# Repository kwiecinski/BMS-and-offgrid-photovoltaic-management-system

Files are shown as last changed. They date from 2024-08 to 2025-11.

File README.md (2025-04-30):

# Offgrid Photovoltaic Management System 
 ### Project contains:
 #### A. Power and mechanical part:

  1. [ Photovoltaic modules](#1-photovoltaic-modules)  
  2. [ Concrete base mounting](#2-concrete-base-mounting)  
  3. [ Metalworking and welding mounting bases and angle bar](#3-metalworking-and-welding-mounting-bases-and-angle-bar)  
  4. [ Painting mounting base, angle bars and perforated profiles](#4-painting-mounting-base-angle-bars-and-perforated-profiles)  
  5. [ PV mountings to perforated profiles](#5-pv-mountings-to-perforated-profiles)  
  6. [ Assembly of PV installation](#6-assembly-of-pv-installation)  
  7. [ Fully assembled PV installation](#7-fully-assembled-pv-installation)<br>
  8. [ Underground Cable Installation and Connection to the Building](#8-underground-cable-installation-and-connection-to-the-building)
 
B. [EASUN inverter - description, installation schematic and wiring](#easun-inverter---description-installation-and-wiring)
#### C. Managemenet system part:
- [BMS for lead-acid batteries](#bms-for-lead-acid-batteries) - equalize battery, protect from large charge/discharge currents, montors battery state (temp, voltage)
- [ESP32 Master module](#esp32-master-module) - it communicate with EASUN  converter, BMS, Homa Assistant, Energy Meters and sensor. Supervise all system work propertly.
- [Home Assistant integration](#home-assistant-integration) - integrate ESP Master module with HA for easy and compact managment (local and remote access)
- [Power Tracking module](#power-tracking-module) - it is used to regulate heater power accordingly to avaible energy from PV

## PV panels connection and DIY Ground Mount structure 

### 1. Photovoltaic modules
The photovoltaic modules I used in my PV installation are Trina Solar TSM-245. These are used panels that I purchased for around $40 each. The installation consists of 8 modules connected in series.

[📄 **Trina Solar TSM-245 datasheet**](docs/datasheets/TSM-PC05_trinasolar.pdf)

<table>
  <tr>
    <td align="center">
      <a href="docs\photos\ground-mount-structure\solar-panel-technical-data.jpg">
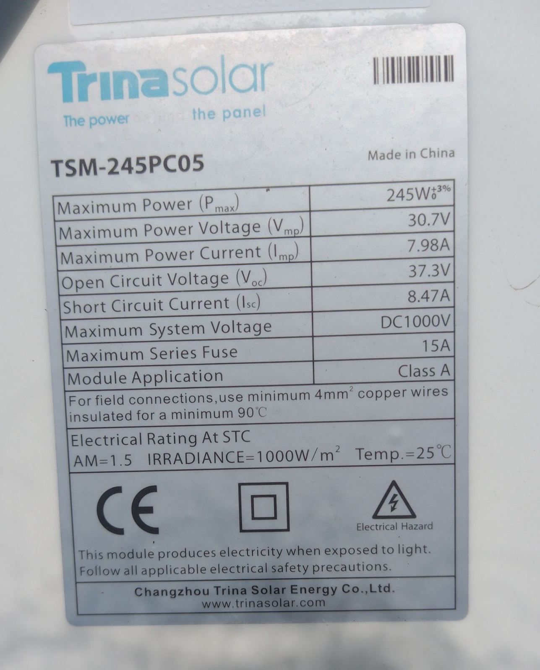
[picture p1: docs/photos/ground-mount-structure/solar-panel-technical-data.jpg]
        
      </a><br />
      <sub>PV module TSM-245 - technical data</sub>
    </td>
    <td align="center">
      <a href="docs\photos\ground-mount-structure\solar-panel-diodes.jpg">
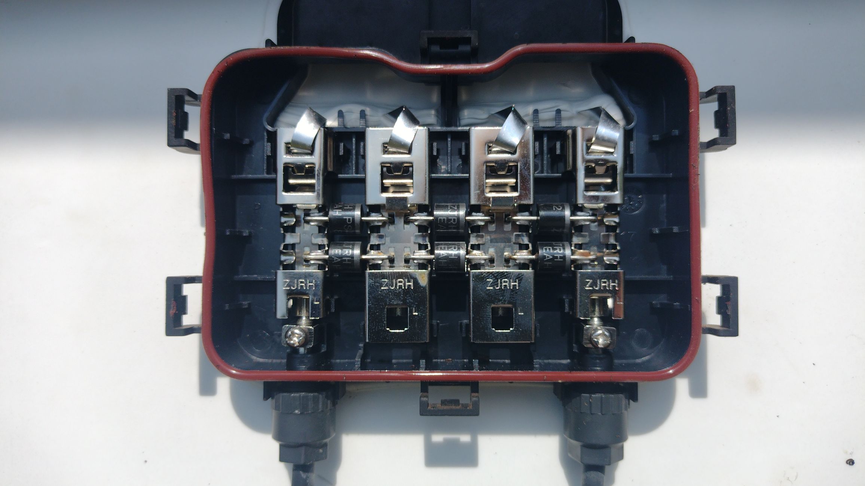
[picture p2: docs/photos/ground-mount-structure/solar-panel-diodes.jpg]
        
      </a><br />
      <sub>PV module TSM-245 - internal diode wiring</sub>
    </td>
  </tr>
</table>

<table>
  <tr>
    <td align="center">
      <a href="docs\photos\ground-mount-structure\solar-panel-front.jpg">
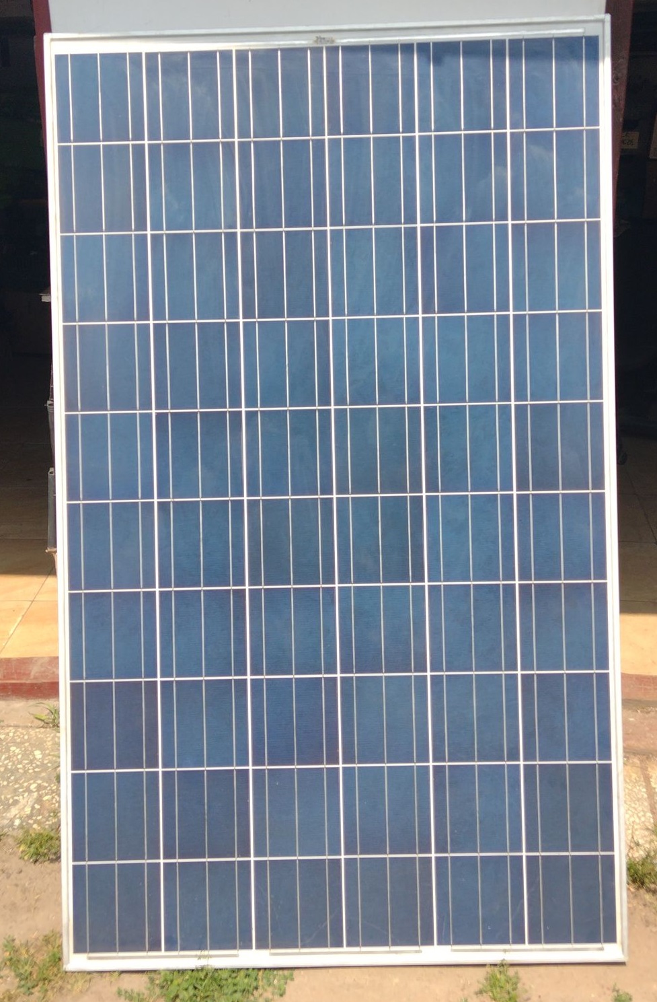
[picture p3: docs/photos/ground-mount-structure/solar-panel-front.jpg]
        
      </a><br />
      <sub>PV module TSM-245 - front</sub>
    </td>
    <td align="center">
      <a href="docs\photos\ground-mount-structure\solar-panel-back.jpg">
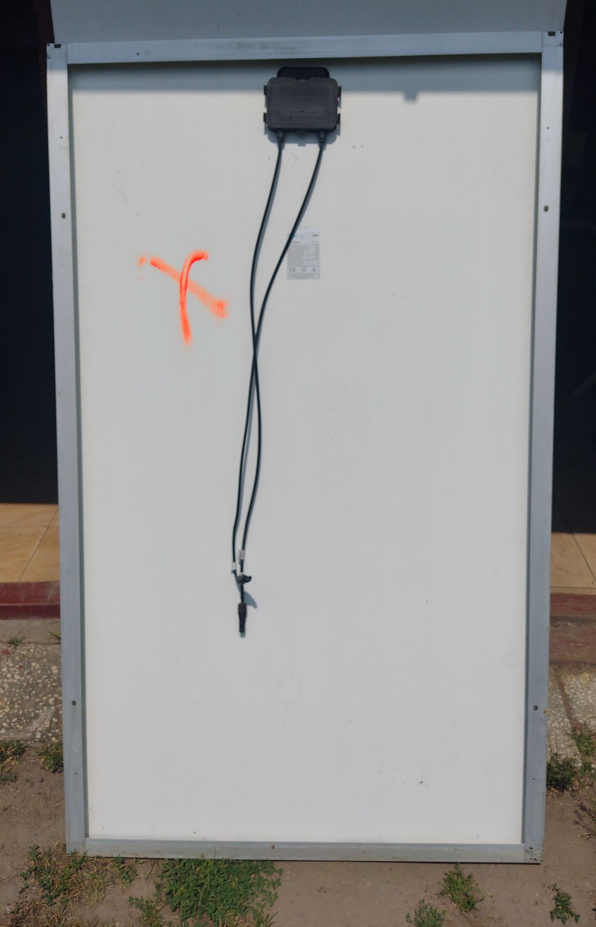
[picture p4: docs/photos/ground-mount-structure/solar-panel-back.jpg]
        
      </a><br />
      <sub>PV module TSM-245 - back</sub>
    </td>
  </tr>
</table>

The first stage was marking the mounting points for the mouting base structure. The entire construction has eight support points. After digging holes in the ground, they were filled with concrete, and concrete bases with reinforcement were embedded in them. I had plenty of these as production waste from the company where I work. They are typically used for mounting lightning protection masts on flat building roofs.

Inside each base, there is reinforcement and four M16 threads. I modified the bases by drilling holes on the opposite side, and I welded additional reinforcement to the bottom using scrap metal, which helps to improve the structural stability.

Before mounting the structure to the concrete bases, the contact surfaces were coated with a bituminous compound to prevent corrosion.

### 2. Concrete base mounting

<table>
  <tr>
    <td align="center" colspan="2">
      <a href="docs\photos\ground-mount-structure\concrete-fixing-with-reinforcement.jpg">
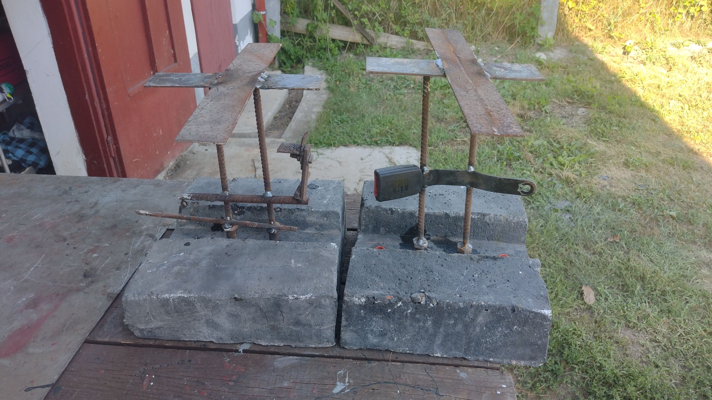
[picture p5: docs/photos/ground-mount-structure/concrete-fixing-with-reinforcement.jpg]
        
      </a><br />
      <sub>Concrete base with reinforcement</sub>
    </td>
  </tr>
  <tr>
    <td align="center">
      <a href="docs/photos/ground-mount-structure/concrete_base.jpg">
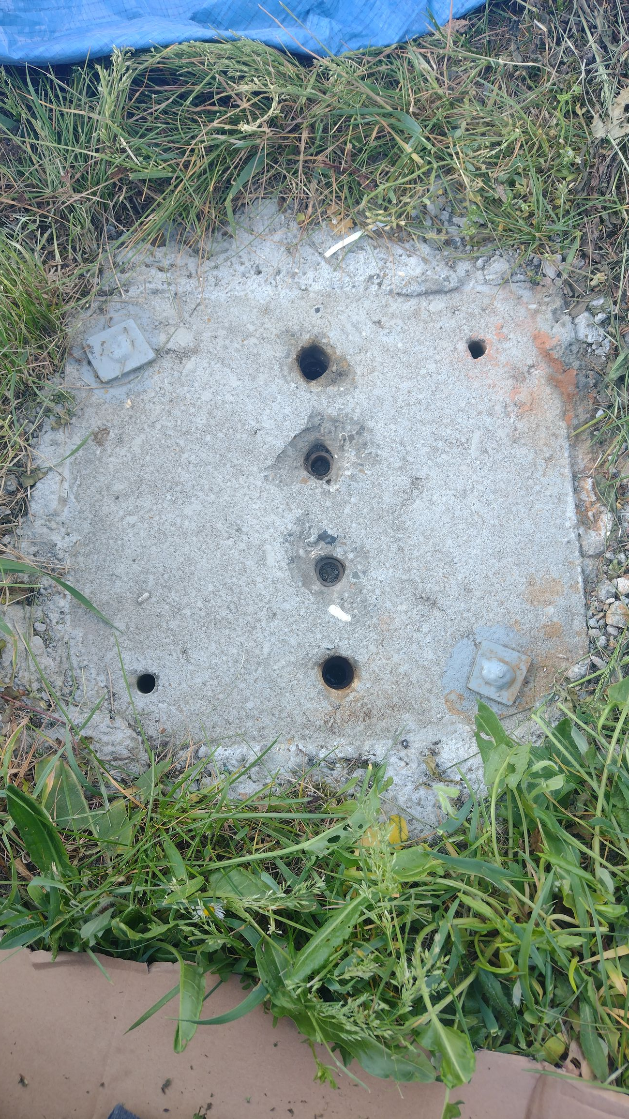
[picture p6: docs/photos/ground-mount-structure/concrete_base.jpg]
        
      </a><br />
      <sub>Concrete base with mounting thread</sub>
    </td>
    <td align="center">
      <a href="docs/photos/ground-mount-structure/concreete-with-bitumen.jpg">
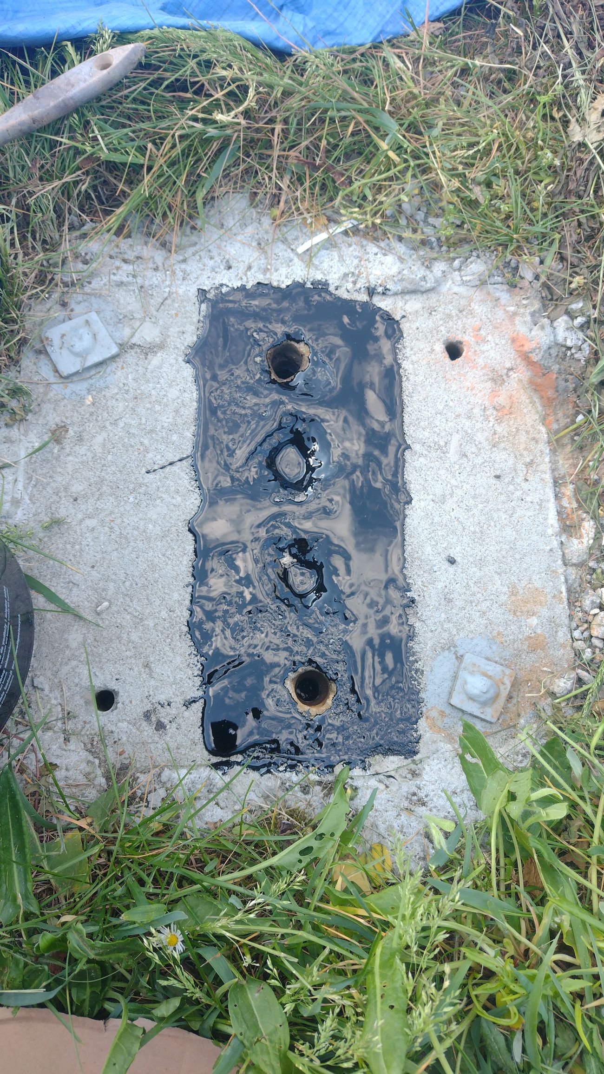
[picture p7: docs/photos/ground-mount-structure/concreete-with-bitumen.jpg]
        
      </a><br />
      <sub>Concrete base with bitumen</sub>
    </td>
  </tr>
</table>
<br>

Visible in the photo below is a set of four steel mounting bases of varying heights, with welded pipes and mounting plates. Each element was made with consideration for uneven ground, that is why there are different pipe lengths. Each base has a bottom plate with holes for M16 bolts, intended for anchoring to a concrete base. On the table next to them lies a long steel angle bar, which was welded from several sections. After welding, the elements were ground down. The photo was taken after the mechanical work was completed, during surface preparation for painting. 
All the steel used for building the PV mouting structure comes from scrap yard.

### 3. Metalworking and welding mounting bases and angle bar
<br>
<table>
  <tr>
    <td align="center" colspan="2">
      <a href="docs\photos\ground-mount-structure\steel-workshop-and-painting-12.jpg">
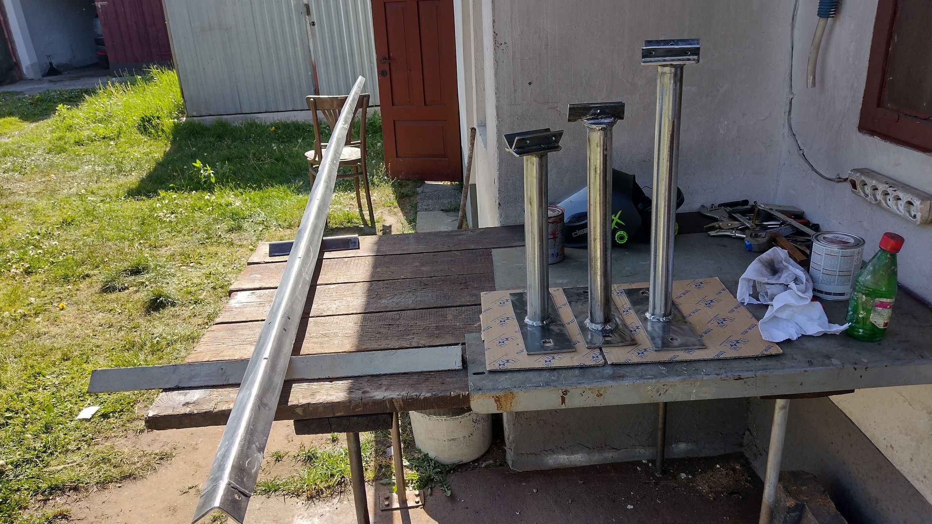
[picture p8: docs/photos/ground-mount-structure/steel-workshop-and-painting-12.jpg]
        
      </a><br />
      <sub>Metalworking and welding mounting bases and angle bar</sub>
    </td>
  </tr>
  <tr>
    <td align="center" colspan="2">
      <a href="docs\photos\ground-mount-structure\steel-workshop-and-painting-13.jpg">
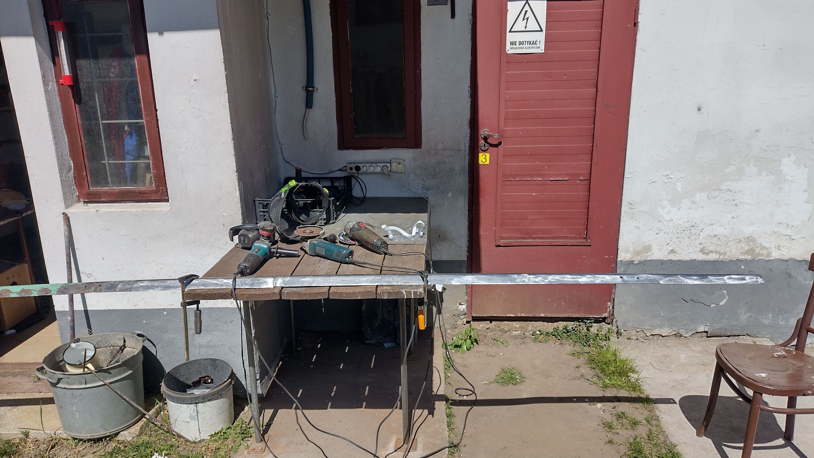
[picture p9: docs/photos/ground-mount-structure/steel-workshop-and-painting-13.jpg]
        
      </a><br />
      <sub>Steel angle bar before painting</sub>
    </td>
  </tr>
    <tr>
    <td align="center" colspan="2">
      <a href="docs\photos\ground-mount-structure\steel-workshop-and-painting-14.jpg">
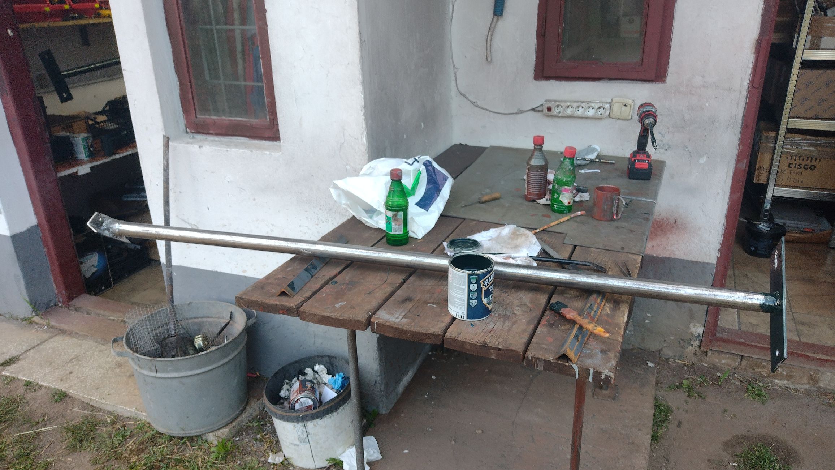
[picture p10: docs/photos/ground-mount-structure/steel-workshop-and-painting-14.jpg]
        
      </a><br />
      <sub>Longer mounting base  while painting</sub>
    </td>
  </tr>
</table>

Longer mounting base are responsible for the solar incidence angle which in this case is 40 degrees
### 4. Painting mounting base, angle bars and perforated profiles
<table>
  <tr>
    <td align="center" colspan="2">
      <a href="docs\photos\ground-mount-structure\steel-workshop-and-painting-11.jpg">
        
      <div style="width: 200px;">
        <a href="docs/photos/ground-mount-structure/steel-workshop-and-painting-11.jpg">
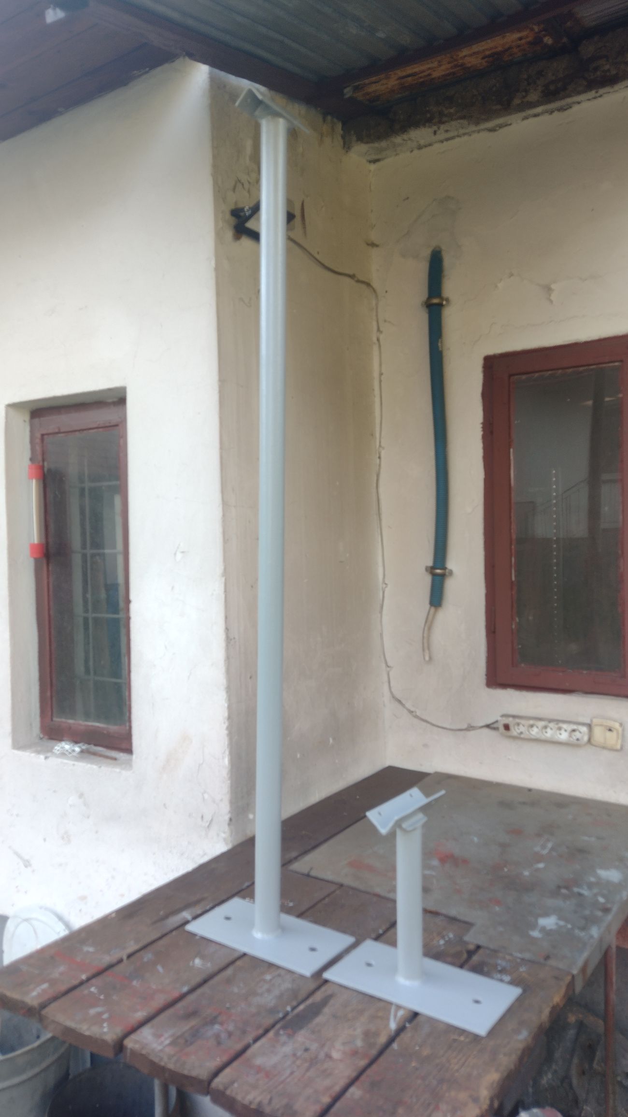
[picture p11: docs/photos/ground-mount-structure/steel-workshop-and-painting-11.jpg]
          
        </a>
        <div style="text-align: center;">
          <sub>Shorter and longer mounting base after painting</sub>
        </div>
      </div>
    </td>
  </tr>
  <tr>
    <td colspan="2" style="text-align: left;">
      <div style="width: 410px;">
        <a href="docs/photos/ground-mount-structure/steel-workshop-and-painting-10.jpg">
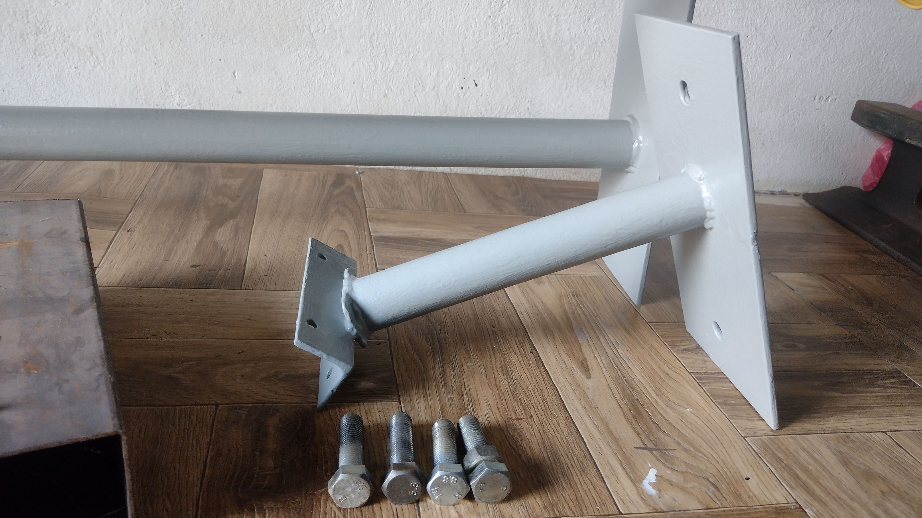
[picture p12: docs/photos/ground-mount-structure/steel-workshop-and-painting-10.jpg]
          
        </a>
        <div style="text-align: center;">
          <sub>Shorter mounting base after painting</sub>
        </div>
      </div>
    </td>
  </tr>
  <tr>
    <td colspan="2" style="text-align: left;">
      <div style="width: 410px;">
        <a href="docs/photos/ground-mount-structure/steel-workshop-and-painting-01.jpg">
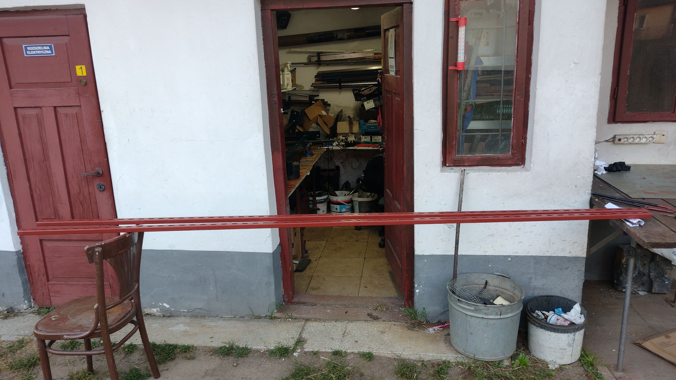
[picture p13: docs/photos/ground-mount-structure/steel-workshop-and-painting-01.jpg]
          
        </a>
        <div style="text-align: center;">
          <sub>Perforated profiles, often used for fixing cable tray systems, <br>turned out to be ideal as internal panel brackets. <br>Since they are galvanized, they must be painted <br>with zinc-compatible paint.</sub>
        </div>
      </div>
    </td>
  </tr>
  <tr>
    <td colspan="2" style="text-align: left;">
      <div style="width: 410px;">
        <a href="docs/photos/ground-mount-structure/steel-workshop-and-painting-02.jpg">
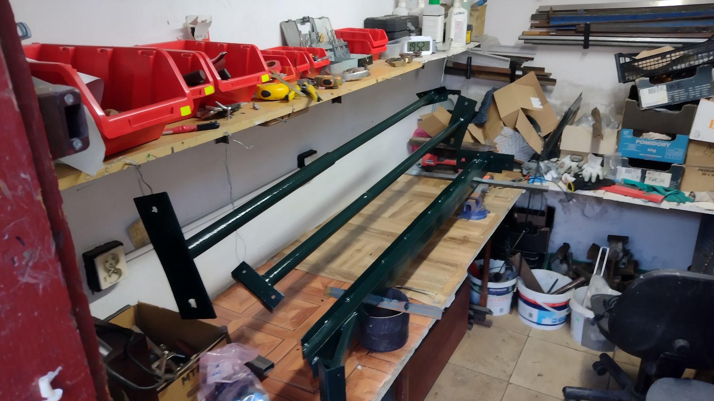
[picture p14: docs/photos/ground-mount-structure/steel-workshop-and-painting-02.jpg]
          
        </a>
        <div style="text-align: center;">
          <sub>Longer mounting bases drying after painting</sub>
        </div>
      </div>
    </td>
  </tr>
</table>

### 5. PV Mountings to perforated profiles

<table>
  <tr>
    <td colspan="2" style="text-align: left;">
      <div style="width: 410px;">
        <a href="docs/photos/ground-mount-structure/steel-workshop-and-painting-03.jpg">
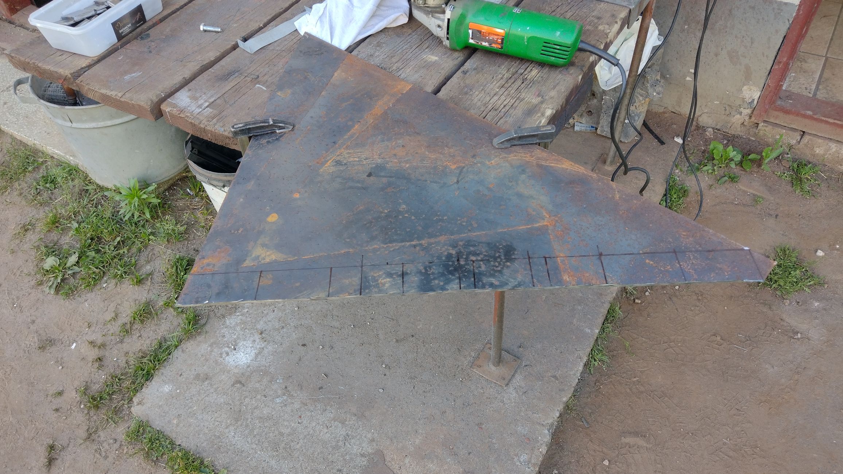
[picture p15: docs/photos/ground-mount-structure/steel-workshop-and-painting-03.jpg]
          
        </a>
        <div style="text-align: center;">
          <sub>Sheet metal used to prepare panel mounts for perforated profiles</sub>
        </div>
      </div>
    </td>
  </tr>

  <tr>
    <td colspan="2" style="text-align: left;">
      <div style="width: 410px;">
        <a href="docs/photos/ground-mount-structure/steel-workshop-and-painting-04.jpg">
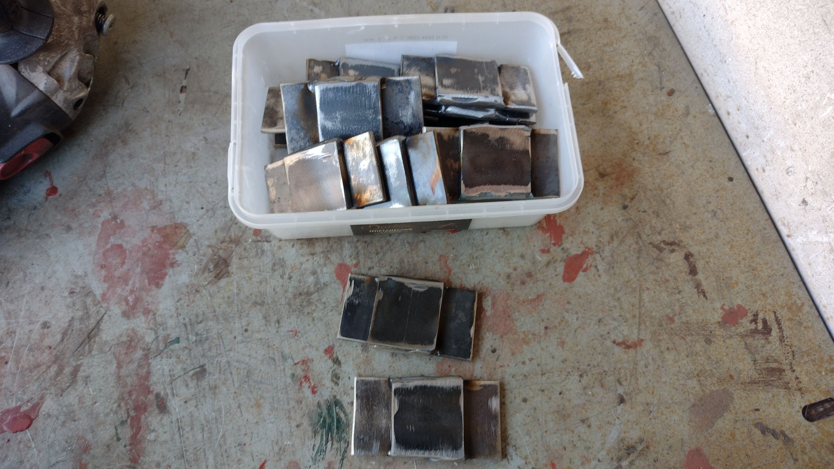
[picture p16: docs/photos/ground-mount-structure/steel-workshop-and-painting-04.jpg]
          
        </a>
        <div style="text-align: center;">
          <sub>Panel mounts for perforated profiles before welding and drilling</sub>
        </div>
      </div>
    </td>
  </tr>

  <tr>
    <td colspan="2" style="text-align: left;">
      <div style="width: 410px;">
        <a href="docs/photos/ground-mount-structure/steel-workshop-and-painting-05.jpg">
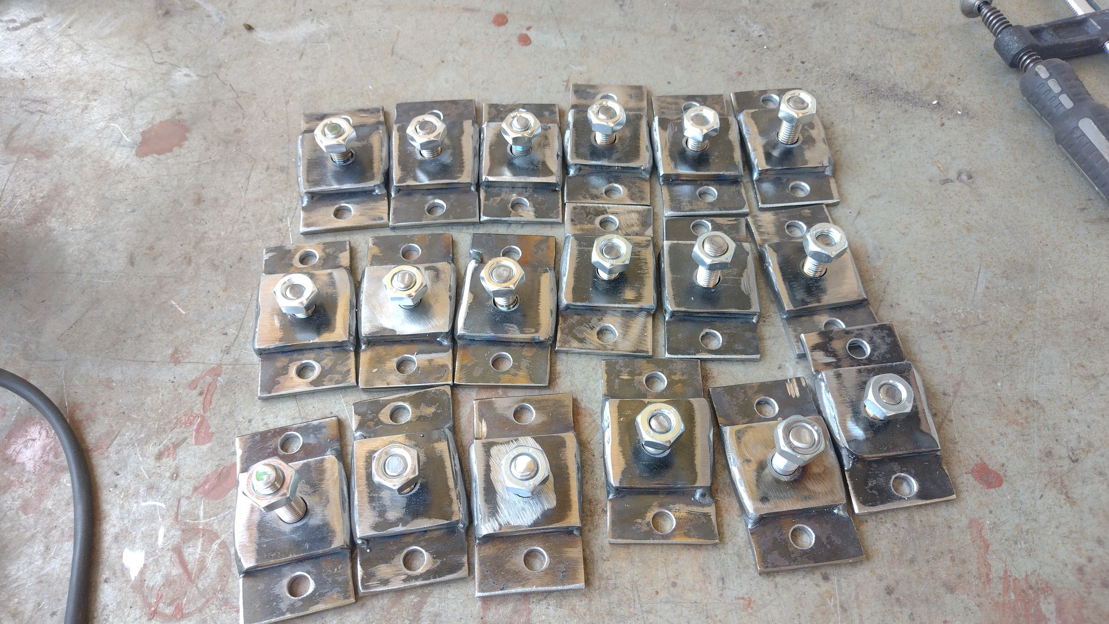
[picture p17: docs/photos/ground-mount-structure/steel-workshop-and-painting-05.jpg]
          
        </a>
        <div style="text-align: center;">
          <sub>Panel mounts for perforated profiles. The central M10 bolt is used to attach to the perforated profile, and the two M8 holes are for screwing PV panels</sub>
        </div>
      </div>
    </td>
  </tr>

  <tr>
    <td colspan="2" style="text-align: left;">
      <div style="width: 410px;">
        <a href="docs/photos/ground-mount-structure/steel-workshop-and-painting-06.jpg">
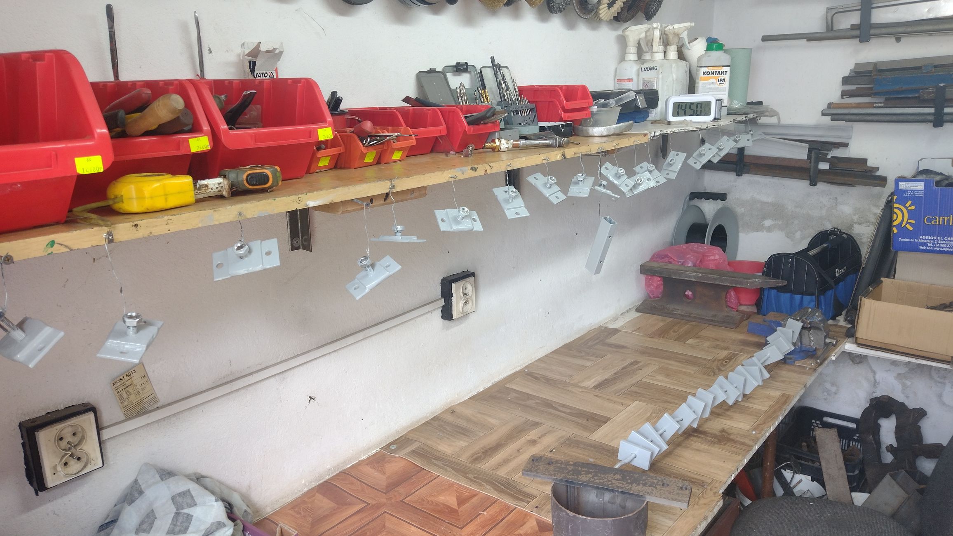
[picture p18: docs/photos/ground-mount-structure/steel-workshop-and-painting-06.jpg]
          
        </a>
        <div style="text-align: center;">
          <sub>Solar panel mounting elements after painting, drying in progress</sub>
        </div>
      </div>
    </td>
  </tr>

  <tr>
    <td colspan="2" style="text-align: left;">
      <div style="width: 410px;">
        <a href="docs/photos/ground-mount-structure/steel-workshop-and-painting-07.jpg">
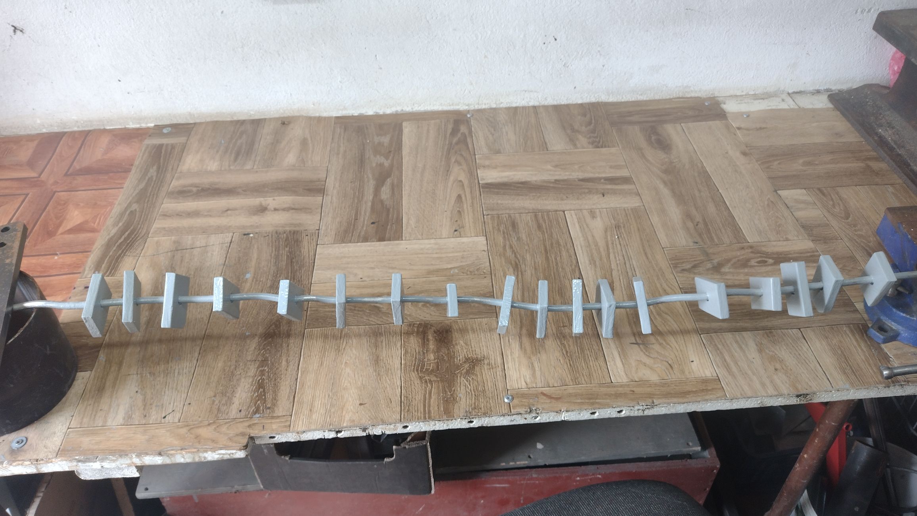
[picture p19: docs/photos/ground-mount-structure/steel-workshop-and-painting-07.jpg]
          
        </a>
        <div style="text-align: center;">
          <sub>Spacer for mounting solar panels to the perforated panels which are on the outer side of mounting structure</sub>
        </div>
      </div>
    </td>
  </tr>

  <tr>
    <td colspan="2" style="text-align: left;">
      <div style="width: 410px;">
        <a href="docs/photos/ground-mount-structure/steel-workshop-and-painting-08.jpg">
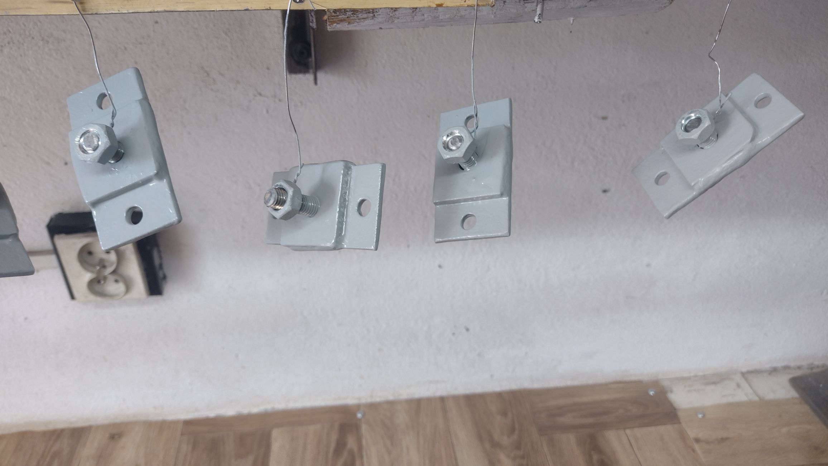
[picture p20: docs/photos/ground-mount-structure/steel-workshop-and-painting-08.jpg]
          
        </a>
        <div style="text-align: center;">
          <sub>Solar panel mounts for perforated profiles – painted and drying</sub>
        </div>
      </div>
    </td>
  </tr>

  <tr>
    <td colspan="2" style="text-align: left;">
      <div style="width: 410px;">
        <a href="docs/photos/ground-mount-structure/steel-workshop-and-painting-08.jpg">
          
        </a>
        <div style="text-align: center;">
          <sub>Solar panel mounts for perforated profiles</sub>
        </div>
      </div>
    </td>
  </tr>
</table>

### 6. Assembly of PV installation
<table>
  <tr>
    <td colspan="2" style="text-align: left;">
      <div style="width: 410px;">
        <a href="docs/photos/ground-mount-structure/assembly-01.jpg">
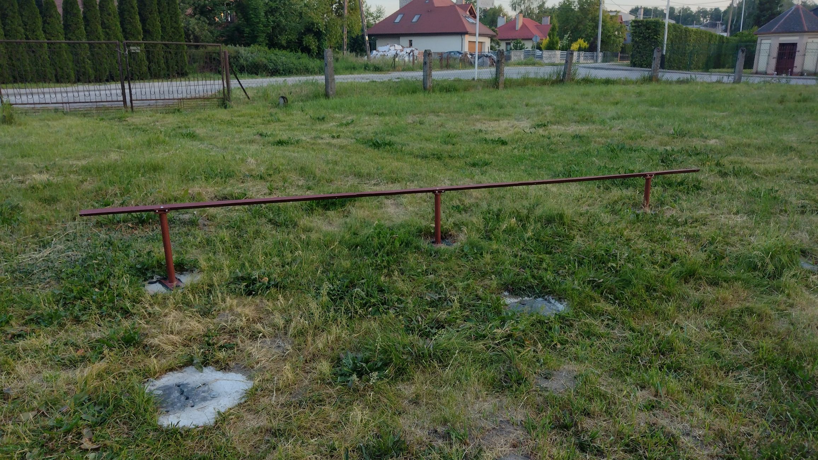
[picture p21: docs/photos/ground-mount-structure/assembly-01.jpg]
          
        </a>
        <div style="text-align: center;">
          <sub>Shorter mounting bases and angle bar mounted on concrete bases. Thanks to the height difference of the mounting bases, the angle bar remains level</sub>
        </div>
      </div>
    </td>
  </tr>
  <tr>
    <td colspan="2" style="text-align: left;">
      <div style="width: 410px;">
        <a href="docs/photos/ground-mount-structure/assembly-02.jpg">
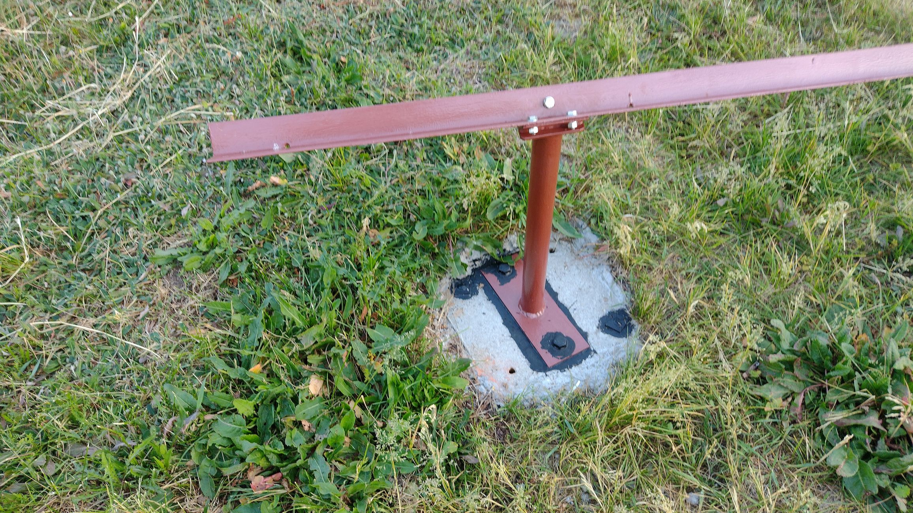
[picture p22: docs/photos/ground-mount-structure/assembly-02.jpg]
          
        </a>
        <div style="text-align: center;">
          <sub>Shorter mounting base mounted on a concrete base. Before installation, the base was coated with a bituminous compound. Stainless steel bolts were used for assembly</sub>
        </div>
      </div>
    </td>
  </tr>
  <tr>
    <td colspan="2" style="text-align: left;">
      <div style="width: 410px;">
        <a href="docs/photos/ground-mount-structure/assembly-03.jpg">
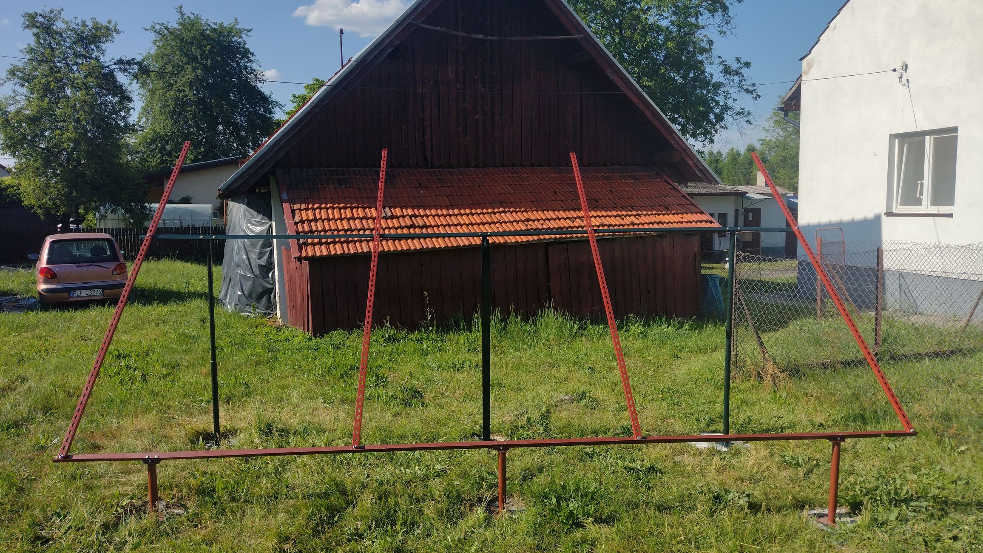
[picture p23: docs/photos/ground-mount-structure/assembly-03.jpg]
          
        </a>
        <div style="text-align: center;">
          <sub>Ground mounting structure ready for PV panel installation</sub>
        </div>
      </div>
    </td>
  </tr>
  <tr>
    <td colspan="2" style="text-align: left;">
      <div style="width: 200px;">
        <a href="docs/photos/ground-mount-structure/assembly-04.jpg">
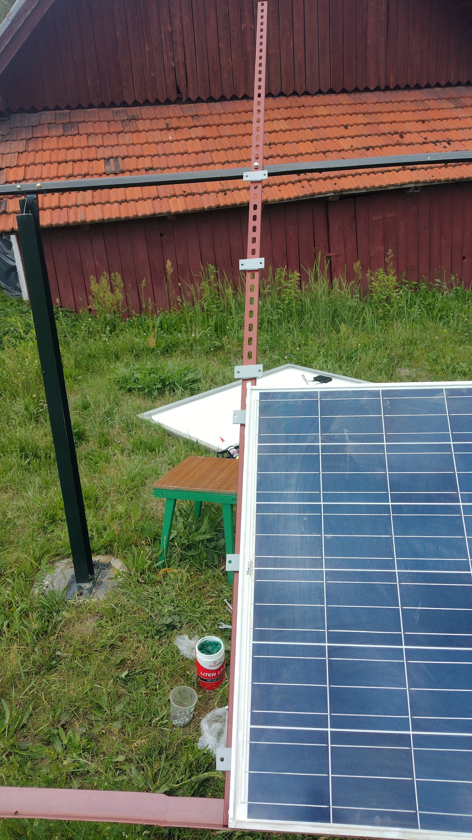
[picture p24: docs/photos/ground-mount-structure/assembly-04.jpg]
          
        </a>
        <div style="text-align: center;">
          <sub>Here you can see how the panel mounts are used to connect solar panel with perforated profile</sub>
        </div>
      </div>
    </td>
  </tr>
</table>

### 7. Fully assembled PV installation
<table>
    <tr>
    <td align="center" colspan="2">
      <a href="docs\photos\ground-mount-structure\full-assembled-panel-front.jpg">
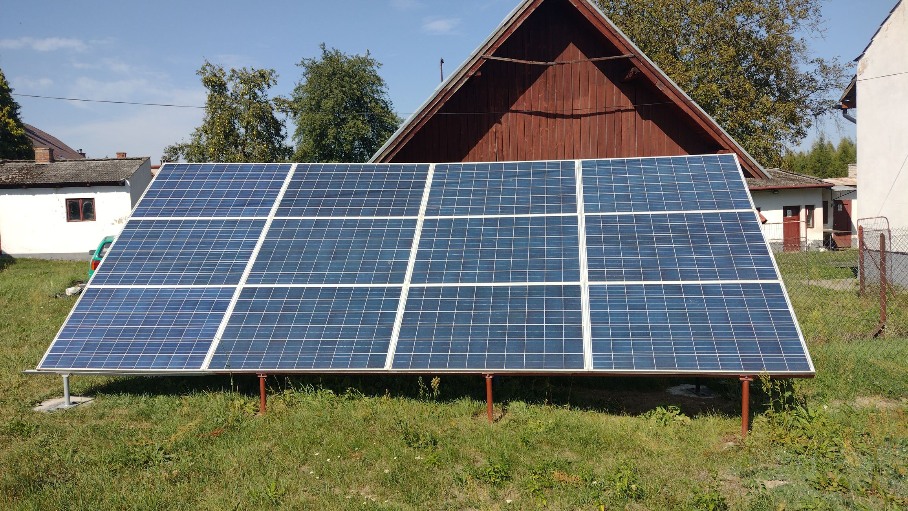
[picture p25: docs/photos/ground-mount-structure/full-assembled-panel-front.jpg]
        
      </a><br />
      <sub>Fully assembled PV installation - front</sub>
    </td>
  </tr>
    </tr>
    <tr>
    <td align="center" colspan="2">
      <a href="docs\photos\ground-mount-structure\full-assembled-panel-back.jpg">
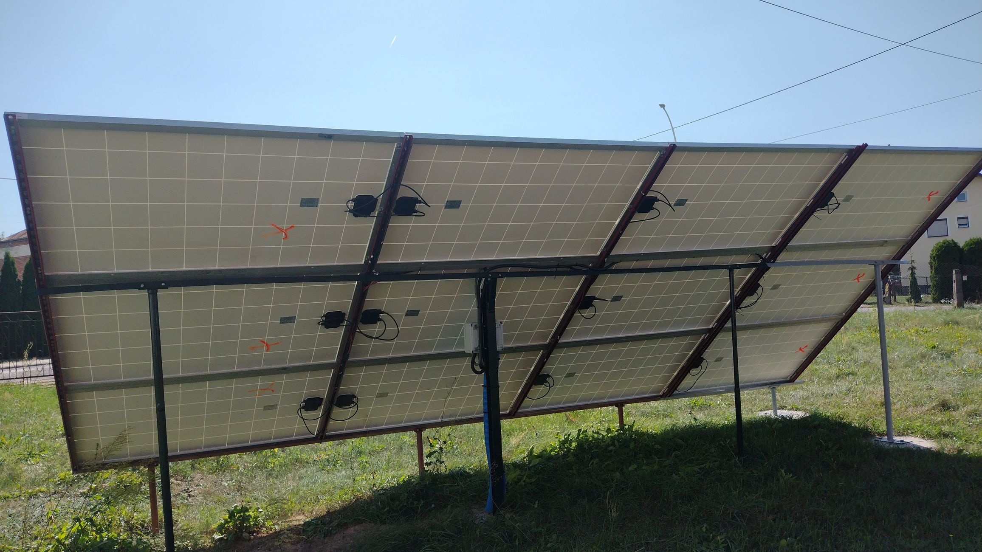
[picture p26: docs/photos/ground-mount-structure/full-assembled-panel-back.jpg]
        
      </a><br />
      <sub>Fully assembled PV installation - back<sub>
    </td>
  </tr>
</table>

### 8. Underground Cable Installation and Connection to the Building
To connect the panels, I used AsXSn 4x35 cable and additionally laid an AsXSn 4x25 cable. I found these cables at a scrapyard at a good price, which is why I chose this somewhat unconventional option. Additionally, I installed a gel-filled Ethernet twisted pair cable to allow for potential data transmission if needed.

<table>
  <tr>
    <td align="center">
      <a href="docs/photos/ground-mount-structure/cable-routes-02.jpg">
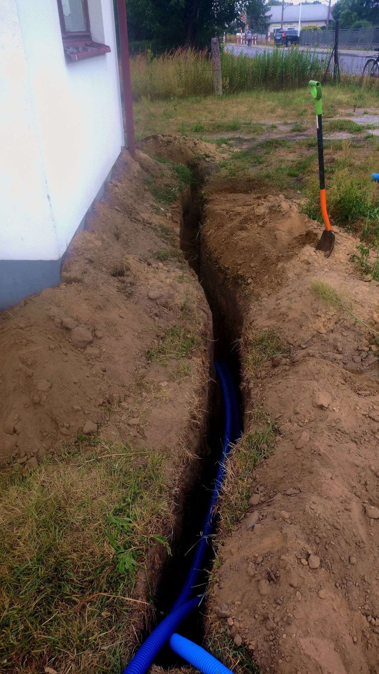
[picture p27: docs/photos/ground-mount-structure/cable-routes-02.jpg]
        
      </a><br />
      <div style="max-width: 200px; text-align: center;">
        <sub>Underground cable entry to the building</sub>
      </div>
    </td>
  </tr>

  <tr>
    <td align="center" valign="top">
      <a href="docs/photos/ground-mount-structure/cable-routes-05.jpg">
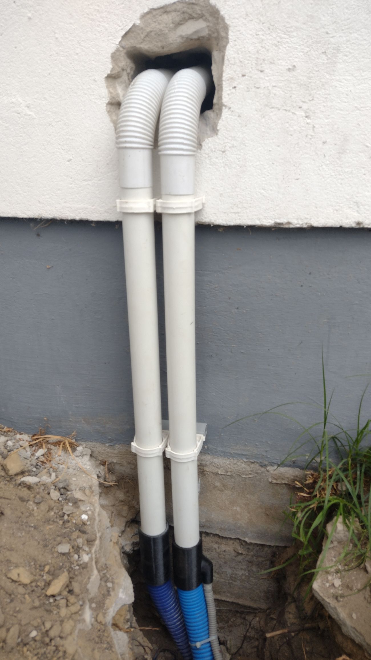
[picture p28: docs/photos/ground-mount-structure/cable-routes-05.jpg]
        
      </a><br />
      <div style="max-width: 200px; text-align: center;">
        <sub>Cable entry point inside the building</sub>
      </div>
    </td>
    <td align="center" valign="top">
      <a href="docs/photos/ground-mount-structure/cable-routes-06.jpg">
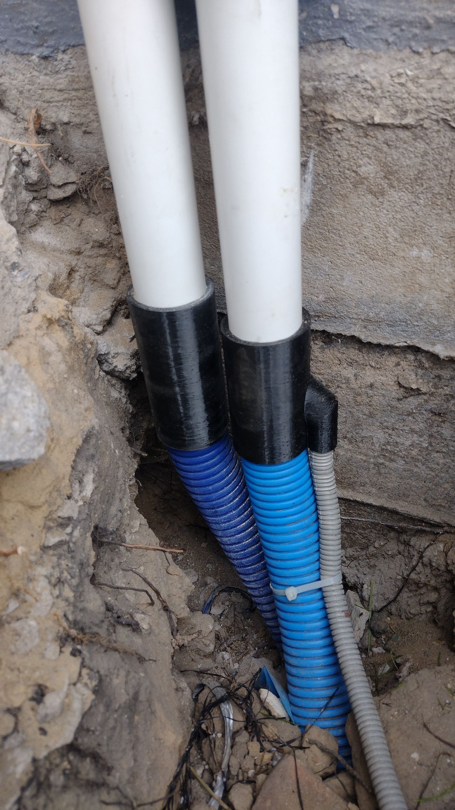
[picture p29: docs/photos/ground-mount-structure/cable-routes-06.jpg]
        
      </a><br />
      <div style="max-width: 200px; text-align: center;">
        <sub>Close-up of the conduit connection and grounding wire</sub>
      </div>
    </td>
  </tr>
</table>

To connect the AROT 50 (blue) protective pipe with the RL50 pipe (white), I created an adapter using a 3D printer. PETG material was chosen for its weather resistance. The opening in adapter was designed to fit the protective pipe only after heating the adapter. Once cooled, the adapter holds the pipe in place.

<table>
  <tr>
    <td align="center" colspan="2">
      <a href="docs/photos/ground-mount-structure/cable-routes-connector.jpg">
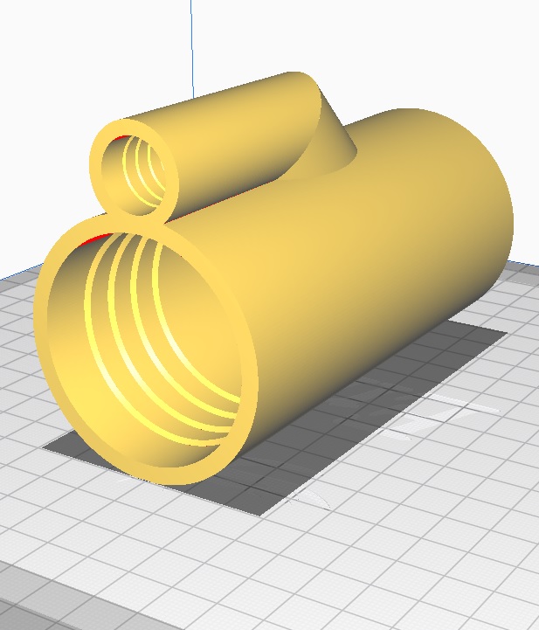
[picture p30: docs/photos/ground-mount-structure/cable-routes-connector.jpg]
        
      </a><br/>
      <sub>Adapter 3D model</sub>
    </td>
  </tr>

  <tr>
    <td align="center">
      <a href="docs/photos/ground-mount-structure/cable-routes-03.jpg">
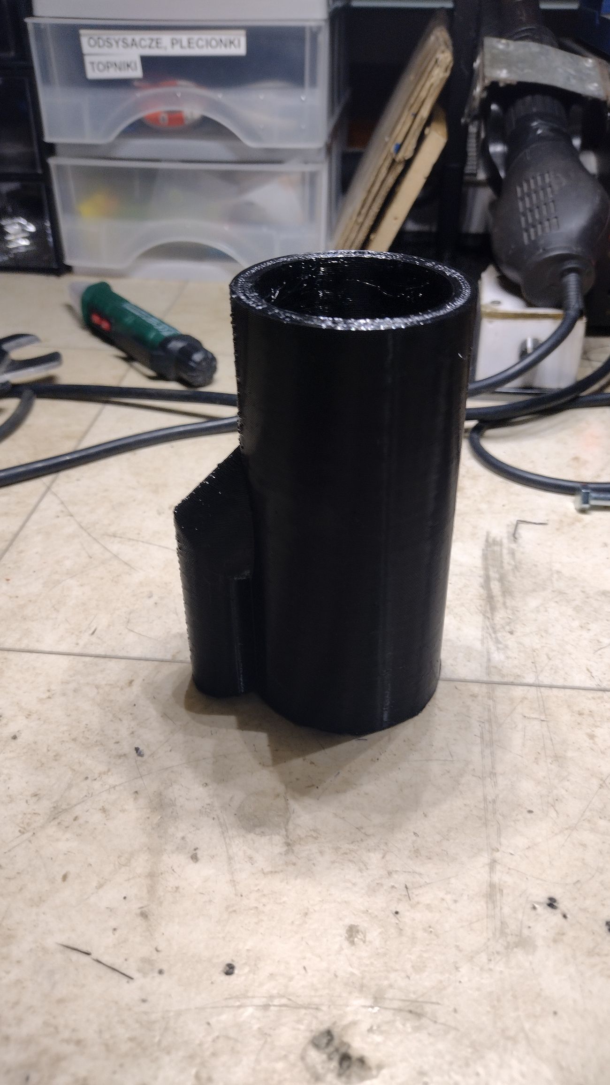
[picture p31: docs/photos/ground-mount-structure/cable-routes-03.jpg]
        
      </a><br/>
      <sub>Adapter after printing</sub>
    </td>
    <td align="center ">
      <a href="docs/photos/ground-mount-structure/cable-routes-04.jpg">
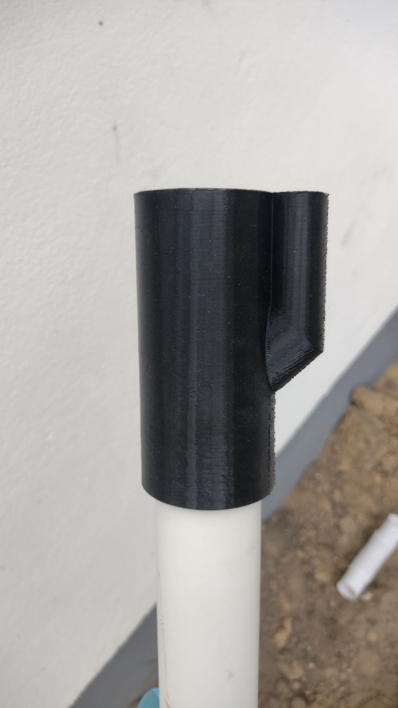
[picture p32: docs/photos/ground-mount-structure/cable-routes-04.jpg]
        
      </a><br/>
      <sub>Adapter mounted on protective pipe</sub>
    </td>
  </tr>

  <tr>
    <td align="center" colspan="2">
      <a href="docs/photos/ground-mount-structure/cable-routes-08.jpg">
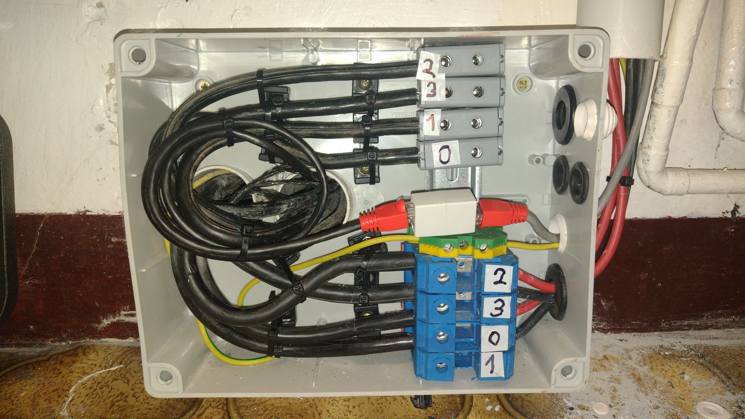
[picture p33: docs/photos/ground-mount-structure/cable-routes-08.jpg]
        
      </a><br />
      <sub>Junction box inside the building.<br> Visible screw terminals for two cables, twisted pair Ethernet connection, <br>and additional grounding.</sub>
    </td>
  </tr>
    <tr>
    <td align="center" colspan="2">
      <a href="docs/photos/ground-mount-structure/cable-routes-10.jpg">
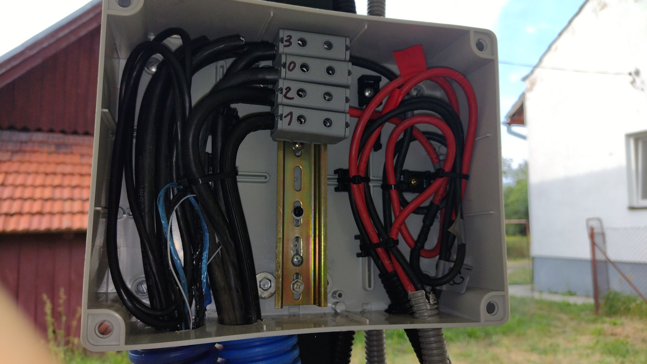
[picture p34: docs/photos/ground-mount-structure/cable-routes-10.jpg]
        
      </a><br />
      <sub>Junction box at the PV installation site.</sub>
    </td>
  </tr>
</table>

## EASUN inverter - Description, installation and wiring

[📄 **EASUN ISolar SMG II 4kW datasheet**](docs/ISolar-SMG-II-4KW-WiFi.pdf) <br><br>
The EASUN ISolar SMG II 4kW is an off-grid inverter. It does not have the capability to synchronize with the power grid.

Inverter specifications:
- Input voltage from PV array: 60-500V DC
- Input current from PV array: 15A
- Output voltage: 230V/50Hz
- Battery voltage: 24V
- Battery current: max 100A

In my case, 12 PV were connected, each with a maximum voltage of 37V, resulting in a maximum voltage of approximately 440V.

The maximum current of the PV array is 8A.  
Connected PV array meet the inverter's specifications.

Power Source Priority

| Option | Description |
|---|---|
| SOL | The inverter uses solar energy to power the loads. If solar energy is insufficient to meet the load demand, the battery **only supplements** the power. The grid supplies power to the loads only when: Solar energy is unavailable (e.g., at night or during heavy cloud cover). Battery voltage drops to the low-level warning voltage or the threshold set in Program 12.|
| UFI  | Utility will provide power to the loads as first priority. Solar and battery energy will provide power to the loads only when utility power is notavailable.|
| SBU  | The inverter uses solar energy to power the loads. If solar energy is insufficient, the battery provides power to the loads. The grid supplies power to the loads only when the battery voltage drops to the low-level warning voltage or the threshold set in Program 12. |
| SUB  | Solar energy is charged first and then power to the loads. If solar energy is not sufficient to power all connected loads, Utility energy will supply power to the loads at the same time. <br>**Attention**: I found that there is an idle power (about 150W) that must be drawn from the grid before parallel operation of the grid + solar energy can occur. This means that if the power consumption is up to 150W, it will not be supplied by solar energy but by the grid. If power consumption is over 150W eg. 500W then 350W will we drawn from solar and still 150W will be drawn from grid.|

Key Differences between SOL and SBU is battery usage:

SOL Mode: The battery assists only when solar energy is insufficient, and the grid is used if both solar and battery cannot meet the load. 

SBU Mode: The battery is used after solar, and the grid is used only when the battery is depleted.

<a href="electrical/schematic.png">
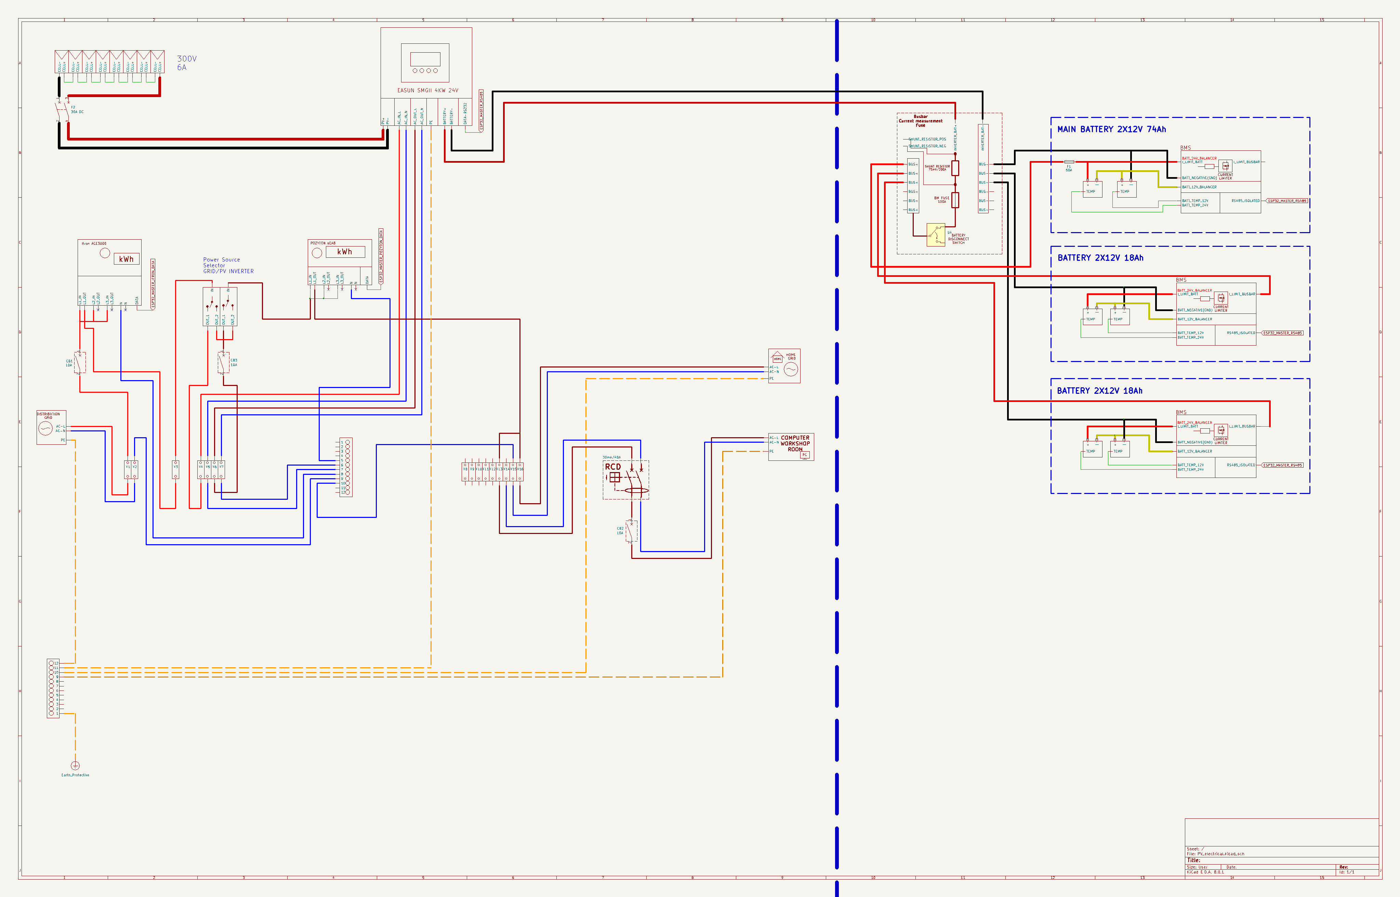
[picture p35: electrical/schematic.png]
        </a>

# Management System diagram:

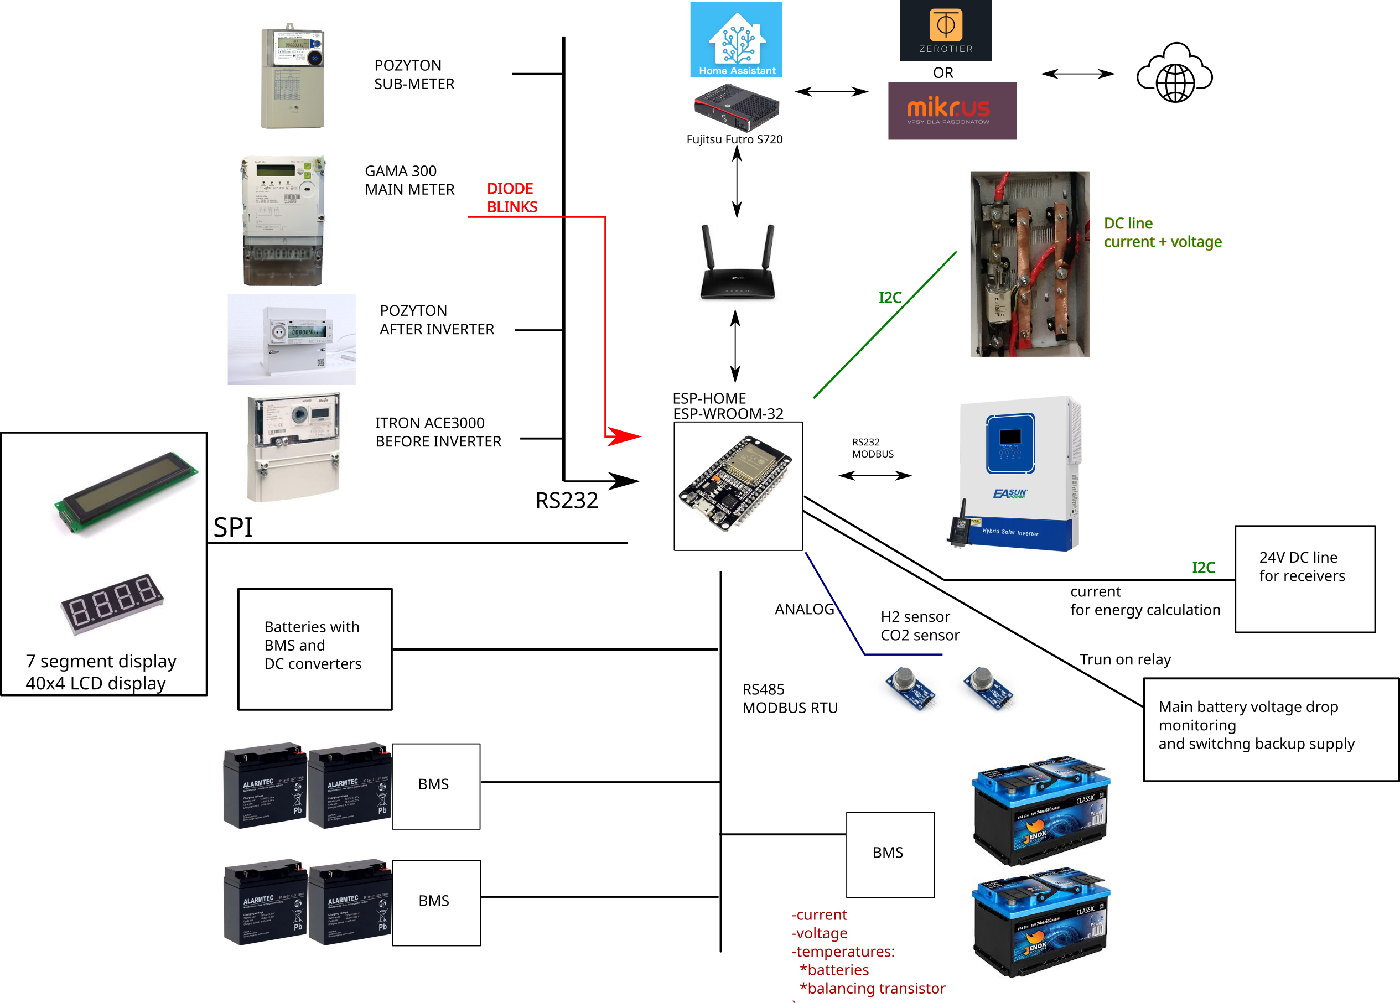
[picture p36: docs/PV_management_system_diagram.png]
System Diagram


## BMS for lead-acid batteries
BMS have several tasks:
- Battery Balancer equalizes the state of charge of two series connected 12V batteries. If one of battery is overcharged it discharge it using resistor.
- Bidirectional DC-DC converter - protect battery from too much discharge or charge current
- Battery monitoring - measurment of temperature of each battery and voltage.

The BMS is controlled by an AVR64DD28 microcontroller. To program it, you need a programmer that supports UPDI.
I'm using SerialUPDI (a modified version with high-voltage programming capability and galvanic isolation, which you can find here: SerialUPDI link).

To measure battery voltage and current, I use the INA226 sensor along with the built-in ADC of the microcontroller.

The INA226 measures:

- The voltage of the entire battery pack, split into BATT_LOW (bottom battery) and BATT_HIGH (top battery)

- The voltage across a shunt resistor, used to measure the current flowing through the entire pack

Since the INA226 is bidirectional, it allows both charging and discharging current measurements.

The microcontroller’s ADC measures only BATT_LOW voltage.
By subtracting the ADC reading from the INA226’s total voltage reading, I can calculate the BATT_HIGH voltage.

Cell balancing is performed using high-power resistors, each connected in parallel with a battery cell.
Each resistor is switched by a MOSFET, which is controlled by the MCU using PWM.

PWM is hardware-generated using the TCD timer, which controls two outputs: WOA and WOB, each assigned to a specific MCU pin.

The TCD timer is capable of generating...

## ESP32 Master module

## Home Assistant integration

## Power Tracking module

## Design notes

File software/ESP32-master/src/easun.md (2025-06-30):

## Protocol

The protocol is Modbus RTU via RS232.

| Description | Unit |  Res  | Addr | Len | R/W | Values |
| ---: | ---: |  ---: | :--: | :-: | :-: | :----- |
| Fault code | | ULong |  100 |  2  |  R  | |
| Warning code | | ULong |  108 |  2  |  R  | |
| Serial number | | Ascii |  186 | 12  |  R  | |
| Operation Mode | |  UInt |  201 |  1  |  R  | 0: Power On<br>1: Standby<br>2: Mains<br>3: Off-Grid<br>4: Bypass<br>5: Charging<br>6: Fault |
| Effective mains voltage |  0.1V |  Int  |  202 |  1  |  R  | |
| Mains Frequency |  0.01Hz  |  Int  |  203 |  1  |  R  | |
| Average mains power |  1W |  Int  |  204 |  1  |  R  | |
| Effective inverter voltage |  0.1V |  Int  |  205 |  1  |  R  | |
| Effective inverter current |  0.1A |  Int  |  206 |  1  |  R  | |
| Inverter frequency |  0.01Hz  |  Int  |  207 |  1  |  R  | |
| Average inverter power |  1W |  Int  |  208 |  1  |  R  | Positive numbers indicate inverter output<br>Negative numbers indicate inverter input |
| Inverter charging power |  1W |  Int  |  209 |  1  |  R  | |
| Output effective voltage |  0.1V |  Int  |  210 |  1  |  R  | |
| Output effective Current |  0.1A |  Int  |  211 |  1  |  R  | |
| Output frequency |  0.01Hz  |  Int  |  212 |  1  |  R  | |
| Output active power |  1W |  Int  |  213 |  1  |  R  | |
| Output apparent power |  1VA |  Int  |  214 |  1  |  R  | |
| Battery average voltage |  0.1V |  Int  |  215 |  1  |  R  | |
| Battery average Current |  0.1A |  Int  |  216 |  1  |  R  | |
| Battery average power |  1W |  Int  |  217 |  1  |  R  | |
| PV average voltage |  0.1V |  Int  |  219 |  1  |  R  | |
| PV average Current |  0.1A |  Int  |  220 |  1  |  R  | |
| PV average power |  1W |  Int  |  223 |  1  |  R  | |
| PV charging average power |  1W |  Int  |  224 |  1  |  R  | |
| Load percentage |  1% |  Int  |  225 |  1  |  R  | |
| DCDC Temperature |  1°C |  Int  |  226 |  1  |  R  | |
| Inverter Temperature |  1°C |  Int  |  227 |  1  |  R  | |
| Battery state of charge |  1% |  UInt |  229 |  1  |  R  | |
| Battery average current |  0.1A |  Int  |  232 |  1  |  R  | Positive number means charging<br>Negative number means discharging |
| Inverter charging average current |  0.1A |  Int  |  233 |  1  |  R  | |
| PV charging average current |  0.1A |  Int  |  234 |  1  |  R  | |
| Output Mode | |  Uint |  300 |  1  | R/W | 0: Single<br>1: Parallel<br>2: 3 Phase-P1<br>3: 3 Phase-P2<br>4: 3 Phase-P3 |
| Output priority | |  Uint |  301 |  1  | R/W | 0: Utility-PV-Battery<br>1: PV-Utility-Battery<br>2: PV-Battery-Utility  |
| Input voltage range | |  Uint |  302 |  1  | R/W | 0: Wide range<br>1: Narrow range |
| Buzzer mode | |  Uint |  303 |  1  | R/W | 0: Mute in all situations<br>1: Sound when the input source is changed or there is a specific warning or fault<br>2: Sound when there is aspecific warning or fault<br>3: Sound when fault occurs |
| LCD backlight | |  Uint |  305 |  1  | R/W | 0: Timed off<br>1: Always on |
| LCD automatically returns to the homepage | |  Uint |  306 |  1  | R/W | 0: Do not return automatically<br>1: Automatically return after 1 minute |
| Energy-saving mode | |  Uint |  307 |  1  | R/W | 0: Energy-saving mode is off<br>1: Energy-saving mode is on |
| Overload automatic restart | |  Uint |  308 |  1  | R/W | 0: Overload failure will not restart<br>1: Automatic restart after overload failure |
| Over temperature automatic restart | |  Uint |  309 |  1  | R/W | 0: Over temperature failure will not restart<br>1: Automatic restart after over-temperature fault |
| Overload transfer to bypass enabled | |  Uint |  310 |  1  | R/W | 0: Disable<br>1: Enable |
| Battery Eq mode is enabled | |  Uint |  313 |  1  | R/W | 0: Disable<br>1: Enable |
| Output voltage |  0.1V |  Uint |  320 |  1  | R/W | |
| Output frequency |  0.01Hz  |  Uint |  321 |  1  | R/W | |
| Battery overvoltage protection point |  0.1V |  Uint |  323 |  1  | R/W | |
| Max charging voltage |  0.1V |  Uint |  324 |  1  | R/W | |
| Floating charging voltage |  0.1V |  Uint |  325 |  1  | R/W | |
| Battery discharge recovery point in mains mode |  0.1V |  Uint |  326 |  1  | R/W | |
| Battery low voltage protection point in mains mode |  0.1V |  Uint |  327 |  1  | R/W | |
| Battery low voltage protection point in off-grid mode  |  0.1V |  Uint |  329 |  1  | R/W | |
| Battery charging priority | |  Uint |  331 |  1  | R/W | 0: Utility priority<br>1: PV priority<br>2: PV is at the same level as the Utility<br>3: Only PV charging is allowed |
| Maximum charging current |  0.1A |  Uint |  332 |  1  | R/W | |
| Maximum mains charging current |  0.1A |  Uint |  333 |  1  | R/W | |
| Eq Charging voltage |  0.1V |  Uint |  334 |  1  | R/W | |
| Battery equalization time |  min |  Uint |  335 |  1  | R/W | Range: 0~900 |
| Equalization timeout exit |  min |  Uint |  336 |  1  | R/W | Range: 0~900 |
| Two equalization charging intervals |  day |  Uint |  337 |  1  | R/W | Range: 1~90  |
| Turn on mode | |  Uint |  406 |  1  | R/W | 0: Can be turn-on locally or remotely<br>1: Only local turn-on<br>2: Only remote turn-on |
| Remote switch | |  Uint |  420 |  1  | R/W | 0: Remote shutdown<br>1: Remote turn-on |
| Exit the fault mode | |  Uint |  426 | |  W  | 1: Exit the fault state (only when the inverter enters the fault mode, it could be available) |
| Rated Power |  W |  Uint |  643 |  1  |  R  | |

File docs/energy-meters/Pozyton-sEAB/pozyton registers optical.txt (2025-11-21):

Urządzenie odczytowe przesyła sekwencję ustalenia trybu pracy:
[ACK]0B1[CR][LF]

Po odmierzeniu zwłoki, licznik wysyła sekwencję żądania autoryzacyjnego 

[SOH]P0[STX](0000)[ETX][BCC]
Urządzenie odczytowe odpowiada sekwencją 

[SOH]P1[STX](yyyyyyyyyy)[ETX][BCC]
Gdzie:
yyyyyyyyyy
hasło zabezpieczające.
Jeżeli licznik prawidłowo zdekoduje sekwencję i zaakceptuje hasło, odpowiada znakiem [ACK]. Na
wyświetlaczu licznika sygnalizowany jest również stan zezwolenia na zmianę parametrów licznika
(„programowanie licznika”) – pulsowanie na ekranie napisu: PPPPPPPP.
W przypadku podania niepoprawnego hasła licznik odpowiada znakiem [NAK] i zrywa połączenie.
Możliwe jest również podanie odpowiedzi bez hasła 

[SOH]P1[STX]()[ETX][BCC]

Nie jest jednak wówczas możliwe programowanie licznika – rozkazy zapisu są ignorowane.

Jeżeli licznik prawidłowo zdekoduje sekwencję odpowiada znakiem [ACK].
Licznik po wysłaniu znaku [ACK] gotowy jest na przyjęcie rozkazów trybu rejestrowego. 

W załączniku znajduje się kod który odczytuje dane z licznika energii pozyton eabm. aktualnie działa on tak że pyta EPP0() czyli energie czynną, pobór, sumaryczną. Przerób kod tak aby wspierał parsowanie innych wiadomości. Tutaj jest lista rozkazów i odpowiedzi licznika. 

EABM------------------------------------------------------------------------------------------------------------

Liczydła energii:
Rozkaz odczytowy R1: Eezx()
Odpowiedz licznika:

y.8.x.(nnnnnn.nnnn)[CR][LF]

Gdzie:
ROZKAZ:
e - energia: 
	P – czynna, 
	Q – bierna;

z - kierunek przepływu energii: 
	P – dodatni (pobór), 
	M – ujemny (oddawanie);
ODP:
x - numer strefy: 
	0 – liczydło sumaryczne, 

y - rodzaj energii i kierunek: 
	0 – P+ (czynna, kierunek pobór), 
	1 – P− (czynna, kierunek oddawanie), 
	2 – Q+ (bierna indukcyjna),
	3 – Q− (bierna pojemnościowa);

nn...n - wartość energii w kWh lub kvarh.

Czynna pobór: EPP0()	
Positive active energy total 	nnnnnn.nnnn
 
Czynna oddwawanie: EPM0()	
Negative active energy total	nnnnnn.nnnn

Bierna indukcyjna: EQP0()	
Positive reactive energy total	nnnnnn.nnnn

Bierna pojemnościowa: EQM0()	
Negative reactive energy total	nnnnnn.nnnn 

Typ licznika
Rozkaz odczytowy R1: VI()
Odpowiedź licznika: 27.(p;u;i)[CR][LF]
Gdzie:
p - współczynnik profilu w Wh (możliwe wartości: 0.1(bezpośredni), 0.01(półpośredni), 0.001(pośredni));
u - napięcie nominalne licznika (możliwe wartości: 58(pośredni), 100(pośredni Aron), 230(półpośredni, bezpośredni));
i - prąd maksymalny licznika (możliwe wartości: 10(półpośredni, pośredni), 60(bezpośredni)).

Numer licznika
Rozkaz odczytowy R1: L()
Odpowiedź licznika: 0.0.2(nnn.nnnnnnn)[CR][LF]
Gdzie:
nnn.nnnnnnn - numer licznika.

Częstotliwość
Rozkaz odczytowy R1: F()
Odpowiedź z licznika: 97.6.0(ff.ff)[CR][LF]
ff.ff wartość bieżącej częstotliwości (w Hz).

Bieżąca moc czynna
Rozkaz odczytowy R1: P()
Odpowiedź z licznika: 107(zpp.pp;zpp.pp;zpp.pp;zpp.pp)[CR][LF]
z - kierunek przepływu energii:
	„ ” (spacja) – moc pobierana,
	„−” – moc oddawana;
pp.pp - wartość bieżącej mocy czynnej w kW – kolejno dla L1, L2, L3 i sumaryczna,

Moc chwilowa bierna
Rozkaz odczytowy R1: Q()
Odpowiedź licznika: 109(zqq.qq;zqq.qq;zqq.qq;zqq.qq)[CR][LF]
z - kierunek przepływu energii:
„ ” (spacja) – moc bierna indukcyjna,
„−” – moc bierna pojemnościowa;
qq.qq wartość bieżącej mocy biernej w kvar – kolejno dla L1, L2, L3 i sumaryczna

Napięcie fazowe
Rozkaz odczytowy R1: U()
Odpowiedź licznika: - 97.5.6(uuu.uu;uuu.uu;uuu.uu;s;s;s;w)[CR][LF]
uuu.uu - wartość napięcia fazowego w V (kolejno L1, L2, L3);
s - sygnalizacja przekroczenia progu obecności fazy (kolejno L1, L2, L3):
	1 – napięcie fazowe wyższe od zadanego progu,
	0 – napięcie fazowe niższe od zadanego progu;
w - sygnalizacja kolejności wirowania faz:
	1 – kolejność faz prawidłowa,
	0 – kolejność faz nieprawidłowa,
	x – nie można ustalić kolejności faz.

Prąd w fazach
Rozkaz odczytowy R1: I()
Odpowiedź licznika: 97.4.4(ii.ii;ii.ii;ii.ii)[CR][LF]
ii.ii - wartość prądu w A (kolejno L1, L2, L3)

Tangens neutralny
Rozkaz odczytowy R1: TF()
Odpowiedź licznika: 103.3(f.ff)[CR][LF]
Gdzie:
f.ff - wartość tangensa neutralnego.

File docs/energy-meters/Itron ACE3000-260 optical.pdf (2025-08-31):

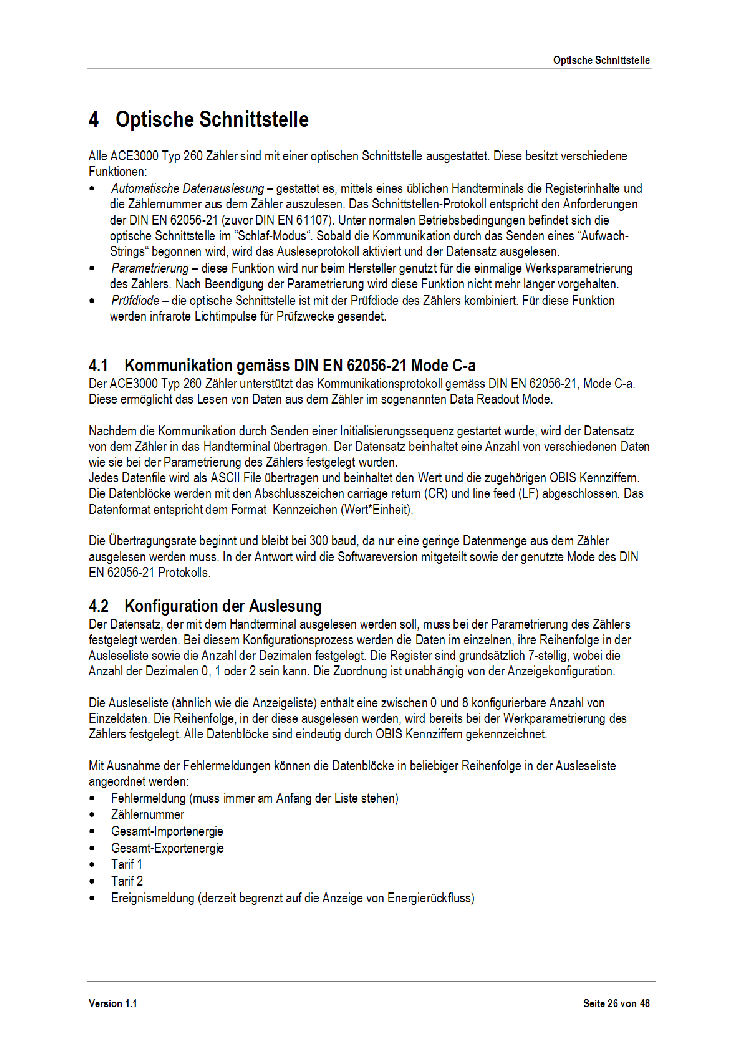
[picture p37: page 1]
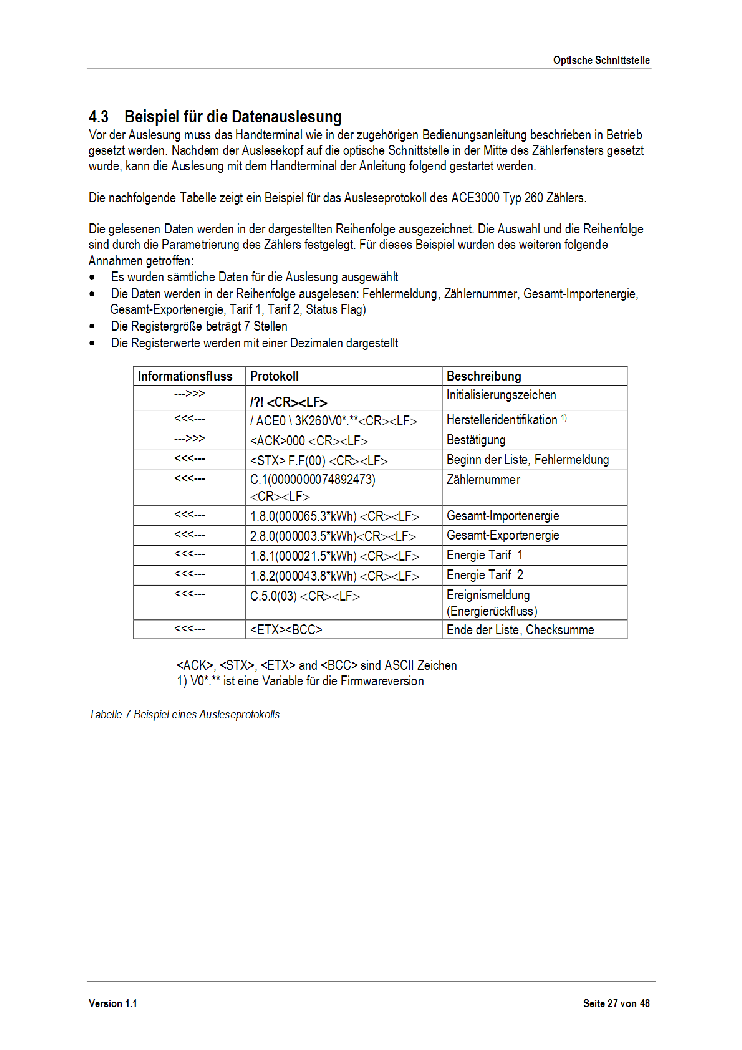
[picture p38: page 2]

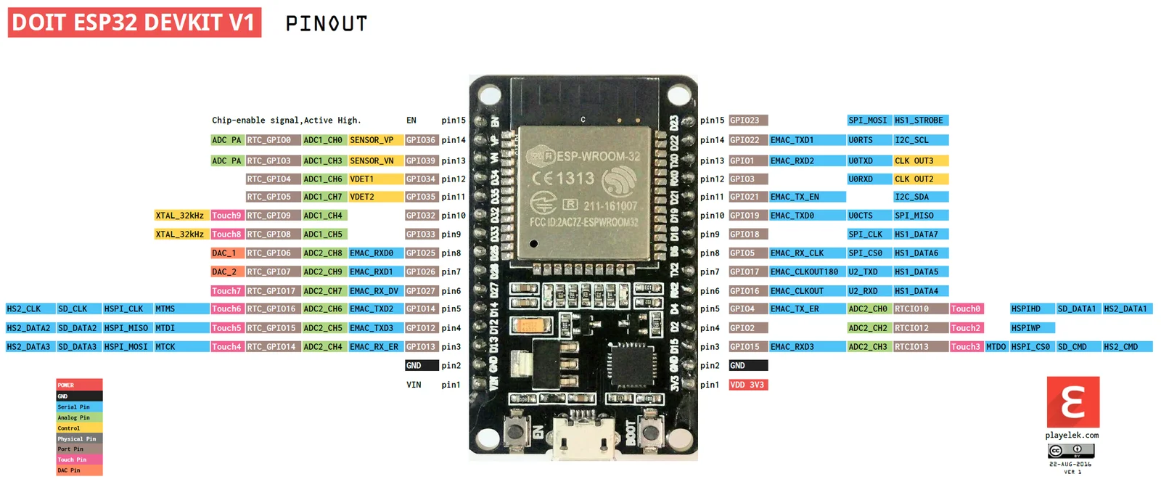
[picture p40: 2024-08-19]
docs/ESP/ESP32-devkit-v1-pinout.webp

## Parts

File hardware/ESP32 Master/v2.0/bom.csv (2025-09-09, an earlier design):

Designator | Footprint | Quantity | Value | LCSC Part #
C100, C101, C102, C103, C104, C105, C106, C107, C108, C109, C110, C111, C34_1, C34_2, C34_3, C34_4, C34_5, C34_6, C34_7, C34_8, C35_1, C35_2, C35_3, C35_4, C35_5, C35_6, C35_7, C35_8, C36_1, C36_2, C36_3, C36_4, C36_5, C36_6, C36_7, C36_8, C37_1, C37_2, C37_3, C37_4, C37_5, C37_6, C37_7, C37_8, C39_1, C39_2, C39_3, C39_4 | 0805 | 48 | 100n
C30, C31, C32, C33, C38_1, C38_2, C38_3, C38_4, C38_5, C38_6, C38_7, C38_8 | 6032-mediana-plyta | 12 | 2,2uF
C33_1, C33_2, C33_3, C33_4, C33_5, C33_6, C33_7, C33_8 | 6032-mediana-plyta | 8 | 22uF
D1, D30, D31, D32, D33 | SOD-80_1-mediana | 5 | LL4148
D20_1, D20_2, D20_3, D20_4, D20_5, D20_6, D20_7, D20_8 | DO-213AB_1-mediana | 8 | LL4002
R1, R2, R3 | 1206-mediana | 3 | 4,7k
R4 | 1206-mediana | 1 | 10k
R82_1, R82_2, R82_3, R82_4, R82_5, R82_6, R82_7, R82_8, R88_1, R88_2, R88_3, R88_4 | 0805 | 12 | 15k
R83_1, R83_2, R83_3, R83_4, R83_5, R83_6, R83_7, R83_8 | 0805 | 8 | 200
R84_1, R84_2, R84_3, R84_4, R84_5, R84_6, R84_7, R84_8 | 0805 | 8 | 33
R85_1, R85_2, R85_3, R85_4, R85_5, R85_6, R85_7, R85_8 | 0805 | 8 | 2,7k
R86_1, R86_2, R86_3, R86_4, R86_5, R86_6, R86_7, R86_8 | 0805 | 8 | 120
R87_1, R87_2, R87_3, R87_4, R87_5, R87_6, R87_7, R87_8 | 1206-mediana | 8 | 6,8k
R89, R90, R91, R92 | 1206-mediana | 4 | 100
R89_1, R89_2, R89_3, R89_4 | 0805 | 4 | 150
R90_1, R90_2, R90_3, R90_4, R90_5, R90_6, R90_7, R90_8 | 0805 | 8 | 6,8k
R93, R94, R95, R96 | 0805 | 4 | 0
TR1, TR2, TR3, TR4 | 6032-mediana-plyta | 4 | 6,8V
TR3_1, TR3_2, TR3_3, TR3_4, TR3_5, TR3_6, TR3_7, TR3_8 | 6032-mediana-plyta | 8 | 33V
U13_1, U13_2, U13_3, U13_4, U13_5, U13_6, U13_7, U13_8, U14_1, U14_3, U14_4, U15_2 | SO-8-mediana-front | 12 | LM393

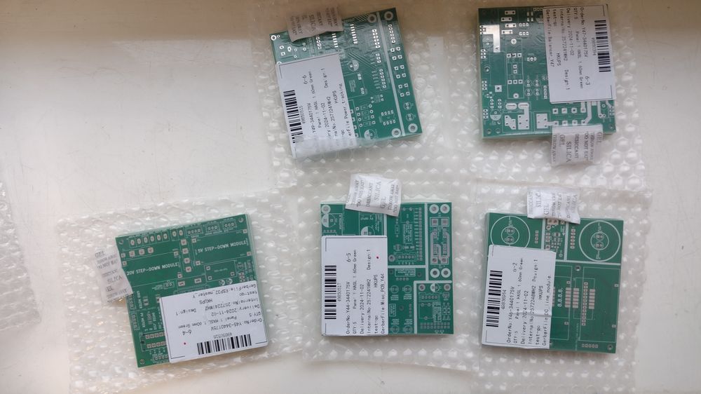
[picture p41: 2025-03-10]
docs/photos/PCB_first_order.jpg

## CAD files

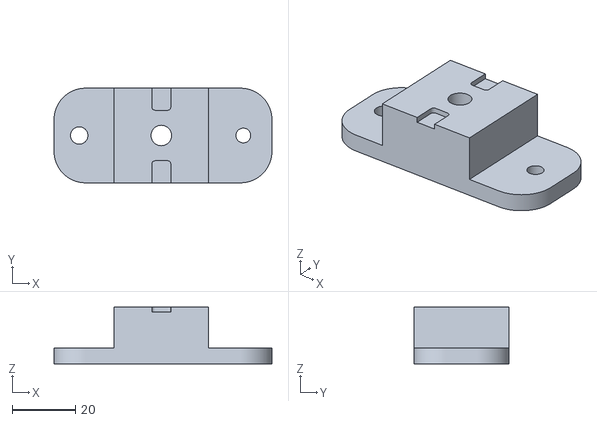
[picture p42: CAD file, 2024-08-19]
mechanical/Dystans_BM1.stl
69.1 x 30.0 x 18.0

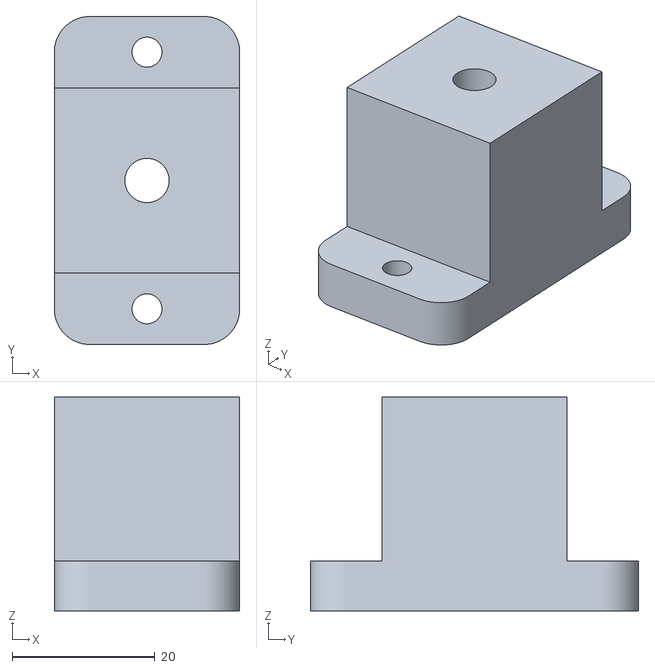
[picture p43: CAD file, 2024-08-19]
mechanical/Dystans_szyny_CU_3d_1.stl
26.0 x 46.0 x 30.0

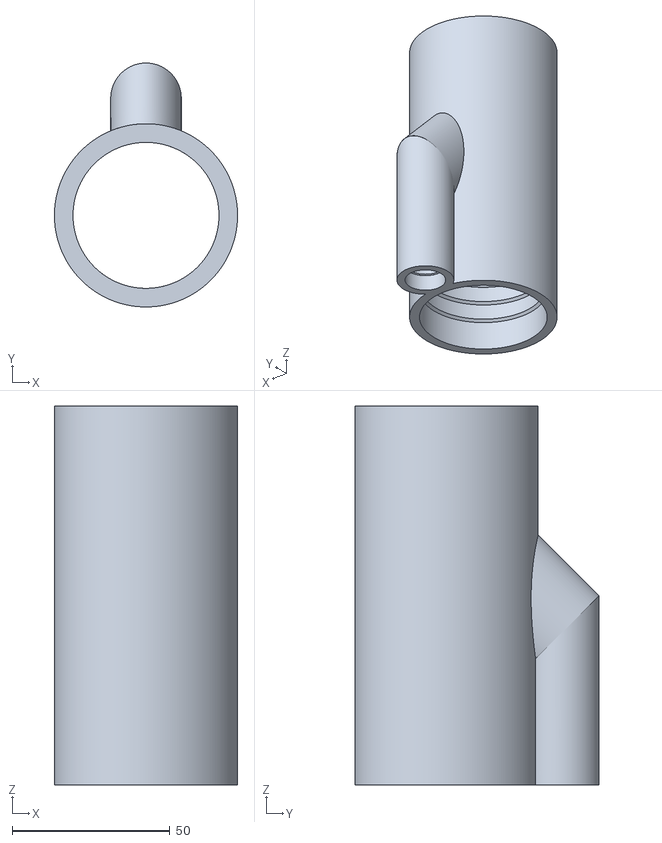
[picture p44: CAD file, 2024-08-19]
mechanical/rl-47_pipe_connector_with_arot_50_and_16_conduit.stl
58.0 x 77.2 x 120.0

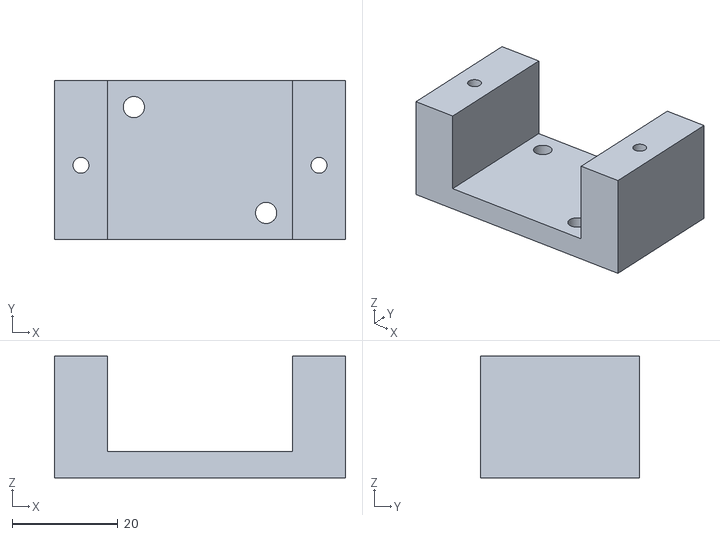
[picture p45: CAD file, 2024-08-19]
mechanical/spacer_for_shunt_resistor.stl
55.0 x 30.0 x 23.0

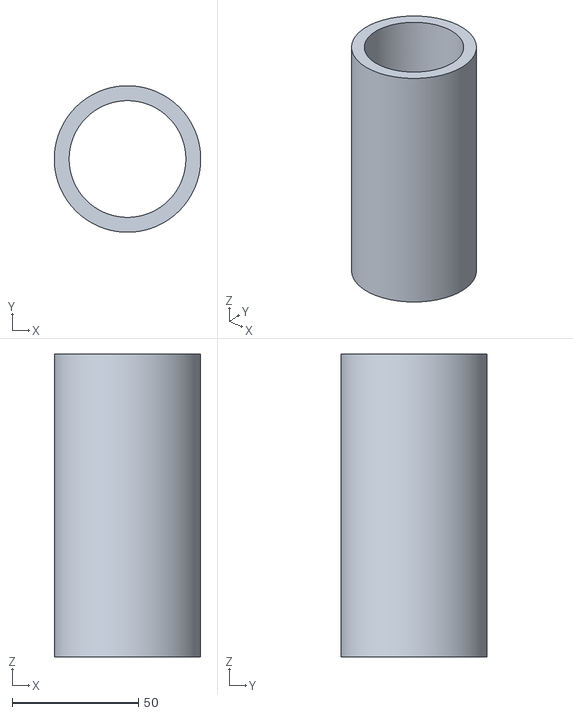
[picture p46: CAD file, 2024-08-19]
mechanical/rl-47_pipe_connector_with_arot_50.stl
58.0 x 58.0 x 120.0

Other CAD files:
mechanical/Dystans_BM.stl

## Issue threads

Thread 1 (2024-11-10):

Invitation to Share Your Work in Elektor Magazine

elektor-labs, 2024-11-10:
Hello @kwiecinski,

Our team at Elektor Labs recently came across your GitHub, and we were thoroughly impressed—especially with your BMS Project and Soldering Station project. The level of ingenuity and detail in your work is inspiring, and it’s clear you have a talent for innovative design.

We wanted to reach out directly but couldn’t locate an email, so opening an issue here seemed the most feasible way to connect.

Elektor Magazine has been a platform for engineers, innovators, and tech enthusiasts worldwide for over 60 years, and we’d love to discuss the possibility of sharing your projects and insights in an article. We believe your work would resonate with our readers and inspire others in the electronics community.

Would you be open to sharing your projects and experiences in an article? If so, please feel free to reach us at labs@elektor.com. This could be a fantastic opportunity to showcase your work to a broader audience and inspire fellow engineers.

Looking forward to hearing from you if this sparks your interest!

Warm regards,
The Elektor Labs Team

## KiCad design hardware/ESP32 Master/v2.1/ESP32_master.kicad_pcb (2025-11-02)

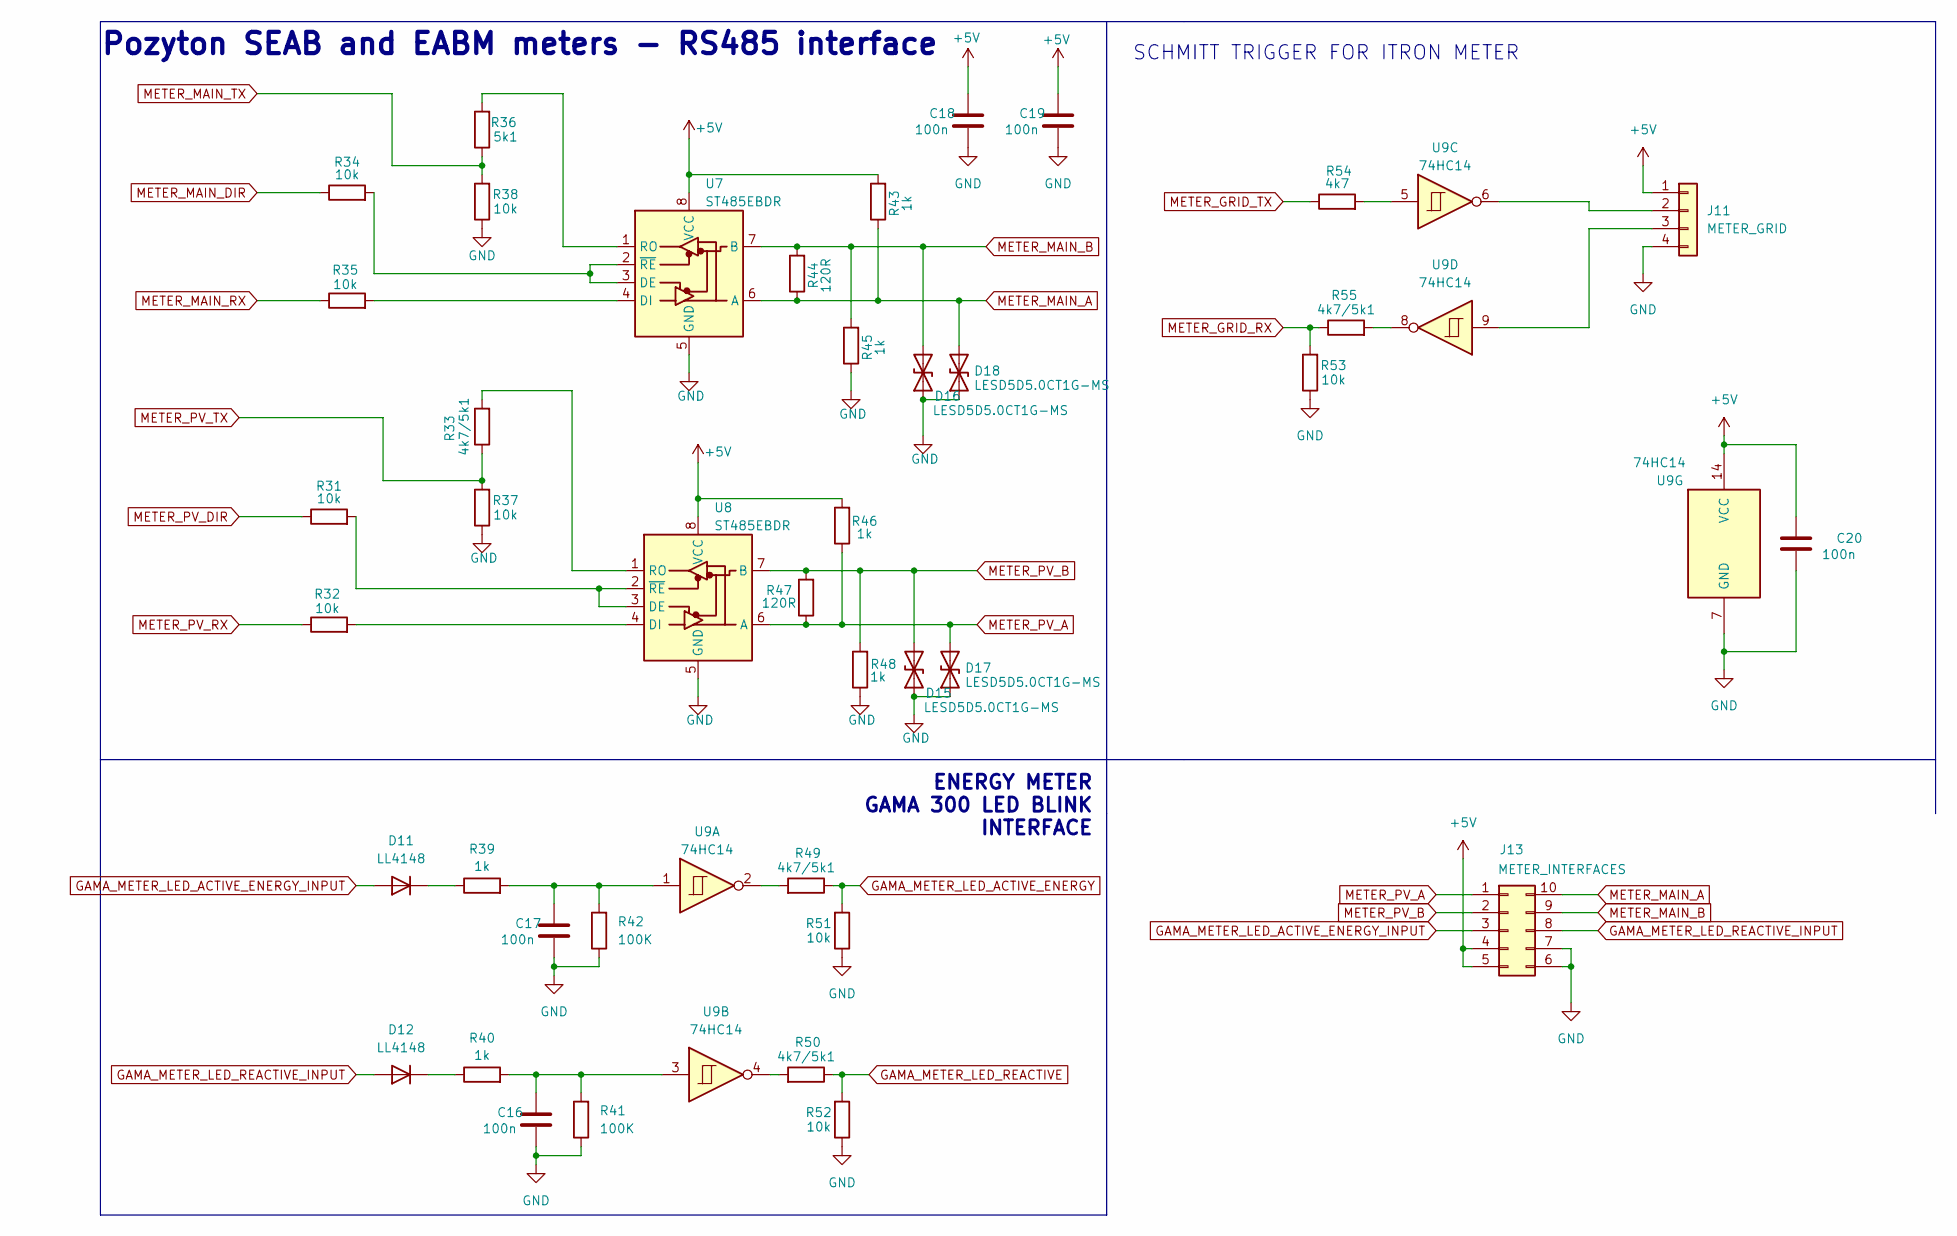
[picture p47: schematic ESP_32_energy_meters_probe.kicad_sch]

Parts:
C16, C17, C18, C19, C20: 100n; C_0805_2012Metric_Pad1.18x1.45mm_HandSolder
D11, D12: LL4148; D_MiniMELF
D15, D16, D17, D18: LESD5D5.0CT1G-MS; D_SOD-523
J11: METER_GRID; JST_XA_B04B-XASK-1_1x04_P2.50mm_Vertical
J13: METER_INTERFACES; CDDC-1,5-5-PV-3,5
R31, R32, R34, R35, R37, R38, R51, R52, R53: 10k; R_0805_2012Metric_Pad1.20x1.40mm_HandSolder
R33, R49, R50, R55: 4k7/5k1; R_0805_2012Metric_Pad1.20x1.40mm_HandSolder
R36: 5k1; R_0805_2012Metric_Pad1.20x1.40mm_HandSolder
R39, R40, R43, R45, R46, R48: 1k; R_0805_2012Metric_Pad1.20x1.40mm_HandSolder
R41, R42: 100K; R_0805_2012Metric_Pad1.20x1.40mm_HandSolder
R44, R47: 120R; R_0805_2012Metric_Pad1.20x1.40mm_HandSolder
R54: 4k7; R_0805_2012Metric_Pad1.20x1.40mm_HandSolder
U7, U8: ST485EBDR; SOIC-8_3.9x4.9mm_P1.27mm
U9: 74HC14; SOIC-14_3.9x8.7mm_P1.27mm

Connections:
+5V: C18.1, C19.1, C20.1, J11.1, J13.4, J13.5, R43.2, R46.2, U7.8 (VCC), U8.8 (VCC), U9.14 (VCC); also elsewhere on the board
GAMA_METER_LED_ACTIVE_ENERGY: R49.1, R51.2; also elsewhere on the board
GAMA_METER_LED_ACTIVE_ENERGY_INPUT: D11.2 (A), J13.3
GAMA_METER_LED_REACTIVE: R50.1, R52.2; also elsewhere on the board
GAMA_METER_LED_REACTIVE_INPUT: D12.2 (A), J13.8
GND: C16.2, C17.2, C18.2, C19.2, C20.2, D15.1 (A1), D16.1 (A1), D17.1 (A1), D18.1 (A1), J11.4, J13.6, J13.7, R37.1, R38.1, R41.1, R42.1, R45.1, R48.1, R51.1, R52.1, R53.1, U7.5 (GND), U8.5 (GND), U9.7 (GND); also elsewhere on the board
METER_GRID_RX: R53.2, R55.1; also elsewhere on the board
METER_GRID_TX: R54.1; also elsewhere on the board
METER_MAIN_A: D18.2 (A2), J13.10, R43.1, R44.1, U7.6 (A)
METER_MAIN_B: D16.2 (A2), J13.9, R44.2, R45.2, U7.7 (B)
METER_MAIN_DIR: R34.1; also elsewhere on the board
METER_MAIN_RX: R35.1; also elsewhere on the board
METER_MAIN_TX: R36.1, R38.2; also elsewhere on the board
METER_PV_A: D17.2 (A2), J13.1, R46.1, R47.1, U8.6 (A)
METER_PV_B: D15.2 (A2), J13.2, R47.2, R48.2, U8.7 (B)
METER_PV_DIR: R31.1; also elsewhere on the board
METER_PV_RX: R32.1; also elsewhere on the board
METER_PV_TX: R33.1, R37.2; also elsewhere on the board
unnamed: C16.1, R40.2, R41.2, U9.3
unnamed: C17.1, R39.2, R42.2, U9.1
unnamed: D11.1 (K), R39.1
unnamed: D12.1 (K), R40.1
unnamed: J11.2, U9.6
unnamed: J11.3, U9.9
unnamed: R49.2, U9.2
unnamed: R50.2, U9.4
unnamed: R54.2, U9.5
unnamed: R55.2, U9.8
unnamed: R34.2, U7.2 (~RE), U7.3 (DE)
unnamed: R35.2, U7.4 (DI)
unnamed: R36.2, U7.1 (RO)
unnamed: R31.2, U8.2 (~RE), U8.3 (DE)
unnamed: R32.2, U8.4 (DI)
unnamed: R33.2, U8.1 (RO)

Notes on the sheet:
Pozyton SEAB and EABM meters - RS485 interface
ENERGY METER GAMA 300 LED BLINK INTERFACE
SCHMITT TRIGGER FOR ITRON METER

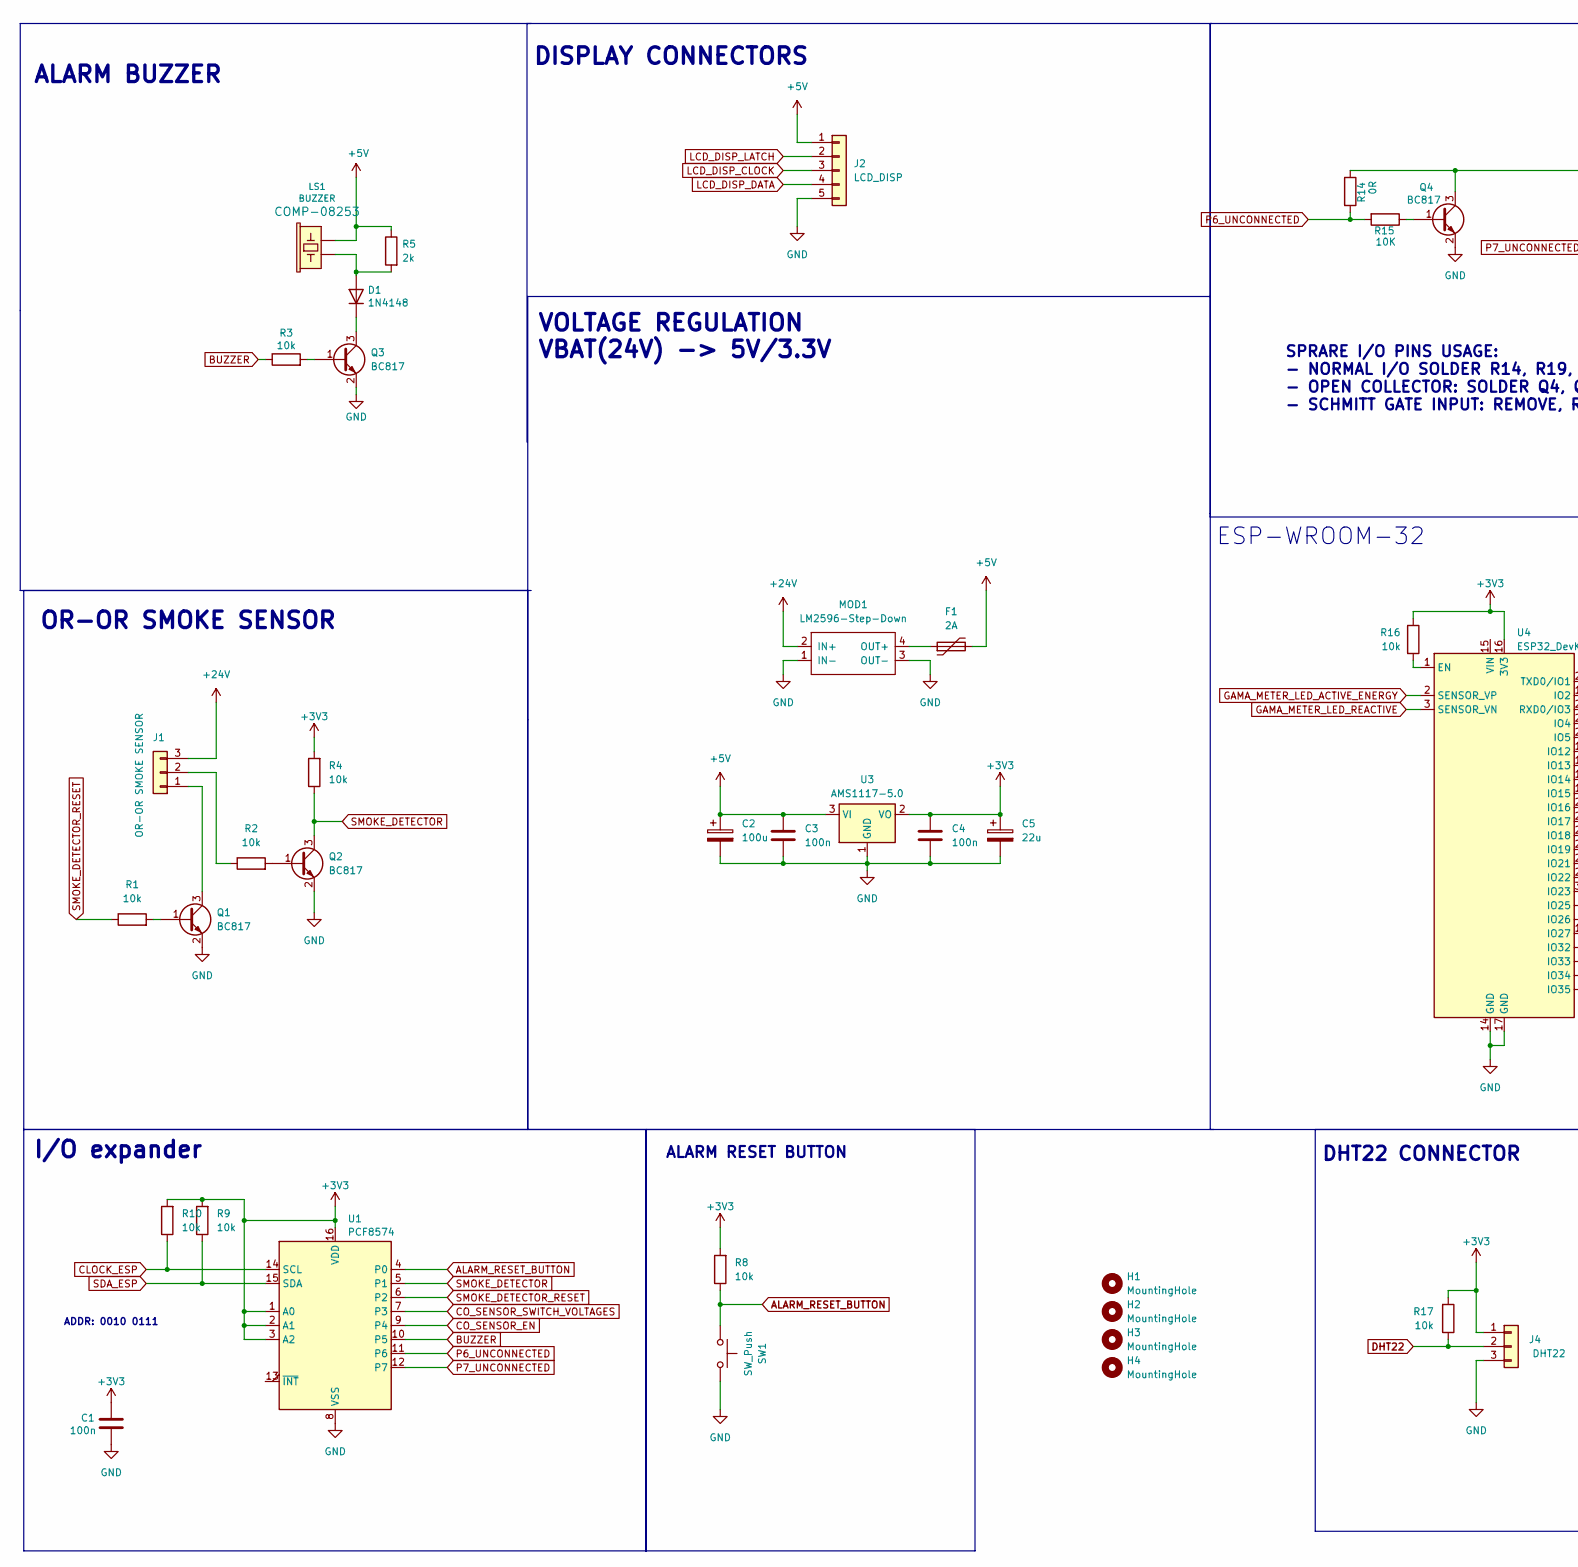
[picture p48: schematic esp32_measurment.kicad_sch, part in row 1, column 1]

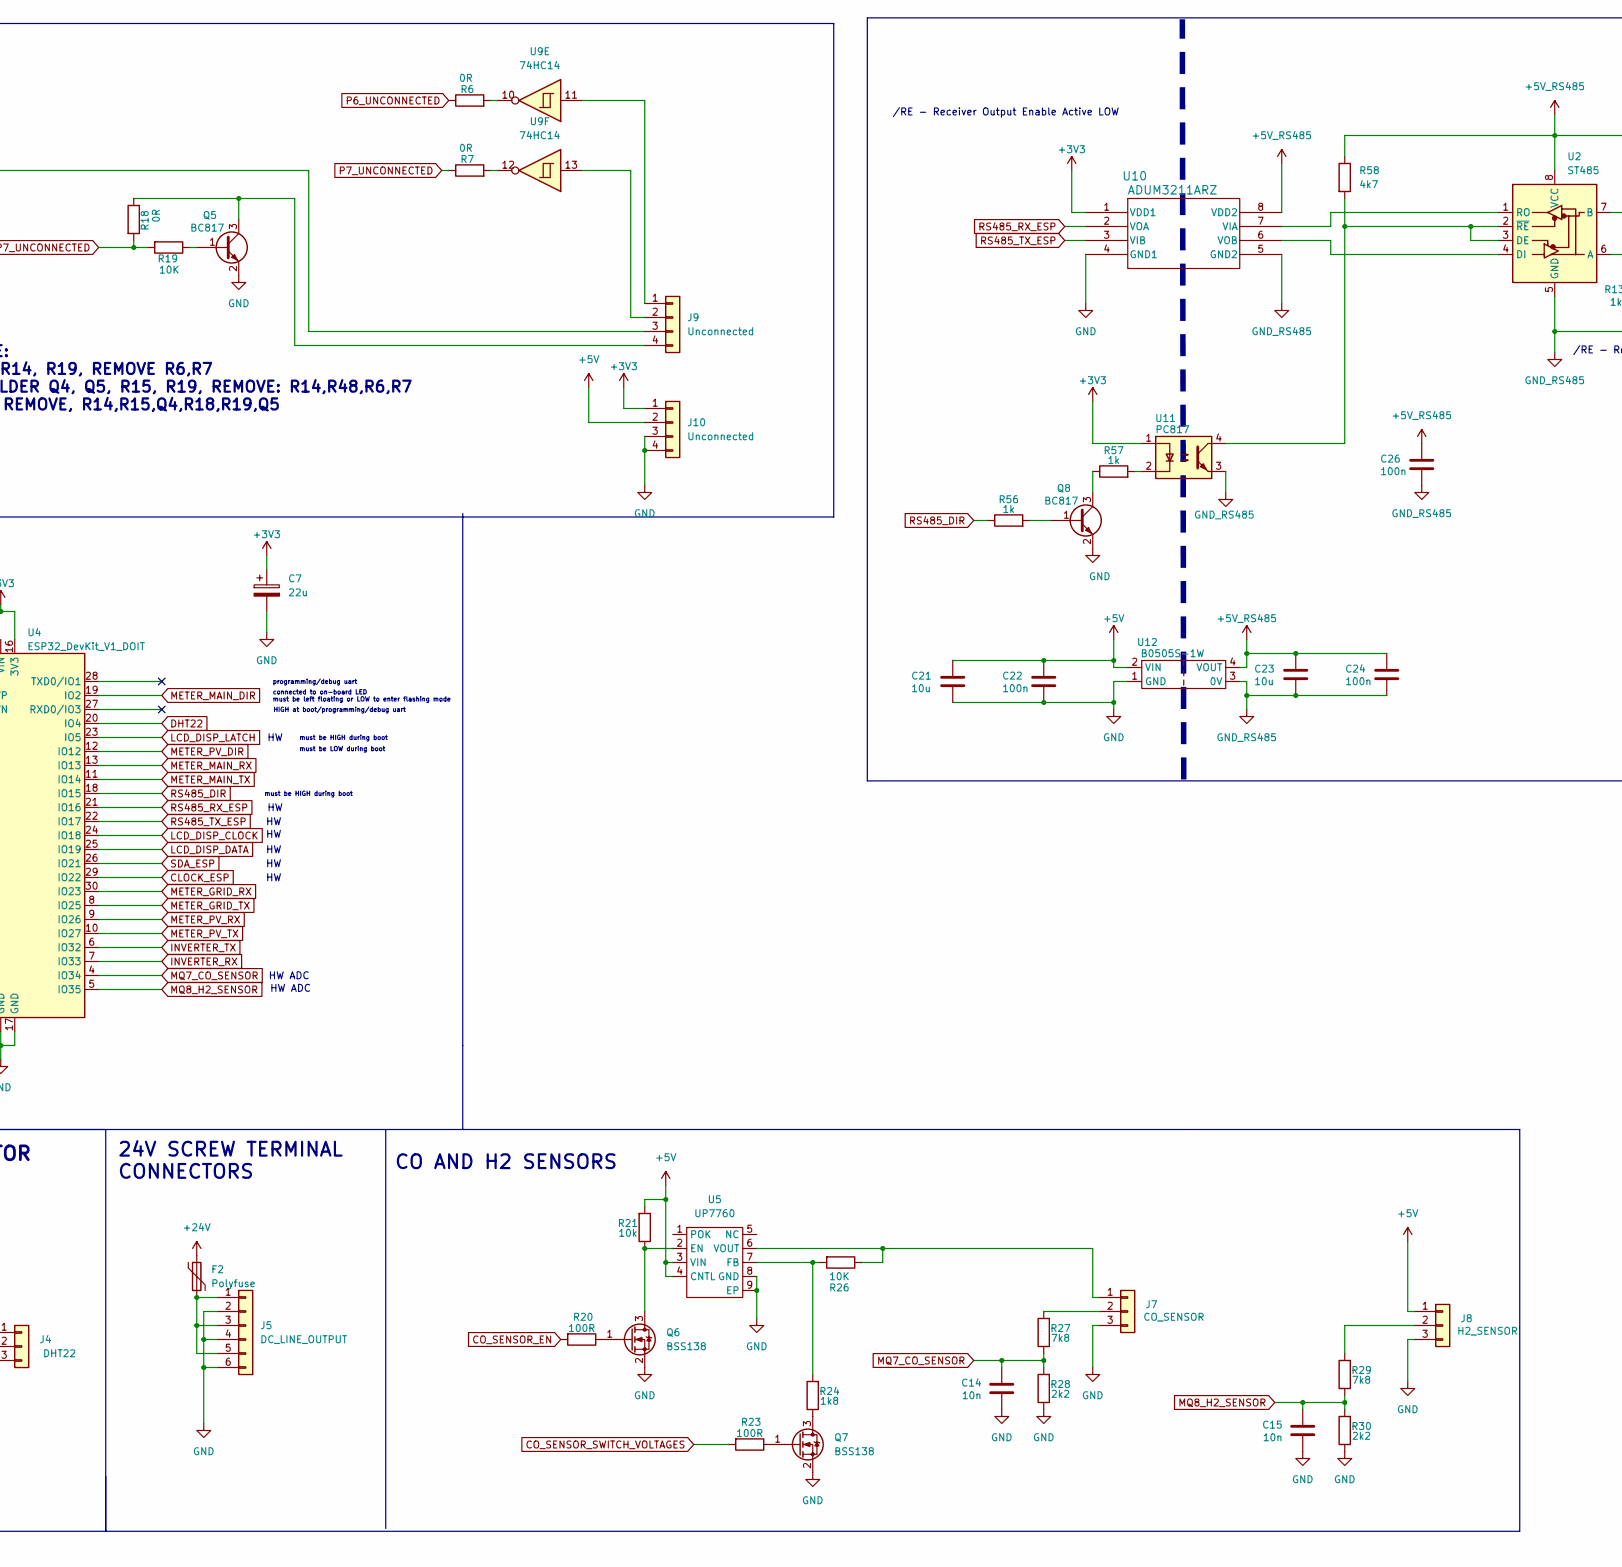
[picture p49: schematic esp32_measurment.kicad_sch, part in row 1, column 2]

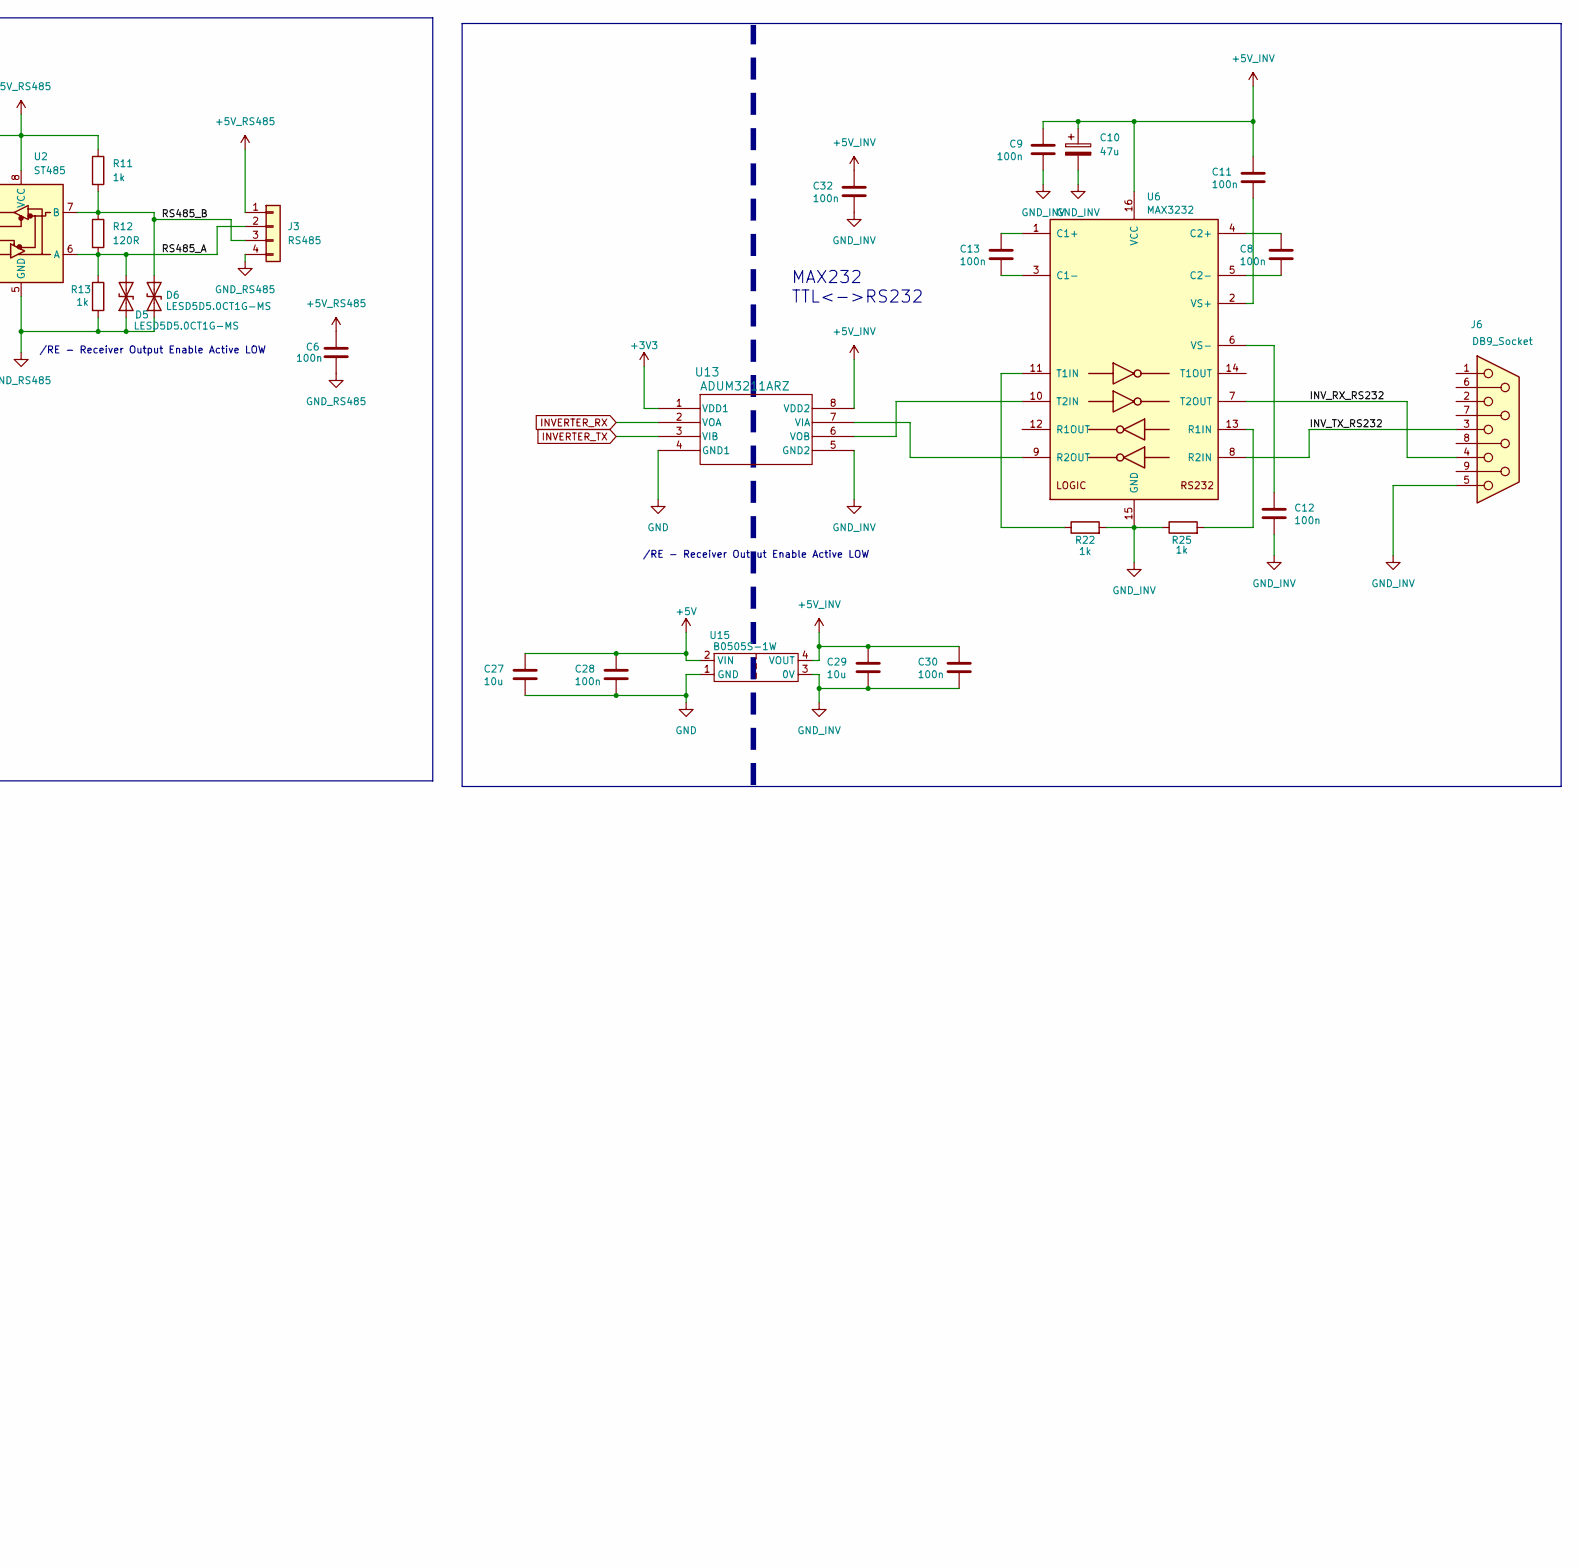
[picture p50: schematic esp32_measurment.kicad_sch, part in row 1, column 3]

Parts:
C1, C3, C4, C6, C8, C11, C12, C13, C22, C24, C26, C28, C30, C32: 100n; C_0805_2012Metric_Pad1.18x1.45mm_HandSolder
C2: 100u; CP_Radial_D4.0mm_P1.50mm
C5: 22u; CP_Radial_D4.0mm_P1.50mm
C7: 22u; CP_Radial_D5.0mm_P2.00mm
C9: 100n; C_0805_2012Metric
C10: 47u; CP_Radial_D5.0mm_P2.00mm
C14, C15: 10n; C_0805_2012Metric
C21, C23, C27, C29: 10u; C_1206_3216Metric
D1: 1N4148; D_MiniMELF
D5, D6: LESD5D5.0CT1G-MS; D_SOD-523
F1: 2A; Fuse_2512_6332Metric_Pad1.52x3.35mm_HandSolder
F2: Polyfuse; Fuse_2920_7451Metric
H1, H2, H3, H4: MountingHole; Mount-Hole-3mm
J1: OR-OR SMOKE SENSOR; JST_XA_B03B-XASK-1_1x03_P2.50mm_Vertical
J2: LCD_DISP; JST_XA_B05B-XASK-1_1x05_P2.50mm_Vertical
J3: RS485; JST_XH_B4B-XH-A_1x04_P2.50mm_Vertical
J4: DHT22; JST_XA_1x03_P2.54mm_Vertical
J5: DC_LINE_OUTPUT; Screw-Terminal-P6-rast-5mm-6,7x30
J6: DB9_Socket; DSUB-9_Female_Horizontal_P2.77x2.84mm_EdgePinOffset7.70mm_H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
J7: CO_SENSOR; JST_XA_B03B-XASK-1_1x03_P2.50mm_Vertical
J8: H2_SENSOR; JST_XA_B03B-XASK-1_1x03_P2.50mm_Vertical
J9, J10: Unconnected; JST_XA_B04B-XASK-1_1x04_P2.50mm_Vertical
LS1: BUZZER; Buzzer
MOD1: LM2596-Step-Down; LM2596-Step-Down-Conv
Q1, Q2, Q3, Q4, Q5, Q8: BC817; SOT-23
Q6, Q7: BSS138; SOT-23
R1, R2, R3, R4, R8, R9, R10, R16, R17, R21: 10k; R_0805_2012Metric_Pad1.20x1.40mm_HandSolder
R5: 2k; C_0805_2012Metric
R6, R7, R14, R18: 0R; R_0805_2012Metric_Pad1.20x1.40mm_HandSolder
R11, R13, R22, R25, R56, R57: 1k; R_0805_2012Metric_Pad1.20x1.40mm_HandSolder
R12: 120R; R_0805_2012Metric_Pad1.20x1.40mm_HandSolder
R15, R19, R26: 10K; R_0805_2012Metric_Pad1.20x1.40mm_HandSolder
R20, R23: 100R; R_0805_2012Metric_Pad1.20x1.40mm_HandSolder
R24: 1k8; R_0805_2012Metric_Pad1.20x1.40mm_HandSolder
R27, R29: 7k8; R_0805_2012Metric_Pad1.20x1.40mm_HandSolder
R28, R30: 2k2; R_0805_2012Metric_Pad1.20x1.40mm_HandSolder
R58: 4k7; R_0805_2012Metric_Pad1.20x1.40mm_HandSolder
SW1: SW_Push; JST_XA_B02B-XASK-1_1x02_P2.50mm_Vertical
U1: PCF8574; DIP-16_W7.62mm_LongPads
U2: ST485; SOIC-8_3.9x4.9mm_P1.27mm
U3: AMS1117-5.0; SOT-223-3_TabPin2
U4: ESP32_DevKit_V1_DOIT; esp32_devkit_v1_doit
U5: UP7760; SOIC-8-1EP_3.9x4.9mm_P1.27mm_EP2.41x3.81mm
U6: MAX3232; SO-16_3.9x9.9mm_P1.27mm
U9: 74HC14; SOIC-14_3.9x8.7mm_P1.27mm
U10, U13: ADUM3211ARZ; SO-8_3.9x4.9mm_P1.27mm
U11: PC817; DIP-4_W7.62mm
U12, U15: B0505S-1W; B0505S

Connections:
+3V3: C1.1, C4.1, C5.1, C7.1, J4.1, J10.1, R4.2, R8.2, R9.2, R10.2, R16.1, R17.2, U1.1 (A0), U1.2 (A1), U1.3 (A2), U1.16 (VDD), U3.2 (VO), U4.16 (3V3), U10.1 (VDD1), U11.1, U13.1 (VDD1)
+5V: C2.1, C3.1, C21.1, C22.1, C27.1, C28.1, F1.2, J2.1, J8.1, J10.2, LS1.- (2), R5.1, R21.2, U3.3 (VI), U5.3 (VIN), U5.4 (CNTL), U12.2 (VIN), U15.2 (VIN); also elsewhere on the board
+5V_INV: C9.2, C10.1, C11.1, C29.1, C30.1, C32.1, U6.16 (VCC), U13.8 (VDD2), U15.4 (VOUT)
+5V_RS485: C6.1, C23.1, C24.1, C26.1, J3.1, R11.1, R58.1, U2.8 (VCC), U10.8 (VDD2), U12.4 (VOUT)
+24V: F2.1, J1.3, MOD1.2 (IN+)
/ESP32_Measurment_Board/INV_RX_RS232: J6.2, J6.4, U6.7 (T2OUT)
/ESP32_Measurment_Board/INV_TX_RS232: J6.3, U6.8 (R2IN)
/ESP32_Measurment_Board/RS485_A: D5.2 (A2), J3.2, R12.2, R13.1, U2.6 (A)
/ESP32_Measurment_Board/RS485_B: D6.2 (A2), J3.3, R11.2, R12.1, U2.7 (B)
ALARM_RESET_BUTTON: R8.1, SW1.1, U1.4 (P0)
BUZZER: R3.1, U1.10 (P5)
CLOCK_ESP: R10.1, U1.14 (SCL), U4.29 (IO22)
CO_SENSOR_EN: R20.2, U1.9 (P4)
CO_SENSOR_SWITCH_VOLTAGES: R23.2, U1.7 (P3)
DHT22: J4.2, R17.1, U4.20 (IO4)
GAMA_METER_LED_ACTIVE_ENERGY: U4.2 (SENSOR_VP); also elsewhere on the board
GAMA_METER_LED_REACTIVE: U4.3 (SENSOR_VN); also elsewhere on the board
GND: C1.2, C2.2, C3.2, C4.2, C5.2, C7.2, C14.1, C15.1, C21.2, C22.2, C27.2, C28.2, J2.5, J4.3, J5.2, J5.4, J5.6, J7.3, J8.3, J10.3, J10.4, MOD1.1 (IN-), MOD1.3 (OUT-), Q1.2 (E), Q2.2 (E), Q3.2 (E), Q4.2 (E), Q5.2 (E), Q6.2 (S), Q7.2 (S), Q8.2 (E), R28.1, R30.1, SW1.2, U1.8 (VSS), U3.1 (GND), U4.14 (GND), U4.17 (GND), U5.8 (GND), U5.9 (EP), U10.4 (GND1), U12.1 (GND), U13.4 (GND1), U15.1 (GND); also elsewhere on the board
GND_INV: C9.1, C10.2, C12.2, C29.2, C30.2, C32.2, J6.5, R22.2, R25.1, U6.15 (GND), U13.5 (GND2), U15.3 (0V)
GND_RS485: C6.2, C23.2, C24.2, C26.2, D5.1 (A1), D6.1 (A1), J3.4, R13.2, U2.5 (GND), U10.5 (GND2), U11.3, U12.3 (0V)
INVERTER_RX: U4.7 (IO33), U13.2 (VOA)
INVERTER_TX: U4.6 (IO32), U13.3 (VIB)
LCD_DISP_CLOCK: J2.3, U4.24 (IO18)
LCD_DISP_DATA: J2.4, U4.25 (IO19)
LCD_DISP_LATCH: J2.2, U4.23 (IO5)
METER_GRID_RX: U4.30 (IO23); also elsewhere on the board
METER_GRID_TX: U4.8 (IO25); also elsewhere on the board
METER_MAIN_DIR: U4.19 (IO2); also elsewhere on the board
METER_MAIN_RX: U4.13 (IO13); also elsewhere on the board
METER_MAIN_TX: U4.11 (IO14); also elsewhere on the board
METER_PV_DIR: U4.12 (IO12); also elsewhere on the board
METER_PV_RX: U4.9 (IO26); also elsewhere on the board
METER_PV_TX: U4.10 (IO27); also elsewhere on the board
MQ7_CO_SENSOR: C14.2, R27.1, R28.2, U4.4 (IO34)
MQ8_H2_SENSOR: C15.2, R29.1, R30.2, U4.5 (IO35)
unnamed: D1.2 (A), LS1.+ (1), R5.2
unnamed: D1.1 (K), Q3.3 (C)
unnamed: J1.1, Q1.3 (C)
unnamed: J1.2, R2.1
unnamed: F2.2, J5.1, J5.3, J5.5
unnamed: J7.1, R26.1, U5.6 (VOUT)
unnamed: J7.2, R27.2
unnamed: J8.2, R29.2
unnamed: J9.1, U9.11
unnamed: J9.2, U9.13
unnamed: J9.3, Q4.3 (C), R14.1
unnamed: J9.4, Q5.3 (C), R18.1
unnamed: F1.1, MOD1.4 (OUT+)
unnamed: Q1.1 (B), R1.2
unnamed: Q2.1 (B), R2.2
unnamed: Q3.1 (B), R3.2
unnamed: Q4.1 (B), R15.1
unnamed: Q5.1 (B), R19.1
unnamed: Q6.3 (D), R21.1, U5.2 (EN)
unnamed: Q6.1 (G), R20.1
unnamed: Q7.3 (D), R24.1
unnamed: Q7.1 (G), R23.1
unnamed: Q8.1 (B), R56.2
unnamed: Q8.3 (C), R57.1
unnamed: R6.2, U9.10
unnamed: R7.2, U9.12
unnamed: R57.2, U11.2
unnamed: R58.2, U2.2 (~RE), U2.3 (DE), U11.4
unnamed: R16.2, U4.1 (EN)
unnamed: R24.2, R26.2, U5.7 (FB)
unnamed: C13.1, U6.1 (C1+)
unnamed: C13.2, U6.3 (C1-)
unnamed: C8.1, U6.4 (C2+)
unnamed: C8.2, U6.5 (C2-)
unnamed: R25.2, U6.13 (R1IN)
unnamed: R22.1, U6.11 (T1IN)
unnamed: C11.2, U6.2 (VS+)
unnamed: C12.1, U6.6 (VS-)
unnamed: U2.1 (RO), U10.7 (VIA)
unnamed: U2.4 (DI), U10.6 (VOB)
unnamed: U6.9 (R2OUT), U13.7 (VIA)
unnamed: U6.10 (T2IN), U13.6 (VOB)
P6_UNCONNECTED: R6.1, R14.2, R15.2, U1.11 (P6)
P7_UNCONNECTED: R7.1, R18.2, R19.2, U1.12 (P7)
RS485_DIR: R56.1, U4.18 (IO15)
RS485_RX_ESP: U4.21 (IO16), U10.2 (VOA)
RS485_TX_ESP: U4.22 (IO17), U10.3 (VIB)
SDA_ESP: R9.1, U1.15 (SDA), U4.26 (IO21)
SMOKE_DETECTOR: Q2.3 (C), R4.1, U1.5 (P1)
SMOKE_DETECTOR_RESET: R1.1, U1.6 (P2)

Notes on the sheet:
programming/debug uart
ADDR: 0010 0111
DHT22 CONNECTOR
OR-OR SMOKE SENSOR
ESP-WROOM-32
I/O expander
must be HIGH during boot
/RE - Receiver Output Enable Active LOW
HIGH at boot/programming/debug uart
HW ADC
MAX232 TTL<->RS232
must be LOW during boot
DISPLAY CONNECTORS
connected to on-board LED must be left floating or LOW to enter flashing mode
SPRARE I/O PINS USAGE: - NORMAL I/O SOLDER R14, R19, REMOVE R6,R7 - OPEN COLLECTOR: SOLDER Q4, Q5, R15, R19, REMOVE: R14,R48,R6,R7 - SCHMITT GATE INPUT: REMOVE, R14,R15,Q4,R18,R19,Q5
ALARM RESET BUTTON
CO AND H2 SENSORS
ALARM BUZZER
24V SCREW TERMINAL CONNECTORS
VOLTAGE REGULATION VBAT(24V) -> 5V/3.3V

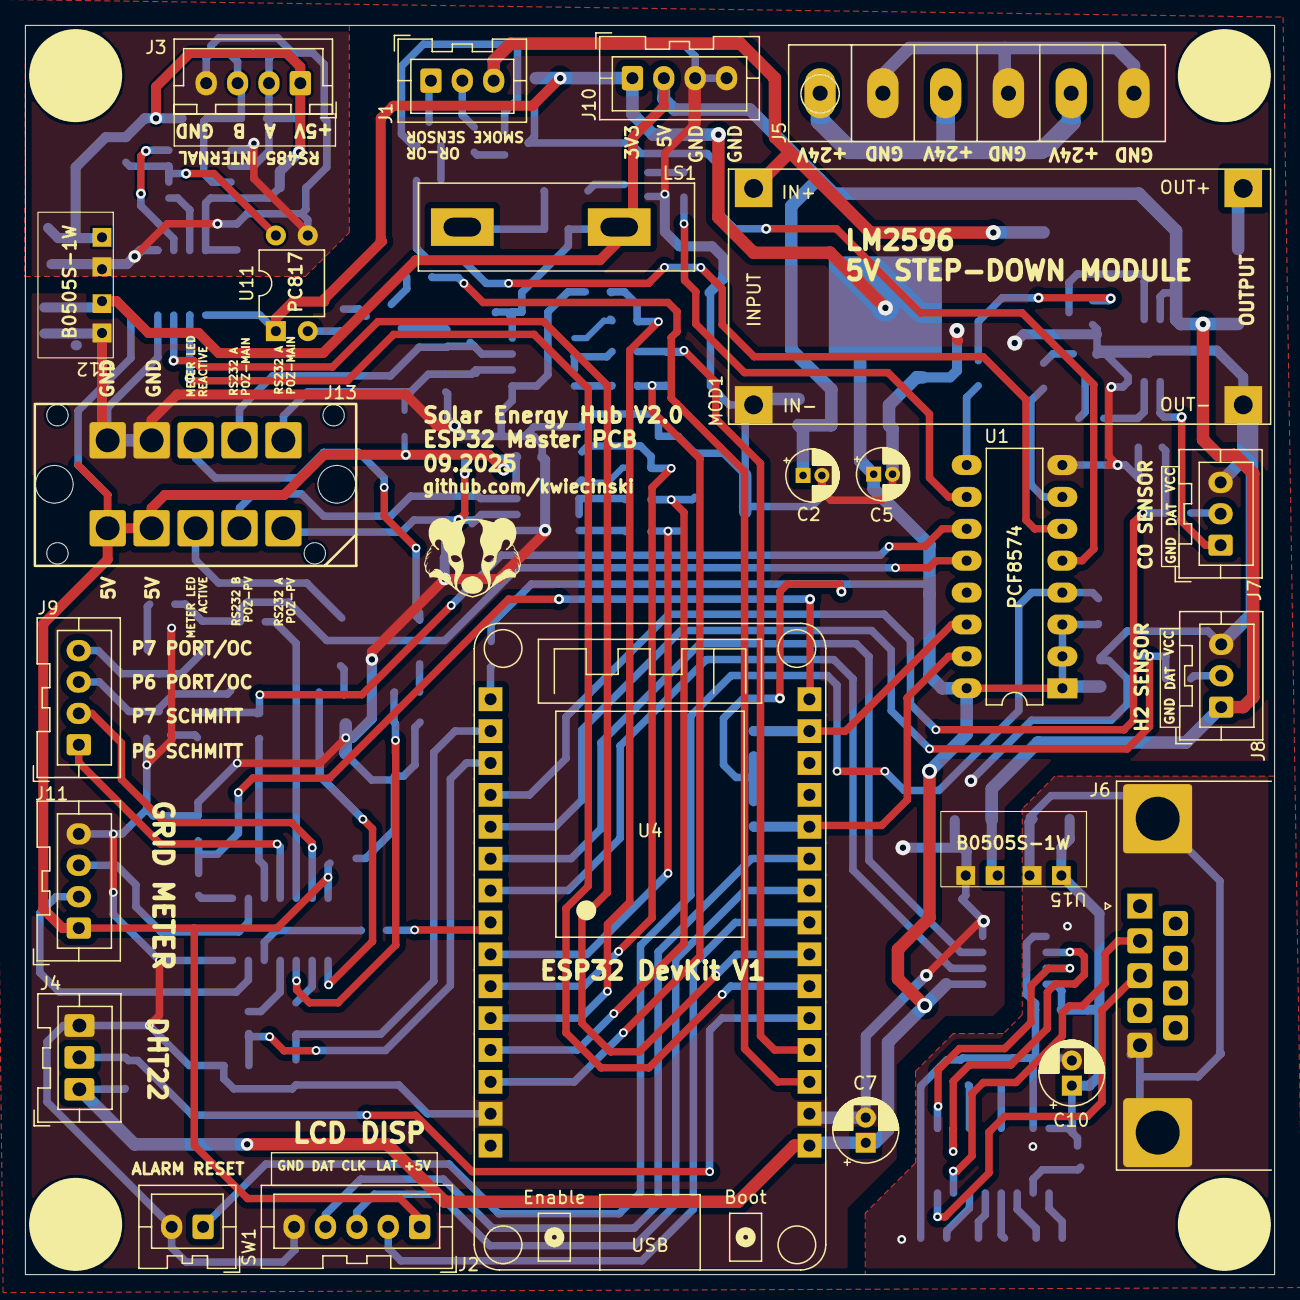
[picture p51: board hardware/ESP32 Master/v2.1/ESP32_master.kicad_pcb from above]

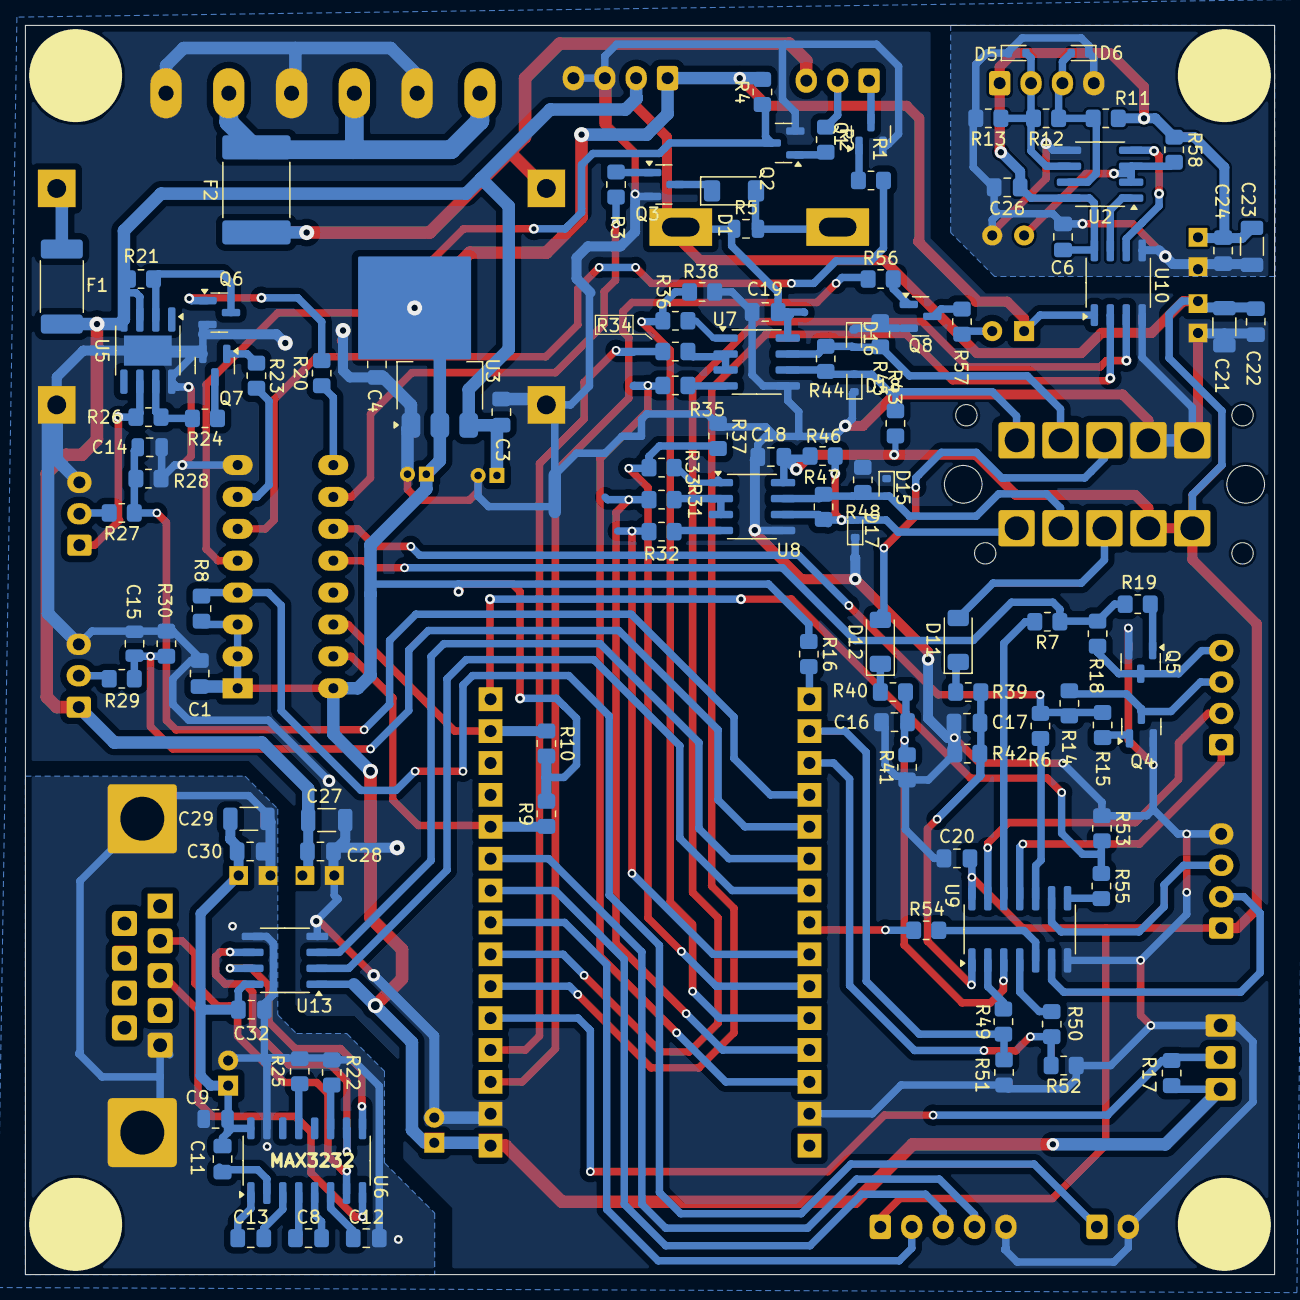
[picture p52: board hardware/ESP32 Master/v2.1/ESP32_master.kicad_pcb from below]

Board: 2 copper layers, 99.5 x 99.5 mm, 140 parts (112 on the bottom side), 107 nets.

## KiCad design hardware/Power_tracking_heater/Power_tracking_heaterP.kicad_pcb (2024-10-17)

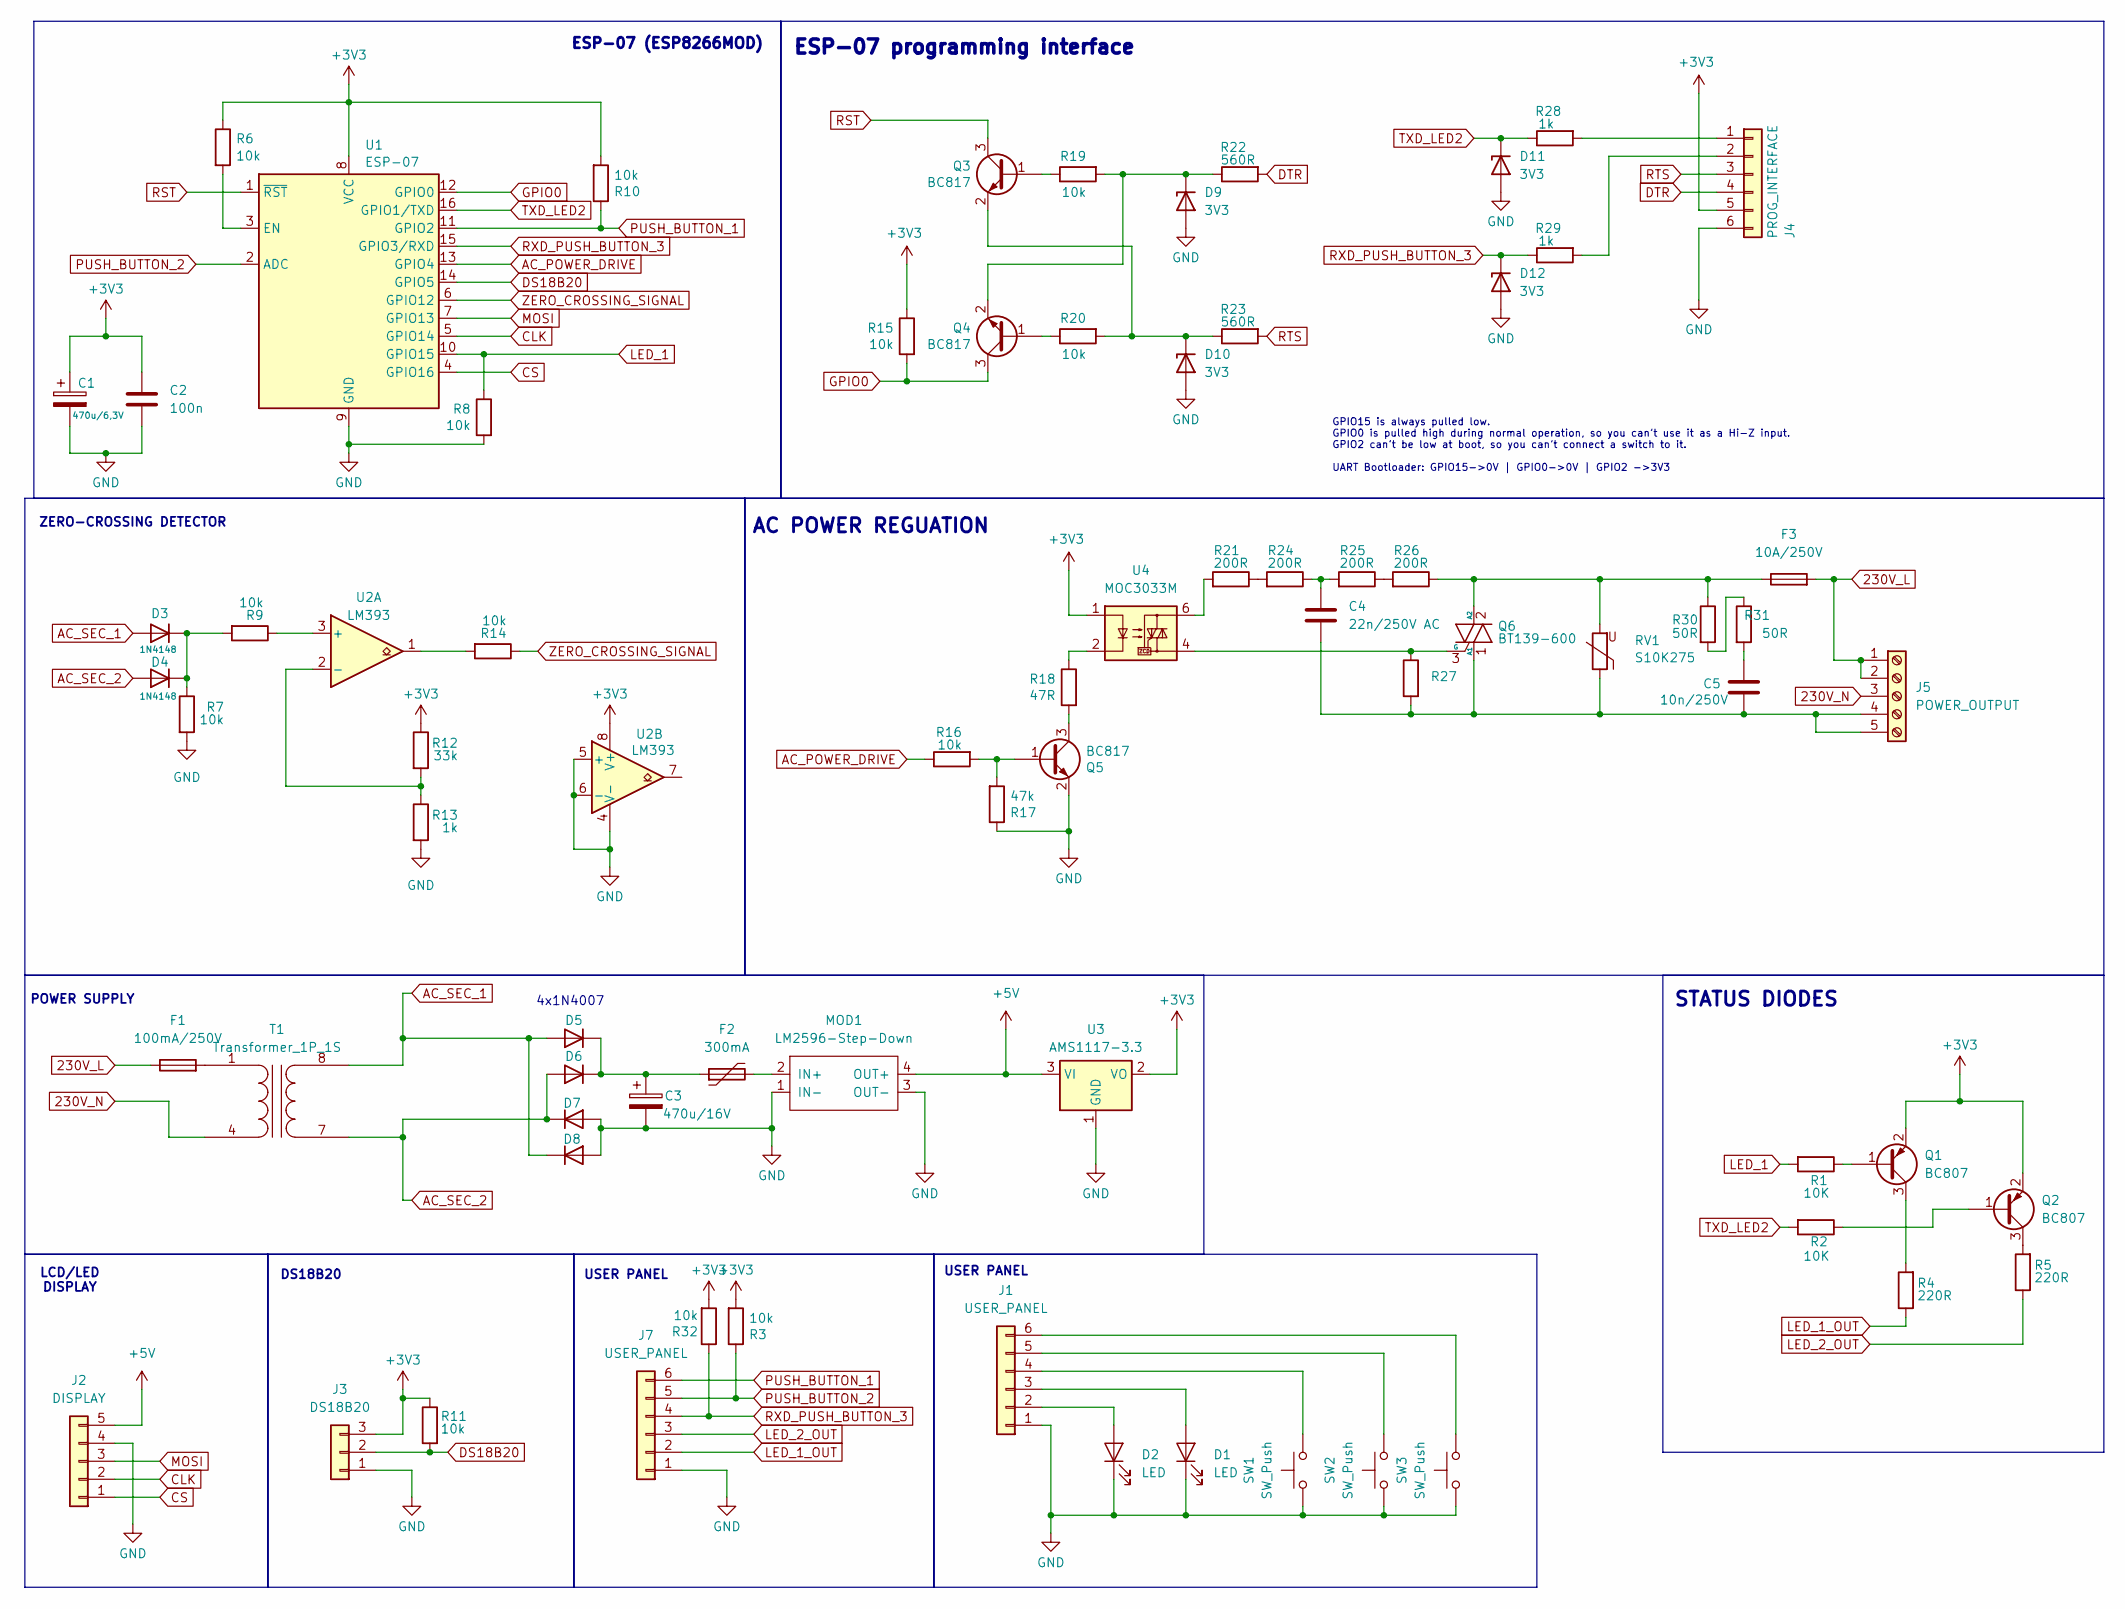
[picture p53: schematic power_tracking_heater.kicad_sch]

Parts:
C1: 470u/6,3V; CP_Radial_D8.0mm_P3.50mm
C2: 100n; C_0805_2012Metric
C3: 470u/16V; CP_Radial_D8.0mm_P2.50mm
C4: 22n/250V AC; C_Rect_L16.5mm_W6.0mm_P15.00mm_MKT
C5: 10n/250V; C_Rect_L16.5mm_W6.0mm_P15.00mm_MKT
D1, D2: LED; LED_D5.0mm
D3, D4: 1N4148; D_DO-35_SOD27_P7.62mm_Horizontal
D5, D6, D7, D8: 1N4007; DO-41_SOD81_P10.16mm_Horizontal
D9, D10, D11, D12: 3V3; D_MiniMELF
F1: 100mA/250V; Fuseholder_Clip-5x20mm_Eaton_1A5601-01_Inline_P20.80x6.76mm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
F2: 300mA; Fuse_2010_5025Metric
F3: 10A/250V; Fuseholder_Clip-5x20mm_Eaton_1A5601-01_Inline_P20.80x6.76mm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
J1, J7: USER_PANEL; JST_XH_1x06_P2.54mm_Vertical
J2: DISPLAY; JST_XA_1x05_P2.50mm_Vertical
J3: DS18B20; JST_XA_1x03_P2.54mm_Vertical
J4: PROG_INTERFACE; Conn-01x06
J5: POWER_OUTPUT; Screw-Terminal-5.00mm-5pin
MOD1: LM2596-Step-Down; MP1504_Mini_3A_Step_Down_Conv
Q1, Q2: BC807; SOT-23
Q3, Q4, Q5: BC817; SOT-23
Q6: BT139-600; TO-220-3_V_Wide_Legs
R1, R2: 10K; R_0805_2012Metric_Pad1.20x1.40mm_HandSolder
R3, R7, R8, R9, R10, R11, R14, R15, R16, R19, R20, R32: 10k; R_0805_2012Metric_Pad1.20x1.40mm_HandSolder
R4, R5: 220R; R_0805_2012Metric_Pad1.20x1.40mm_HandSolder
R6: 10k; C_0805_2012Metric
R12: 33k; R_0805_2012Metric_Pad1.20x1.40mm_HandSolder
R13, R28, R29: 1k; R_0805_2012Metric_Pad1.20x1.40mm_HandSolder
R17: 47k; R_0805_2012Metric_Pad1.20x1.40mm_HandSolder
R18: 47R; R_0805_2012Metric_Pad1.20x1.40mm_HandSolder
R21, R24, R25, R26: 200R; R_Axial_DIN0207_L6.3mm_D2.5mm_P10.16mm_Horizontal
R22, R23: 560R; R_0805_2012Metric_Pad1.20x1.40mm_HandSolder
R27: R_Axial_DIN0207_L6.3mm_D2.5mm_P10.16mm_Horizontal
R30, R31: 50R; R_Axial_DIN0207_L6.3mm_D2.5mm_P10.16mm_Horizontal
RV1: S10K275; RV_Disc_D7mm_W3.5mm_P5mm
SW1, SW2, SW3: SW_Push; SW_PUSH_6mm
T1: Transformer_1P_1S; Transformer TS2-14
U1: ESP-07
U2: LM393; DIP-8_W7.62mm_LongPads
U3: AMS1117-3.3; SOT-223-3_TabPin2
U4: MOC3033M; DIP-6_W7.62mm_LongPads

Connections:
230V_L: F1.1, F3.2, J5.1, J5.2
230V_N: J5.3, T1.4 (AB)
+3V3: C1.1, C2.1, J3.3, J4.5, Q1.2 (E), Q2.2 (E), R3.2, R6.1, R10.2, R11.1, R12.1, R15.1, R32.2, U1.8 (VCC), U2.8 (V+), U3.2 (VO), U4.1
+5V: J2.5, MOD1.4 (OUT+), U3.3 (VI)
AC_POWER_DRIVE: R16.1, U1.13 (GPIO4)
AC_SEC_1: D3.2 (A), D5.2 (A), D8.1 (K), T1.8 (SB)
AC_SEC_2: D4.2 (A), D6.2 (A), D7.1 (K), T1.7 (SA)
CLK: J2.2, U1.5 (GPIO14)
CS: J2.1, U1.4 (GPIO16)
DS18B20: J3.2, R11.2, U1.14 (GPIO5)
DTR: J4.4, R22.2
GND: C1.2, C2.2, C3.2, D1.2 (K), D2.2 (K), D7.2 (A), D8.2 (A), D9.2 (A), D10.2 (A), D11.2 (A), D12.2 (A), J1.1, J2.4, J3.1, J4.6, J7.1, MOD1.1 (IN-), MOD1.3 (OUT-), Q5.2 (E), R7.2, R8.2, R13.2, R17.1, SW1.1, SW2.1, SW3.1, U1.9 (GND), U2.4 (V-), U2.5 (+), U2.6 (-), U3.1 (GND)
GPIO0: Q4.3 (C), R15.2, U1.12 (GPIO0)
LED_1: R1.2, R8.1, U1.10 (GPIO15)
LED_1_OUT: J7.2, R4.1
LED_2_OUT: J7.3, R5.1
MOSI: J2.3, U1.7 (GPIO13)
unnamed: C4.1, R24.1, R25.2
unnamed: C5.1, R31.2
unnamed: D1.1 (A), J1.3
unnamed: D2.1 (A), J1.2
unnamed: D3.1 (K), D4.1 (K), R7.1, R9.2
unnamed: C3.1, D5.1 (K), D6.1 (K), F2.1
unnamed: D9.1 (K), Q4.2 (E), R19.2, R22.1
unnamed: D10.1 (K), Q3.2 (E), R20.2, R23.1
unnamed: J1.4, SW1.2
unnamed: J1.5, SW2.2
unnamed: J1.6, SW3.2
unnamed: J4.1, R28.2
unnamed: J4.2, R29.2
unnamed: C4.2, C5.2, J5.4, J5.5, Q6.1 (A1), R27.2, RV1.1
unnamed: F2.2, MOD1.2 (IN+)
unnamed: Q1.1 (B), R1.1
unnamed: Q1.3 (C), R4.2
unnamed: Q2.1 (B), R2.1
unnamed: Q2.3 (C), R5.2
unnamed: Q3.1 (B), R19.1
unnamed: Q4.1 (B), R20.1
unnamed: Q5.1 (B), R16.2, R17.2
unnamed: Q5.3 (C), R18.2
unnamed: F3.1, Q6.2 (A2), R26.1, R30.1, RV1.2
unnamed: Q6.3 (G), R27.1, U4.4
unnamed: R14.2, U2.1
unnamed: R18.1, U4.2
unnamed: R21.1, R24.2
unnamed: R21.2, U4.6
unnamed: R25.1, R26.2
unnamed: R30.2, R31.1
unnamed: F1.2, T1.1 (AA)
unnamed: R6.2, U1.3 (EN)
unnamed: R9.1, U2.3 (+)
unnamed: R12.2, R13.1, U2.2 (-)
PUSH_BUTTON_1: J7.6, R10.1, U1.11 (GPIO2)
PUSH_BUTTON_2: J7.5, R3.1, U1.2 (ADC)
RST: Q3.3 (C), U1.1 (~RST)
RTS: J4.3, R23.2
RXD_PUSH_BUTTON_3: D12.1 (K), J7.4, R29.1, R32.1, U1.15 (GPIO3/RXD)
TXD_LED2: D11.1 (K), R2.2, R28.1, U1.16 (GPIO1/TXD)
ZERO_CROSSING_SIGNAL: R14.1, U1.6 (GPIO12)

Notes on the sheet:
ESP-07 (ESP8266MOD)
STATUS DIODES
4x1N4007
USER PANEL
GPIO15 is always pulled low. GPIO0 is pulled high during normal operation, so you can’t use it as a Hi-Z input. GPIO2 can’t be low at boot, so you can’t connect a switch to it. UART Bootloader: GPIO15->0V | GPIO0->0V | GPIO2 ->3V3
LCD/LED DISPLAY
POWER SUPPLY
ZERO-CROSSING DETECTOR
ESP-07 programming interface
DS18B20
AC POWER REGUATION

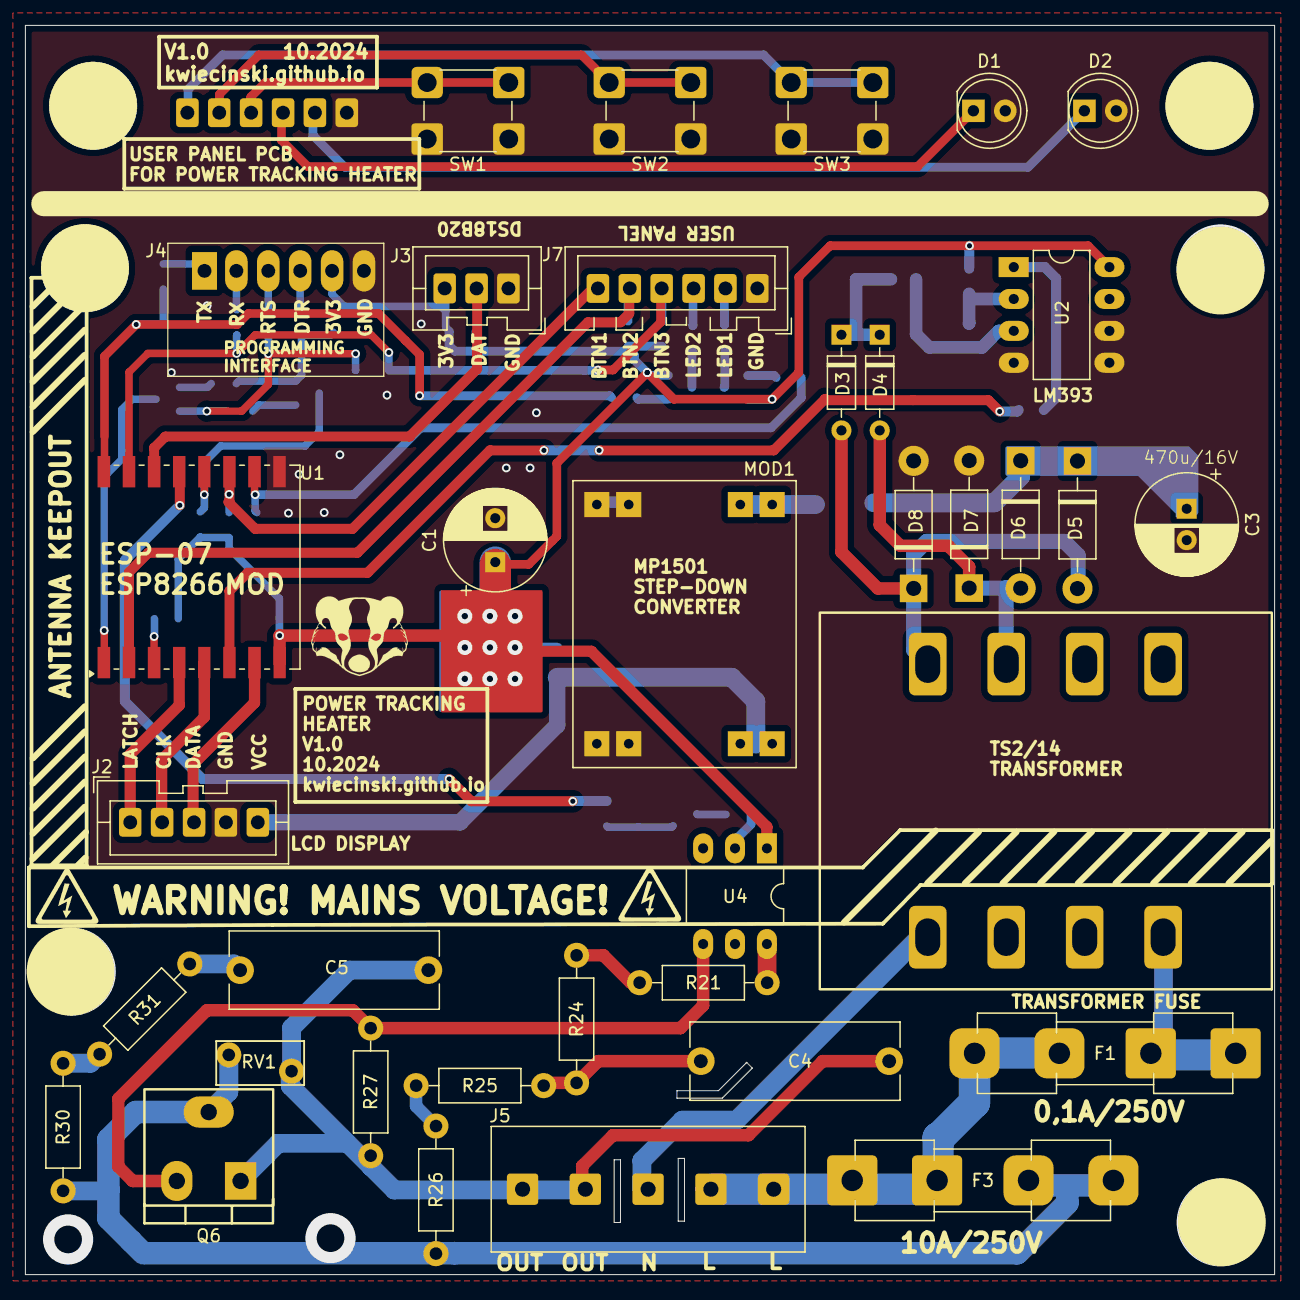
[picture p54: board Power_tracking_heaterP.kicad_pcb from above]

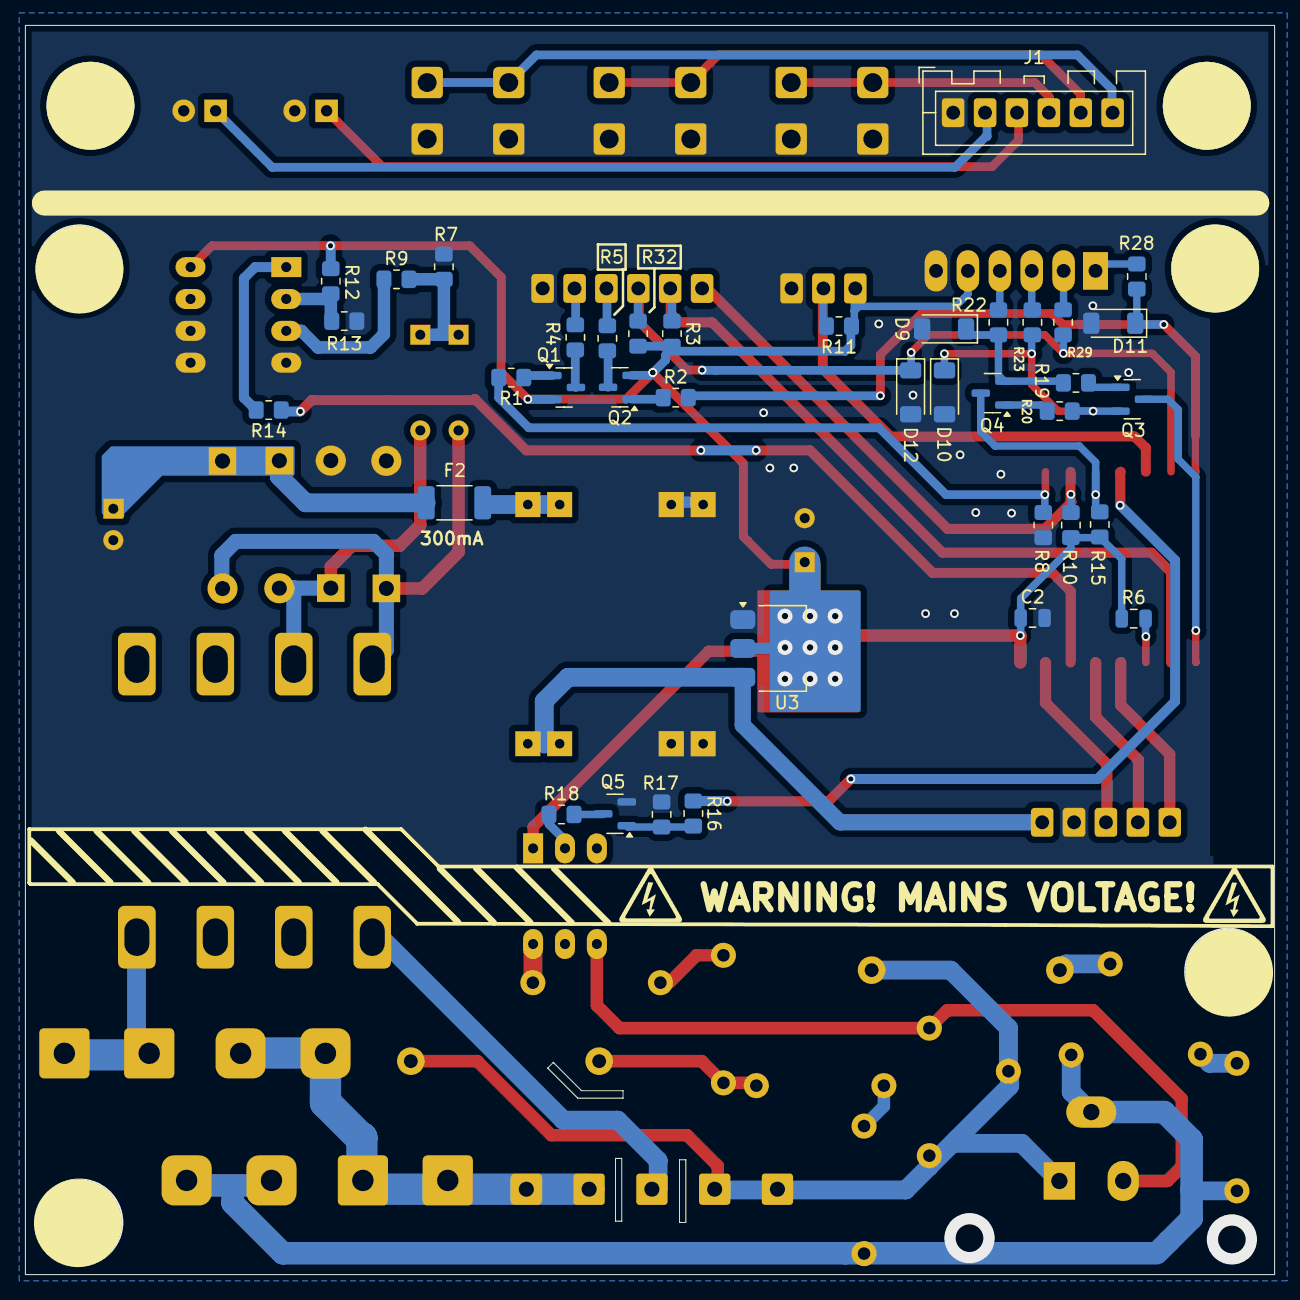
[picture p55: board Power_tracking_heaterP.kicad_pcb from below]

Board: 2 copper layers, 99.5 x 99.5 mm, 74 parts (38 on the bottom side), 59 nets.

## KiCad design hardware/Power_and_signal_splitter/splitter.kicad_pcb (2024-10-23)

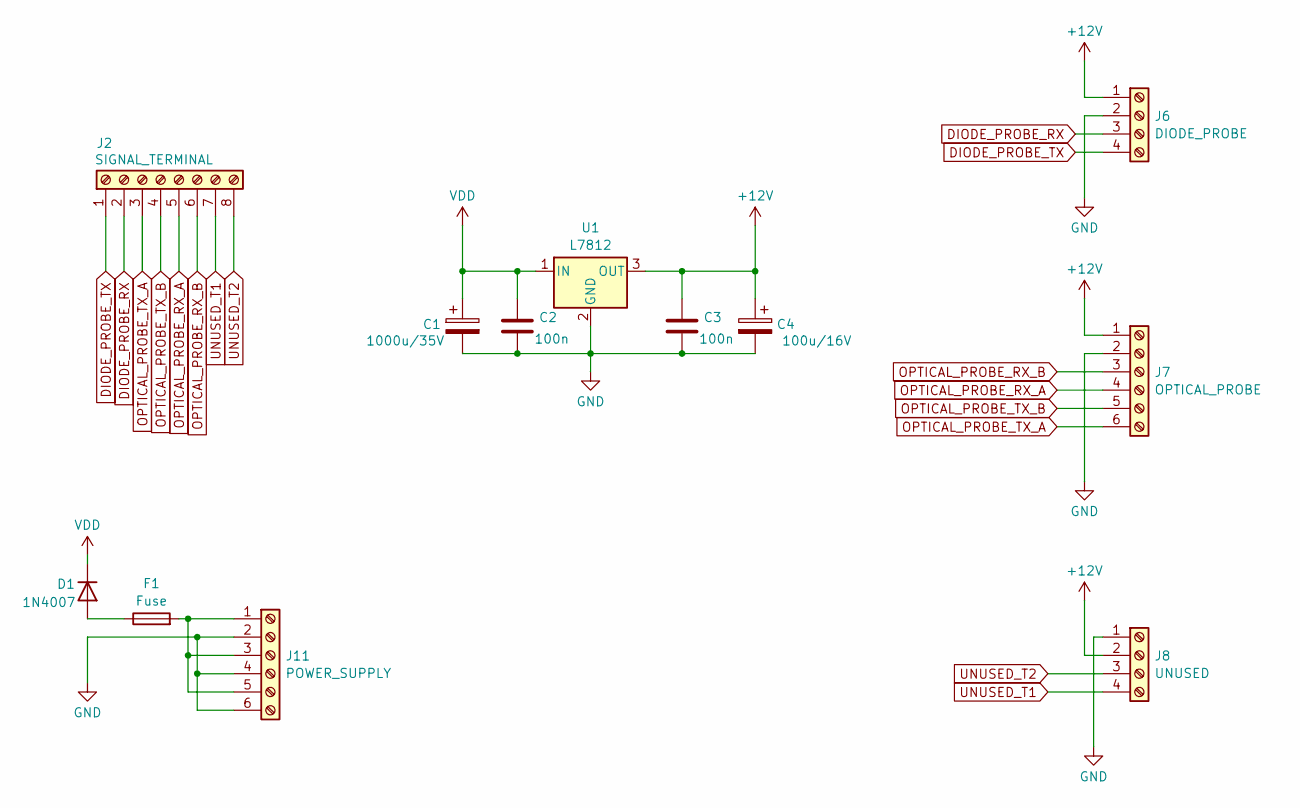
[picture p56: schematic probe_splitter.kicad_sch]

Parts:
C1: 1000u/35V; CP_Radial_D10.0mm_P5.00mm
C2, C3: 100n; C_Disc_D4.7mm_W2.5mm_P5.00mm
C4: 100u/16V; CP_Radial_D6.3mm_P2.50mm
D1: 1N4007; D_DO-41_SOD81_P10.16mm_Horizontal
F1: Fuse; Fuseholder_Clip-5x20mm_Eaton_1A5601-01_Inline_P20.80x6.76mm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
J2: SIGNAL_TERMINAL; WAGO-255-8P
J6: DIODE_PROBE; WAGO-739-4P
J7: OPTICAL_PROBE; HDQ-250-6P
J8: UNUSED; WAGO-739-4P
J11: POWER_SUPPLY; Screw-Terminal-P6-rast-5mm-6,7x30
U1: L7812; TO-220-3_Vertical

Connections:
+12V: C3.1, C4.1, J6.1, J7.1, J8.2, U1.3 (OUT)
DIODE_PROBE_RX: J2.2, J6.3
DIODE_PROBE_TX: J2.1, J6.4
GND: C1.2, C2.2, C3.2, C4.2, J6.2, J7.2, J8.1, J11.2, J11.4, J11.6, U1.2 (GND)
unnamed: D1.2 (A), F1.1
unnamed: F1.2, J11.1, J11.3, J11.5
OPTICAL_PROBE_RX_A: J2.5, J7.4
OPTICAL_PROBE_RX_B: J2.6, J7.3
OPTICAL_PROBE_TX_A: J2.3, J7.6
OPTICAL_PROBE_TX_B: J2.4, J7.5
UNUSED_T1: J2.7, J8.4
UNUSED_T2: J2.8, J8.3
VDD: C1.1, C2.1, D1.1 (K), U1.1 (IN)

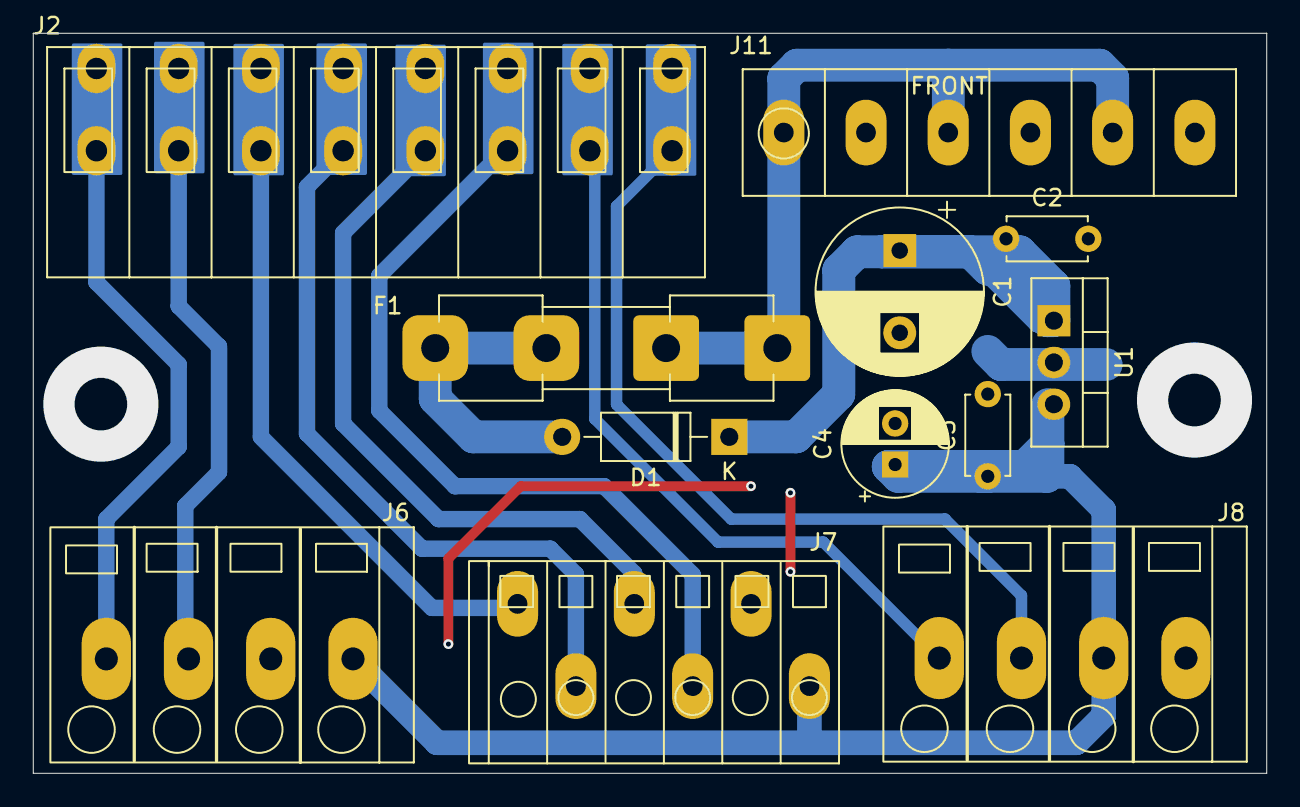
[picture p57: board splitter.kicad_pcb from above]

Board: 2 copper layers, 75.0 x 45.0 mm, 12 parts (0 on the bottom side), 13 nets.

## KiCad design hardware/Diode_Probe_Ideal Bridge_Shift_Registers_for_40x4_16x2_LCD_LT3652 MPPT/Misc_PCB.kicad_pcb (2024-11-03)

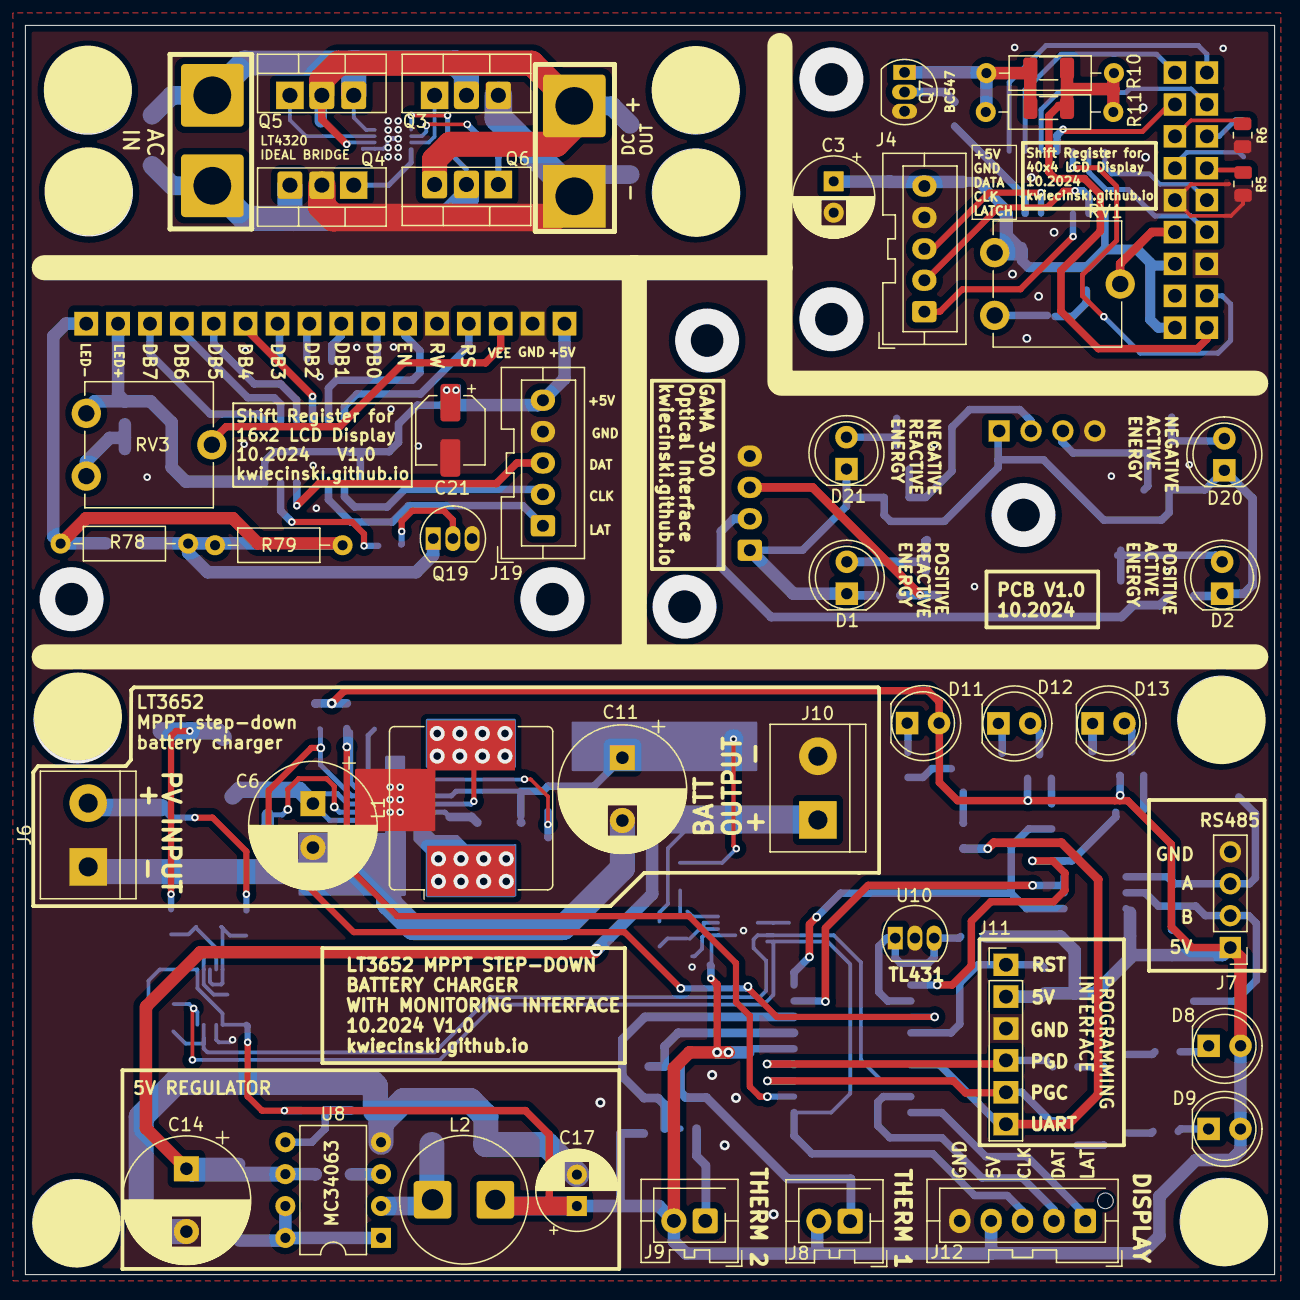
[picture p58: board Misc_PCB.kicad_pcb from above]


Board: 2 copper layers, 99.5 x 99.5 mm, 152 parts (106 on the bottom side), 110 nets.

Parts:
C1, C2, C19, C20: 470u/6,3V; CP_EIA-3528-21_Kemet-B
C3: 470u/6,3V; CP_Radial_D6.3mm_P2.50mm
C4, C13, C22: 100n; C_0805_2012Metric
C5, C9, C15: 100n; C_0805_2012Metric_Pad1.18x1.45mm_HandSolder
C6: 470u/40V; CP_Radial_D10.0mm_P3.50mm
C7, C12, C18, C23: 100n; R_0805_2012Metric_Pad1.20x1.40mm_HandSolder
C8: 0R; C_0805_2012Metric_Pad1.18x1.45mm_HandSolder
C10: 1u/10V; C_0805_2012Metric_Pad1.18x1.45mm_HandSolder
C11: 470u/16V; CP_Radial_D10.0mm_P5.00mm
C14: 670u/35V; CP_Radial_D10.0mm_P5.00mm
C16: 100p; C_0805_2012Metric_Pad1.18x1.45mm_HandSolder
C17: 560u/6,3V; CP_Radial_D6.3mm_P2.50mm
C21: 470u/6,3V; CP_Elec_5x5.7
C24: 1u/100v; C_1206_3216Metric
D1, D2, D20, D21: BPV10; LED_D5.0mm
D3, D6, D10: D_Schottky; D_SMB
D4, D5: D_TVS; D_SMA
D7: 1N4148; D_MiniMELF
D8, D9, D11, D12, D13: LED; LED_D5.0mm
D14: SMAJ60A; D_SMA
D15: SMAJ60CA; D_SMA
J1: DIODE_BLINK_METER; JST_XH_B4B-XH-A_1x04_P2.50mm_Vertical
J2: AC_IN; SolderWire-2.5sqmm_1x02_P7.2mm_D2.4mm_OD3.6mm
J3: DC_OUT; SolderWire-2.5sqmm_1x02_P7.2mm_D2.4mm_OD3.6mm
J4, J19: LCD_CONN; JST_XA_B05B-XASK-1_1x05_P2.50mm_Vertical
J5: LCD_DISPLAY; PinHeader_2x09_P2.54mm_Vertical
J6: SOLAR_PANEL; TerminalBlock_bornier-2_P5.08mm
J7: RS485; PinHeader_1x04_P2.54mm_Vertical
J8, J9: THERMISTOR; JST_XA_B02B-XASK-1-A_1x02_P2.50mm_Vertical
J10: BATT; TerminalBlock_bornier-2_P5.08mm
J11: ICP; PinHeader_1x06_P2.54mm_Vertical
J12: LCD_DISPLAY; JST_XA_B05B-XASK-1-A_1x05_P2.50mm_Vertical
J13: DIODE_BLINK_METER_OUT; PinHeader_1x04_P2.54mm_Vertical
J20: LCD16x2; PinSocket_1x16_P2.54mm_Vertical
L1: L; L_Bourns_SRR1208_12.7x12.7mm
L2: 220uH; L_Radial_D10.0mm_P5.00mm_Fastron_07P
Q1, Q2, Q8, Q9, Q10, Q13, Q14: BC817; SOT-23
Q3, Q4, Q5, Q6: IRF540N; TO-220-3_Vertical-little-bigger pads
Q7, Q19: BC547; TO-92_Inline_LITTLE_BIGGER
Q11, Q12: BC807; SOT-23
R1, R2, R48, R49: 47k; R_0805_2012Metric_Pad1.20x1.40mm_HandSolder
R3, R4, R50, R51: 22k; R_0805_2012Metric_Pad1.20x1.40mm_HandSolder
R5, R6, R7, R8, R9, R15, R71, R73, R74, R75, R76, R77: 10k; R_0805_2012Metric
R10, R11, R78, R79: R; R_Axial_DIN0207_L6.3mm_D2.5mm_P10.16mm_Horizontal
R12, R13, R80, R81: R; R_1206_3216Metric
R14, R72: 39k; R_0805_2012Metric
R16, R52, R54, R55: 10R; R_0805_2012Metric_Pad1.20x1.40mm_HandSolder
R17, R30: 50m; R_2512_6332Metric_Pad1.40x3.35mm_HandSolder
R18, R20, R21, R22: 510R; R_0805_2012Metric_Pad1.20x1.40mm_HandSolder
R19: 120R; R_0805_2012Metric_Pad1.20x1.40mm_HandSolder
R23, R24, R31, R32, R33: 10k; R_0805_2012Metric_Pad1.20x1.40mm_HandSolder
R25, R29: 100K; R_0805_2012Metric_Pad1.20x1.40mm_HandSolder
R26, R27: 100k; R_0805_2012Metric_Pad1.20x1.40mm_HandSolder
R28: 50mR; R_2512_6332Metric_Pad1.40x3.35mm_HandSolder
R34, R36, R42, R44, R46: 10K; R_0805_2012Metric_Pad1.20x1.40mm_HandSolder
R35, R37, R43, R45, R47: 220R; R_0805_2012Metric_Pad1.20x1.40mm_HandSolder
R38: 500m; R_2512_6332Metric_Pad1.40x3.35mm_HandSolder
R39: 1k; R_0805_2012Metric_Pad1.20x1.40mm_HandSolder
R40: 10k; C_0805_2012Metric
R41: 3k3; C_0805_2012Metric
R53: 100m; R_2512_6332Metric_Pad1.40x3.35mm_HandSolder
RV1, RV3: 10k; Potentiometer_ACP_CA9-V10_Vertical
U1: LT4320xDD-1; DFN-8-1EP_3x3mm_P0.5mm_EP1.65x2.38mm
U2, U14: 74HC595; SOIC-16_3.9x9.9mm_P1.27mm
U3: ST485; SOIC-8_3.9x4.9mm_P1.27mm
U4, U7: INA226; VSSOP-10_3x3mm_P0.5mm
U5: LT3652EMSE; MSOP-12-1EP_3x4mm_P0.65mm_EP1.65x2.85mm
U6: LM358; SOIC-8_3.9x4.9mm_P1.27mm
U8: MC34063AP; DIP-8_W7.62mm
U9: PIC16F819-ISO; SOIC-18W_7.5x11.6mm_P1.27mm
U10: TL431LP; TO-92_Inline_LITTLE_BIGGER

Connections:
+5V: C1.1, C2.1, C3.1, C4.1, C5.1, C7.1, C9.1, C12.1, C15.1, C17.1, C19.1, C20.1, C21.1, C22.1, D1.1 (K), D2.1 (K), D8.2 (A), D9.2 (A), D11.2 (A), D20.1 (K), D21.1 (K), J1.1, J4.5, J5.14, J5.18, J7.1, J8.2, J9.2, J11.2, J12.4, J13.1, J19.5, J20.1, J20.15, L2.2, Q11.2 (E), Q12.2 (E), R3.1, R4.1, R15.2, R18.1, R23.1, R24.1, R31.1, R32.1, R33.1, R39.1, R40.1, R50.1, R51.1, R71.2, RV1.3, RV3.3, U2.10 (~SRCLR), U2.16 (VCC), U3.8 (VCC), U4.1 (A1), U4.6 (VS), U6.8 (V+), U7.6 (VS), U9.14 (VDD), U14.10 (~SRCLR), U14.16 (VCC)
/LT3652 MPPT/RS485_A: D4.2 (A2), J7.3, R19.2, R20.1, U3.6 (A)
/LT3652 MPPT/RS485_B: D5.2 (A2), J7.2, R18.2, R19.1, U3.7 (B)
/Shift Register for 16x2 LCD Display/CLK: J19.2, U14.11 (SRCLK)
/Shift Register for 16x2 LCD Display/DATA: J19.3, U14.14 (SER)
/Shift Register for 16x2 LCD Display/LATCH: J19.1, U14.12 (RCLK)
/Shift Register for 40x4 LCD Display/CLK: J4.2, U2.11 (SRCLK)
/Shift Register for 40x4 LCD Display/DATA: J4.3, U2.14 (SER)
/Shift Register for 40x4 LCD Display/LATCH: J4.1, U2.12 (RCLK)
BACKLIGHT_DRIVE: R9.1, U2.15 (QA)
BACKLIGHT_DRIVE_A: R73.1, U14.15 (QA)
BATT_CURRENT_HIGH: C11.1, D7.2 (A), R26.2, R28.2, R30.1, R53.1, R54.2, U5.9 (BAT)
BATT_CURRENT_LOW: C13.1, C14.1, J10.1, R30.2, R38.1, R53.2, R55.1, U8.6 (Vin)
CHRG: R23.2, U5.4 (~CHRG), U9.3 (T0CKL/AN4/RA4)
DATA: J12.2, U9.8 (RB2/SDO/CCP1)
DB0: J5.8, R8.2
DB1: J5.7, R5.2
DB2: J5.6, R6.2
DB3: J5.5, R7.2
DB4: J5.4, U2.4 (QE)
DB4_A: J20.11, U14.4 (QE)
DB5: J5.3, U2.3 (QD)
DB5_A: J20.12, U14.3 (QD)
DB6: J5.2, U2.2 (QC)
DB6_A: J20.13, U14.2 (QC)
DB7: J5.1, U2.1 (QB)
DB7_A: J20.14, U14.1 (QB)
DBG_UART: J11.6, R42.2, U9.6 (RB0/INT)
E1: J5.9, U2.7 (QH)
E2: J5.15, U2.5 (QF)
EN: J20.6, U14.5 (QF)
FAULT: R24.2, U5.5 (~FAULT), U9.11 (RB5/~SS)
GND: C1.2, C2.2, C3.2, C4.2, C5.2, C6.2, C7.2, C8.2, C9.2, C11.2, C12.2, C13.2, C14.2, C15.2, C16.2, C17.2, C19.2, C20.2, C21.2, C22.2, C24.2, D4.1 (A1), D5.1 (A1), D6.2 (A), D10.2 (A), D14.2 (A2), J1.4, J3.2, J4.4, J5.10, J5.13, J6.1, J7.4, J10.2, J11.3, J12.5, J13.4, J19.4, J20.2, J20.5, Q1.2 (E), Q2.2 (E), Q3.3 (S), Q4.2 (D), Q7.3 (E), Q8.2 (E), Q9.2 (E), Q10.2 (E), Q13.2 (E), Q14.2 (E), Q19.3 (E), R1.2, R2.2, R5.1, R6.1, R7.1, R8.1, R14.2, R20.2, R22.2, R25.2, R27.1, R29.2, R41.2, R45.1, R47.1, R48.2, R49.2, R72.2, R74.1, R75.1, R76.1, R77.1, U1.5 (OUTN), U1.9 (OUTN), U2.8 (GND), U2.13 (~OE), U3.5 (GND), U4.2 (A0), U4.7 (GND), U5.13 (GND), U6.4 (V-), U7.1 (A1), U7.2 (A0), U7.7 (GND), U8.4 (GND), U9.5 (VSS), U10.2 (A), U14.8 (GND), U14.13 (~OE)
LATCH: J12.1, U9.9 (RB3/CCP1/PGM)
unnamed: D1.2 (A), Q1.1 (B), R1.1
unnamed: D2.2 (A), Q2.1 (B), R2.1
unnamed: C6.1, D3.1 (K), R21.1, U5.1 (V_{IN}), U5.3 (~SHDN)
unnamed: C10.1, D6.1 (K), L1.1, U5.12 (SW)
unnamed: C10.2, D7.1 (K), U5.11 (BOOST)
unnamed: D8.1 (K), R35.2
unnamed: D9.1 (K), R37.2
unnamed: D10.1 (K), L2.1, U8.2 (SwE)
unnamed: D11.1 (K), R43.2
unnamed: D12.2 (A), Q11.3 (C)
unnamed: D12.1 (K), R45.2
unnamed: D13.2 (A), Q12.3 (C)
unnamed: D13.1 (K), R47.2
unnamed: C24.1, D14.1 (A1), J3.1, Q5.2 (D), Q6.3 (S), U1.6 (OUTP)
unnamed: D15.1 (A1), J2.1, Q4.3 (S), Q6.2 (D), U1.1 (IN2)
unnamed: D15.2 (A2), J2.2, Q3.2 (D), Q5.3 (S), U1.8 (IN1)
unnamed: D20.2 (A), Q13.1 (B), R48.1
unnamed: D21.2 (A), Q14.1 (B), R49.1
unnamed: J1.2, Q2.3 (C), R4.2
unnamed: J1.3, Q1.3 (C), R3.2
unnamed: J5.12, RV1.2
unnamed: J5.17, R10.1, R11.1, R12.1, R13.1
unnamed: J8.1, R25.1, U6.3 (+)
unnamed: J9.1, R29.1, U6.5 (+)
unnamed: J13.2, Q14.3 (C), R51.2
unnamed: J13.3, Q13.3 (C), R50.2
unnamed: J20.3, RV3.2
unnamed: J20.7, R74.2
unnamed: J20.8, R75.2
unnamed: J20.9, R76.2
unnamed: J20.10, R77.2
unnamed: J20.16, R78.1, R79.1, R80.1, R81.1
unnamed: Q3.1 (G), U1.3 (BG2)
unnamed: Q4.1 (G), U1.4 (BG1)
unnamed: Q5.1 (G), U1.7 (TG1)
unnamed: Q6.1 (G), U1.2 (TG2)
unnamed: Q7.2 (B), R9.2
unnamed: Q7.1 (C), R10.2, R11.2, R12.2, R13.2
unnamed: Q8.1 (B), R34.1
unnamed: Q8.3 (C), R35.1
unnamed: Q9.1 (B), R36.1
unnamed: Q9.3 (C), R37.1
unnamed: Q10.1 (B), R42.1
unnamed: Q10.3 (C), R43.1
unnamed: Q11.1 (B), R44.1
unnamed: Q12.1 (B), R46.1
unnamed: Q19.2 (B), R73.2
unnamed: Q19.1 (C), R78.2, R79.2, R80.2, R81.2
unnamed: R14.1, R15.1, RV1.1
unnamed: R71.1, R72.1, RV3.1
unnamed: C18.1, R16.1, U4.8 (Vbus), U4.10 (Vin+)
unnamed: C18.2, R52.2, U4.9 (Vin-)
unnamed: L1.2, R28.1, U5.10 (SENSE)
unnamed: C8.1, U5.6 (TIMER)
unnamed: R26.1, R27.2, U5.7 (V_{FB})
unnamed: R21.2, R22.1, U5.2 (V_{IN_REG})
unnamed: C23.2, R55.2, U7.8 (Vbus), U7.9 (Vin-)
unnamed: C23.1, R54.1, U7.10 (Vin+)
unnamed: R38.2, U8.1 (SwC), U8.7 (Ipk), U8.8 (DC)
unnamed: C16.1, U8.3 (TC)
unnamed: R40.2, R41.1, U8.5 (Vfb)
PGC: J11.5, R36.2, U9.12 (RB6/T1OSO/T1CKI/PGC)
PGD: J11.4, R34.2, U9.13 (RB7/T1OSI/PGD)
RS: J5.11, U2.6 (QG)
RS232_RX: R44.2, U3.1 (RO), U9.18 (AN1/RA1)
RS232_TX: R46.2, U3.4 (DI), U9.1 (Vref-/AN2/RA2)
RS485_OUTPUT_ENABLE: U3.2 (~RE), U3.3 (DE), U9.17 (AN0/RA0)
RST: J11.1, R33.2, U9.4 (Vpp/~MCLR/RA5)
RS_A: J20.4, U14.6 (QG)
SCL_SCK: J12.3, R32.2, U4.5 (SCL), U7.5 (SCL), U9.10 (RB4/SCK/SCL)
SDA: R31.2, U4.4 (SDA), U7.4 (SDA), U9.7 (RB1/SDI/SDA)
SOLAR_CURRENT_HIGH: J6.2, R16.2, R17.1
SOLAR_CURRENT_LOW: D3.2 (A), R17.2, R52.1
TEMP1: U6.1, U6.2 (-), U9.15 (CLKO/OSC2/RA6)
TEMP2: U6.6 (-), U6.7, U9.16 (CLKI/OSC1/RA7)
VREF_2V5: R39.2, U9.2 (Vref+/AN3/RA3), U10.1 (REF), U10.3 (K)

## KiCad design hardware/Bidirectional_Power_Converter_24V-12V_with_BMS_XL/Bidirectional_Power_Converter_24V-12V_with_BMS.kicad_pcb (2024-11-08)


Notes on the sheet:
12V
PV BATTERY
Bidirectional Buck-boost DC-DC converter

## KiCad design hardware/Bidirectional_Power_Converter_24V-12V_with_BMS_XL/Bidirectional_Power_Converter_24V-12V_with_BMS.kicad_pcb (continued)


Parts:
C1, C2, C35: 100n; R_0805_2012Metric_Pad1.20x1.40mm_HandSolder
C3, C6, C34: 1000u/35V; CP_Radial_D10.0mm_P3.50mm
C4: 10n; R_0805_2012Metric_Pad1.20x1.40mm_HandSolder
C5, C7: 100n; C_0805_2012Metric_Pad1.18x1.45mm_HandSolder
D2: LL4148; D_MiniMELF
D3: 3V3; D_MiniMELF
D4: LED; LED_D3.0mm
D5: D_Schottky_Dual; TO-220-3_Vertical-little-bigger pads
L1: 47u; L_Toroid_Vertical_L28.6mm_W14.3mm_P11.43mm_Bourns_5700
Q1: BC807; SOT-23
R13, R15, R16, R23: 1k; R_0805_2012Metric_Pad1.20x1.40mm_HandSolder
R14: 39k; R_0805_2012Metric_Pad1.20x1.40mm_HandSolder
R17: 100k; R_0805_2012Metric_Pad1.20x1.40mm_HandSolder
R18: 2,7k; R_0805_2012Metric_Pad1.20x1.40mm_HandSolder
R19: 0R; R_0805_2012Metric_Pad1.20x1.40mm_HandSolder
R20: 240R; R_0805_2012Metric_Pad1.20x1.40mm_HandSolder
R21: 1K; R_0805_2012Metric_Pad1.20x1.40mm_HandSolder
R22: 47k; R_0805_2012Metric_Pad1.20x1.40mm_HandSolder
U1: LM358; SO-8_3.9x4.9mm_P1.27mm
U2: XL6019; TO-263-5_TabPin3

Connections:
+5V: Q1.2 (E); also elsewhere on the board
+10V: C1.1, U1.8 (V+); also elsewhere on the board
-5V: C35.1, U1.4 (V-); also elsewhere on the board
BATT_CURRENT_SHUNT_FB: R13.2; also elsewhere on the board
BATT_VOLTAGE_POSITIVE: C3.1, C5.1, L1.1, U2.4 (VIN); also elsewhere on the board
BUCK_CURRENT_FB: C2.1, D3.1 (K), R15.1, U1.3 (+); also elsewhere on the board
ENABLE_BUCK: R23.2; also elsewhere on the board
GND: C1.2, C2.2, C3.2, C5.2, C6.2, C7.2, C34.2, C35.2, D3.2 (A), R17.2, R20.1, R21.2, R22.2, U1.5 (+), U2.1 (GND); also elsewhere on the board
unnamed: D2.2 (A), U1.7
unnamed: D2.1 (K), R14.2, R15.2
unnamed: C4.1, D4.2 (A), U1.1
unnamed: D4.1 (K), R19.1, R20.2, U2.5 (FB)
unnamed: D5.2 (A), L1.2, U2.3 (SW)
unnamed: Q1.1 (B), R22.1, R23.1
unnamed: Q1.3 (C), R21.1, U2.2 (EN)
unnamed: R18.1, R19.2
unnamed: C4.2, R16.2, R17.1, U1.2 (-)
unnamed: R13.1, R14.1, U1.6 (-)
PV_VOLTAGE_POSITIVE: C6.1, C7.1, C34.1, D5.1 (K), D5.3 (K), R18.2; also elsewhere on the board
VREF_2.5V: R16.1; also elsewhere on the board

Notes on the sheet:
CONSTANT CURRENT LED
Rshunt=12,5mR Imax=5A Ushunt=Imax*Rshunt=62,5mV Ushunt=62,5mV Vadc_max=2,5V G=Vadc_max/Ushunt G=40 Gopamp = R31/R28
Vout=2,7k/240R=14,06V
TL494 BOOST CONVERTER
CURRENT FLOW


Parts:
D1: 3V3; D_MiniMELF
F1, F2: Fuse; Fuseholder_Clip-5x20mm_Eaton_1A5601-01_Inline_P20.80x6.76mm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
J1: V_IN; Flat-6,3mm-connector-4P
J2: V_OUT; Flat-6,3mm-connector-4P
R1: 10k; R_0805_2012Metric_Pad1.20x1.40mm_HandSolder
R2: R; R_0805_2012Metric_Pad1.20x1.40mm_HandSolder
R3: 50mR; R_2512_6332Metric_Pad1.40x3.35mm_HandSolder
R4, R5, R6: 50m; R_2512_6332Metric_Pad1.40x3.35mm_HandSolder
R7, R10: 100mR; R_2512_6332Metric_Pad1.40x3.35mm_HandSolder
R8, R9: R; R_2512_6332Metric_Pad1.40x3.35mm_HandSolder

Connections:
BATT_CURRENT_SHUNT_FB: J1.1, J1.2, R3.1, R4.1, R5.1, R6.1; also elsewhere on the board
BATT_VOLTAGE_FB: D1.1 (K), R1.1, R2.2; also elsewhere on the board
BATT_VOLTAGE_POSITIVE: F1.2, R1.2; also elsewhere on the board
GND: D1.2 (A), J2.3, J2.4, R2.1, R3.2, R4.2, R5.2, R6.2; also elsewhere on the board
unnamed: F1.1, J1.3, J1.4
unnamed: F2.2, J2.1, J2.2
PV_CURRENT_SHUNT_FB: F2.1, R7.2, R8.2, R9.2, R10.2; also elsewhere on the board
PV_VOLTAGE_POSITIVE: R7.1, R8.1, R9.1, R10.1; also elsewhere on the board

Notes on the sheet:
BATTERY INPUT
PV BATTERY OUTPUT
50m/4=12,5mR


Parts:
C8, C9, C13: 100n; R_0805_2012Metric_Pad1.20x1.40mm_HandSolder
C10, C15: 100n; C_0805_2012Metric_Pad1.18x1.45mm_HandSolder
C11, C14: 1000u/35V; CP_Radial_D10.0mm_P3.50mm
C12: 10n; R_0805_2012Metric_Pad1.20x1.40mm_HandSolder
D6: LL4148; D_MiniMELF
D7: 3V3; D_MiniMELF
D8: LED; LED_D3.0mm
D28: D_Schottky_Dual; TO-220-3_Vertical-little-bigger pads
L2: 47u; L_Toroid_Vertical_L28.6mm_W14.3mm_P11.43mm_Bourns_5700
Q2: BC807; SOT-23
R24, R26, R27, R33: 1k; R_0805_2012Metric_Pad1.20x1.40mm_HandSolder
R25: 39k; R_0805_2012Metric_Pad1.20x1.40mm_HandSolder
R28: 100k; R_0805_2012Metric_Pad1.20x1.40mm_HandSolder
R29: 2,7k; R_0805_2012Metric_Pad1.20x1.40mm_HandSolder
R30: 0R; R_0805_2012Metric_Pad1.20x1.40mm_HandSolder
R31: 240R; R_0805_2012Metric_Pad1.20x1.40mm_HandSolder
R32: 47k; R_0805_2012Metric_Pad1.20x1.40mm_HandSolder
U3: LM358; SO-8_3.9x4.9mm_P1.27mm
U4: XL4015; TO-263-5_TabPin3

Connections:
+5V: Q2.2 (E); also elsewhere on the board
+10V: C8.1, U3.8 (V+); also elsewhere on the board
-5V: U3.4 (V-); also elsewhere on the board
BATT_CURRENT_SHUNT_FB: R24.2; also elsewhere on the board
BATT_VOLTAGE_POSITIVE: C14.1, C15.1, L2.2, R29.2; also elsewhere on the board
BUCK_CURRENT_FB: C9.1, D7.1 (K), R26.1, U3.3 (+); also elsewhere on the board
ENABLE_BUCK: R33.2; also elsewhere on the board
GND: C8.2, C9.2, C10.2, C11.2, C13.2, C14.2, C15.2, D7.2 (A), D28.2 (A), R28.2, R31.1, R32.2, U3.5 (+), U4.1 (GND); also elsewhere on the board
unnamed: D6.2 (A), U3.7
unnamed: D6.1 (K), R25.2, R26.2
unnamed: C12.1, D8.2 (A), U3.1
unnamed: D8.1 (K), Q2.3 (C), R30.1, R31.2, U4.2 (FB)
unnamed: Q2.1 (B), R32.1, R33.1
unnamed: R29.1, R30.2
unnamed: C12.2, R27.2, R28.1, U3.2 (-)
unnamed: R24.1, R25.1, U3.6 (-)
unnamed: D28.1 (K), D28.3 (K), L2.1, U4.3 (SW)
unnamed: C13.1, U4.4 (VC)
PV_VOLTAGE_POSITIVE: C10.1, C11.1, U4.5 (VIN); also elsewhere on the board
VREF_2.5V: R27.1; also elsewhere on the board

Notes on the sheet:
Vout=2,7k/240R=14,06V
CONSTANT CURRENT LED
CURRENT FLOW
Rshunt=12,5mR Imax=5A Ushunt=Imax*Rshunt=62,5mV Ushunt=62,5mV Vadc_max=2,5V G=Vadc_max/Ushunt G=40 Gopamp = R31/R28
TL494 BUCK CONVERTER



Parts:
C16: 1u; C_0805_2012Metric_Pad1.18x1.45mm_HandSolder
C17, C19, C20, C22, C26, C27, C28, C29, C31: 100n; C_0805_2012Metric_Pad1.18x1.45mm_HandSolder
C18: 470u/35V; CP_Radial_D8.0mm_P3.50mm
C21, C25: 22u/6,3V; CP_Radial_D5.0mm_P2.00mm
C23: 100u/10V; CP_Radial_D8.0mm_P3.50mm
C24: 10u/10V; CP_Radial_D5.0mm_P2.00mm
C30, C33: 100n; R_0805_2012Metric_Pad1.20x1.40mm_HandSolder
C32: 47u/16V; CP_Radial_D5.0mm_P2.00mm
D10, D11, D12, D13, D14, D15, D16, D17, D22, D23, D24, D25, D26, D27: LED; LED_D3.0mm
D18, D19: D_TVS; D_SMA
D20, D21: 3V3; D_MiniMELF
J3: ICP; PinHeader_1x06_P2.54mm_Vertical
J4: RS485; PinHeader_1x04_P2.54mm_Vertical
J5: TEMP_BATT; JST_EH_B3B-EH-A_1x03_P2.50mm_Vertical
J6: TEMP_BUCK; JST_EH_B3B-EH-A_1x03_P2.50mm_Vertical
Q3, Q5, Q6, Q7: BC817; SOT-23
Q4, Q8: BC807; SOT-23
R34, R35, R36, R37, R38, R39, R40, R41, R47: 120R; R_0805_2012Metric_Pad1.20x1.40mm_HandSolder
R42, R53, R54: 1k; R_0805_2012Metric_Pad1.20x1.40mm_HandSolder
R43, R49, R50: 10k; R_0805_2012Metric_Pad1.20x1.40mm_HandSolder
R44: 1k6; R_0805_2012Metric_Pad1.20x1.40mm_HandSolder
R45: 240R; R_0805_2012Metric_Pad1.20x1.40mm_HandSolder
R46, R48: 510R; R_0805_2012Metric_Pad1.20x1.40mm_HandSolder
R51, R52: 150k; R_0805_2012Metric_Pad1.20x1.40mm_HandSolder
R55, R56, R57, R61, R62, R65: 10K; R_0805_2012Metric_Pad1.20x1.40mm_HandSolder
R58, R59, R60, R63, R64, R66: 220R; R_0805_2012Metric_Pad1.20x1.40mm_HandSolder
U5: LM7805_TO220; TO-220-3_Vertical
U6: PIC16F886-IP; SOIC-28W_7.5x17.9mm_P1.27mm
U7: ICL7660; SOIC-8_3.9x4.9mm_P1.27mm
U8: TL431LP; SOT-23_Handsoldering
U9: LM317_TO-220; TO-220-3_Vertical
U10: ST485; SOIC-8_3.9x4.9mm_P1.27mm
U11: INA226; VSSOP-10_3x3mm_P0.5mm
U12: LM358; SOIC-8_3.9x4.9mm_P1.27mm

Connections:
+5V: C16.1, C17.1, C19.1, C21.1, C22.1, C23.1, C28.1, C30.1, D22.1 (K), D24.1 (K), D25.1 (K), D26.1 (K), J3.2, J4.1, Q4.2 (E), Q8.2 (E), R42.2, R43.1, R46.1, R49.1, R50.1, R51.1, R52.1, U5.3 (VO), U6.20 (VDD), U7.8 (V+), U10.8 (VCC), U11.6 (VS); also elsewhere on the board
+10V: C31.1, C32.2, C33.1, R45.2, U9.2 (VO), U12.8 (V+); also elsewhere on the board
-5V: C25.2, C26.1, U7.5 (VOUT); also elsewhere on the board
/Bidirectional Power Supply/Microcontroller/RS485_A: D18.2 (A2), J4.3, R47.2, R48.1, U10.6 (A)
/Bidirectional Power Supply/Microcontroller/RS485_B: D19.2 (A2), J4.2, R46.2, R47.1, U10.7 (B)
BATT_VOLTAGE_FB: U6.2 (ULPWU/C12IN0-/AN0/RA0); also elsewhere on the board
BATT_VOLTAGE_POSITIVE: C18.1, C20.1, C27.1, U5.1 (VI), U9.3 (VI); also elsewhere on the board
BOOST_CURRENT_FB: U6.3 (C12IN1-/AN1/RA1)
BUCK_CURRENT_FB: U6.4 (CVref/C2IN1+/Vref-/AN2/RA2); also elsewhere on the board
CLOCK: R50.2, U6.14 (RC3/SCK/SCL), U11.5 (SCL)
DBG_LED_6: J3.6, R34.2, U6.26 (~T1G/AN13/RB5)
ENABLE_BOOST: R55.2, U6.9 (CLKIN/OSC1/RA7)
ENABLE_BUCK: R61.2, U6.10 (CLKOUT/OSC2/RA6); also elsewhere on the board
FAN_HEATSINK: U6.13 (RC2/P1A/CCP1)
GND: C16.2, C17.2, C18.2, C19.2, C20.2, C21.2, C22.2, C23.2, C25.1, C26.2, C27.2, C28.2, C29.2, C30.2, C31.2, C32.1, C33.2, D10.1 (K), D11.1 (K), D12.1 (K), D13.1 (K), D14.1 (K), D15.1 (K), D16.1 (K), D17.1 (K), D18.1 (A1), D19.1 (A1), D20.2 (A), D21.2 (A), J3.3, J4.4, J5.1, J6.1, Q3.2 (E), Q5.2 (E), Q6.2 (E), Q7.2 (E), R44.2, R48.2, R59.1, R66.1, U5.2 (GND), U6.8 (VSS), U6.19 (VSS), U7.3 (GND), U8.2 (A), U10.5 (GND), U11.1 (A1), U11.2 (A0), U11.7 (GND), U12.4 (V-); also elsewhere on the board
LED_1: R39.2, U6.21 (INT/AN12/RB0)
LED_2: R38.2, U6.22 (P1C/AN10/RB1)
LED_3: R37.2, U6.23 (P1B/AN8/RB2)
LED_4: R36.2, U6.24 (PGM/C12IN2-/AN8/RB3)
LED_5: R35.2, U6.25 (P1D/AN11/RB4)
LED_7: R40.2, U6.11 (RC0/T1OSO/T1CK1)
LED_8: R41.2, U6.12 (RC1/T1OSI/CCP2)
unnamed: D10.2 (A), R34.1
unnamed: D11.2 (A), R35.1
unnamed: D12.2 (A), R36.1
unnamed: D13.2 (A), R37.1
unnamed: D14.2 (A), R38.1
unnamed: D15.2 (A), R39.1
unnamed: D16.2 (A), R40.1
unnamed: D17.2 (A), R41.1
unnamed: D22.2 (A), R58.2
unnamed: D23.2 (A), Q4.3 (C)
unnamed: D23.1 (K), R59.2
unnamed: D24.2 (A), R60.2
unnamed: D25.2 (A), R63.2
unnamed: D26.2 (A), R64.2
unnamed: D27.2 (A), Q8.3 (C)
unnamed: D27.1 (K), R66.2
unnamed: J5.3, R52.2, U12.6 (-)
unnamed: J6.3, R51.2, U12.2 (-)
unnamed: Q3.1 (B), R55.1
unnamed: Q3.3 (C), R58.1
unnamed: Q4.1 (B), R56.1
unnamed: Q5.1 (B), R57.1
unnamed: Q5.3 (C), R60.1
unnamed: Q6.1 (B), R61.1
unnamed: Q6.3 (C), R63.1
unnamed: Q7.1 (B), R62.1
unnamed: Q7.3 (C), R64.1
unnamed: Q8.1 (B), R65.1
unnamed: C24.1, U7.2 (CAP+)
unnamed: C24.2, U7.4 (CAP-)
unnamed: C29.1, R44.1, R45.1, U9.1 (ADJ)
unnamed: R53.1, U12.1, U12.3 (+)
unnamed: R54.1, U12.5 (+), U12.7
PGC_LED_STATUS_1: J3.5, R62.2, U6.27 (ICSPCLK/RB6)
PGD_LED_STATUS_2: J3.4, R57.2, U6.28 (ICSPDAT/RB7)
PV_CURRENT_SHUNT_FB: U11.8 (Vbus), U11.9 (Vin-); also elsewhere on the board
PV_VOLTAGE_POSITIVE: U11.10 (Vin+); also elsewhere on the board
RS232_RX: R56.2, U6.18 (RC7/RX/DT), U10.1 (RO)
RS232_TX: R65.2, U6.17 (RC6/TX/CK), U10.4 (DI)
RS485_OUTPUT_ENABLE: U6.16 (RC5/SDO), U10.2 (~RE), U10.3 (DE)
RST: J3.1, R43.2, U6.1 (RE3/~MCLR/Vpp)
SDA: R49.2, U6.15 (RC4/SDI/SDA), U11.4 (SDA)
TEMP_BATT: D21.1 (K), R54.2, U6.6 (T0CKI/C1OUT/RA4)
TEMP_HEATSINK: D20.1 (K), R53.2, U6.7 (~SS/C2OUT/AN4/RA5)
VREF_2.5V: R42.1, U6.5 (C1IN+/Vref+/AN3/RA3), U8.1 (REF), U8.3 (K); also elsewhere on the board

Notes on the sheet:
9,6V
PV line cuurent measument
10V regulator
5V regulator
TX/RX RS485 DIODES
Programming and debuging connector
BUCK/BOOST ENABLE DIODES
ICL7660: -5V Voltage Converter
/RE - Receiver Output Enable Active LOW
STATUS DIODES
ST485



Board: 2 copper layers, 99.5 x 99.5 mm, 156 parts (116 on the bottom side), 88 nets.

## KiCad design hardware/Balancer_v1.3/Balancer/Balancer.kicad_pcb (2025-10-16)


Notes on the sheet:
24V
DC_RAIL
12V
GND

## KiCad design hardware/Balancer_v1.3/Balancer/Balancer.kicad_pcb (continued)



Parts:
C20, C21, C28, C32, C33, C34, C39: 100n; C_0805_2012Metric_Pad1.18x1.45mm_HandSolder
C22, C25: 10u; C_0805_2012Metric_Pad1.18x1.45mm_HandSolder
C23: 470n; C_0805_2012Metric_Pad1.18x1.45mm_HandSolder
C24: 100u/6,3V (JA8); CP_EIA-3528-21_Kemet-B
C26: 220u/35V; CP_Radial_D8.0mm_P2.50mm
C27: 470u/16V; CP_Radial_D8.0mm_P2.50mm
C29: 220u/6,3V; CP_Radial_D8.0mm_P2.50mm
C30: 100u/25V; CP_Radial_D8.0mm_P2.50mm
C31, C38: 10u; C_1206_3216Metric
C35, C36, C37: 100n; R_0805_2012Metric_Pad1.20x1.40mm_HandSolder
D1, D2: LED; LED_D5.0mm
D19, D20: 1N4148; D_MiniMELF
D21, D22: D_TVS; Nexperia_CFP3_SOD-123W
D23, D24, D25: PTVS5V0Z1USK; D_SOD-123
F4: 2A; Fuse_2920_7451Metric_Pad2.10x5.45mm_HandSolder
H1, H3, H4, H5, H7, H9, H10: MountingHole; Mount-Hole-3mm
J1: batt-24V-balancer; PinSocket_1x04_P2.54mm_Vertical
J2: pwm-12v-local; PinSocket_1x04_P2.54mm_Vertical
J3: R-Shunt; PinHeader_1x02_P2.54mm_Vertical
J12: V_MEAS; JST_XA_1x03_P2.54mm_Vertical
J13: LED; JST_XH_B4B-XH-A_1x04_P2.50mm_Vertical
J14: ICP; JST_XA_1x03_P2.54mm_Vertical
J15, J16: RS485; Conn-01x04-N25-W4P
MOD1: LM2596-Step-Down; LM2596-Step-Down-Conv
Q1, Q2, Q21: BC817; SOT-23
R1, R3: 10K; R_0805_2012Metric_Pad1.20x1.40mm_HandSolder
R2, R4: 220R; R_0805_2012Metric_Pad1.20x1.40mm_HandSolder
R58, R74: 0R; R_0805_2012Metric_Pad1.20x1.40mm_HandSolder
R59: 6k8; R_0805_2012Metric_Pad1.20x1.40mm_HandSolder
R60, R62, R64, R65, R66: 1k; R_0805_2012Metric_Pad1.20x1.40mm_HandSolder
R61, R75, R76: 10k; R_0805_2012Metric_Pad1.20x1.40mm_HandSolder
R63, R68, R70: 510R; R_0805_2012Metric_Pad1.20x1.40mm_HandSolder
R67: 4k7; R_0805_2012Metric_Pad1.20x1.40mm_HandSolder
R69: 120R; R_0805_2012Metric_Pad1.20x1.40mm_HandSolder
R71, R72, R73: 10R; R_0805_2012Metric_Pad1.20x1.40mm_HandSolder
U4: AVR64DD28; SOIC-28W_7.5x17.9mm_P1.27mm
U5: LM317_TO-220; TO-220-3_Vertical-little-bigger pads
U6: LM7805_TO220; TO-220-3_Vertical-little-bigger pads
U7: TL432DBZ; SOT-23
U8: ADUM3211ARZ; SO-8_3.9x4.9mm_P1.27mm
U9: PC817; DIP-4_W7.62mm
U10: B0505S-1W; B0505S
U11: ST485; SOIC-8_3.9x4.9mm_P1.27mm
U12: INA226; VSSOP-10_3x3mm_P0.5mm

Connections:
+5V: C20.1, C21.1, C22.1, C29.1, C31.1, C32.1, C37.1, D1.2 (A), D2.2 (A), D20.2 (A), J13.1, R61.1, R63.1, R75.1, R76.1, U4.6 (VDDIO2), U4.14 (VDD), U4.20 (VDD), U6.3 (VO), U8.1 (VDD1), U9.1, U10.2 (VIN), U12.6 (VS); also elsewhere on the board
+5V_RS485: C33.1, C34.1, C38.1, C39.1, J15.1, J16.1, R67.1, R68.1, U8.8 (VDD2), U10.4 (VOUT), U11.8 (VCC)
+12V_LOCAL: C24.1, C27.1, D20.1 (K), F4.2, J2.1, U6.1 (VI); also elsewhere on the board
+24V_LOCAL: C30.1, D19.2 (A), R64.2, U5.2 (VO); also elsewhere on the board
+BATT_12V: R58.1; also elsewhere on the board
+BATT_24V: C26.1, D19.1 (K), J1.3, J1.4, MOD1.2 (IN+), U5.3 (VI); also elsewhere on the board
/BMS_microcontroller/RS485_A: D21.2 (A2), J15.3, J16.3, R69.2, R70.1, U11.6 (A)
/BMS_microcontroller/RS485_B: D22.2 (A2), J15.2, J16.2, R68.2, R69.1, U11.7 (B)
/BMS_microcontroller/VOLTAGE_BATT_12V_3W: J12.1, R58.2, R59.1
ADC_I_FAN1: U4.1 (PA7); also elsewhere on the board
ADC_I_FAN2: U4.3 (PC1); also elsewhere on the board
BALANCE_ON_12V: U4.27 (PA5); also elsewhere on the board
BALANCE_ON_24V: U4.26 (PA4); also elsewhere on the board
CLOCK: R76.2, U4.5 (PC3), U12.5 (SCL)
DBG_UART: J13.3, J14.3, R3.2, U4.2 (PC0)
GND: C20.2, C21.2, C22.2, C23.2, C24.2, C25.2, C26.2, C27.2, C28.2, C29.2, C30.2, C31.2, C32.2, C36.2, C37.2, D23.2 (A), D24.2 (A), D25.2 (A), J2.4, J13.4, J14.1, MOD1.1 (IN-), MOD1.3 (OUT-), Q1.2 (E), Q2.2 (E), Q21.2 (E), R60.2, R62.2, U4.15 (GND), U4.21 (GND), U6.2 (GND), U7.3 (A), U8.4 (GND1), U10.1 (GND), U12.1 (A1), U12.2 (A0), U12.7 (GND); also elsewhere on the board
GNDA: J1.1, J1.2; also elsewhere on the board
GND_RS485: C33.2, C34.2, C38.2, C39.2, D21.1 (A1), D22.1 (A1), J15.4, J16.4, R70.2, U8.5 (GND2), U9.3, U10.3 (0V), U11.5 (GND)
GND_VOLTAGE_DROP_ADC: U4.28 (P6); also elsewhere on the board
GND_VOLTAGE_DROP_INPUT: J12.3; also elsewhere on the board
LED1_PF6_RST: J13.2, R1.2, U4.18 (PF6(RST))
unnamed: D1.1 (K), R2.2
unnamed: D2.1 (K), R4.2
unnamed: C35.1, D23.1 (K), R71.2, U12.10 (Vin+)
unnamed: C35.2, D24.1 (K), R72.2, R74.1, U12.9 (Vin-)
unnamed: C36.1, D25.1 (K), R73.2, R74.2, U12.8 (Vbus)
unnamed: F4.1, MOD1.4 (OUT+)
unnamed: Q1.1 (B), R1.1
unnamed: Q1.3 (C), R2.1
unnamed: Q2.1 (B), R3.1
unnamed: Q2.3 (C), R4.1
unnamed: Q21.1 (B), R65.2
unnamed: Q21.3 (C), R66.1
unnamed: R66.2, U9.2
unnamed: R62.1, R64.1, U5.1 (ADJ)
unnamed: R67.2, U9.4, U11.2 (~RE), U11.3 (DE)
unnamed: U8.6 (VOB), U11.4 (DI)
unnamed: U8.7 (VIA), U11.1 (RO)
PWM_FAN_BALANCER: U4.24 (PA2); also elsewhere on the board
PWM_FAN_SMPS: U4.25 (PA3); also elsewhere on the board
PWM_OUT_CHRG: J2.3, U4.16 (PF0)
PWM_OUT_DISCH: J2.2, U4.17 (PF1)
RS232_RX: U4.23 (PA1), U8.2 (VOA)
RS232_TX: U4.22 (PA0), U8.3 (VIB)
RS485_OUTPUT_ENABLE: R65.1, U4.12 (PD6)
R_shunt_H: J3.2, R72.1
R_shunt_L: J3.1, R71.1
SDA: R75.2, U4.4 (PC2), U12.4 (SDA)
TEMP_AKU_12V: U4.8 (PD2); also elsewhere on the board
TEMP_AKU_24V: U4.9 (PD3); also elsewhere on the board
TEMP_BALANCER: U4.11 (PD5); also elsewhere on the board
TEMP_SMPS: U4.10 (PD4); also elsewhere on the board
UPDI: J14.2, R61.2, U4.19 (PF7(UPDI))
VOLTAGE_BATT_12V: C23.1, R59.2, R60.1, U4.7 (PD1)
VOLTAGE_BATT_24V_3W: J12.2, R73.1
VREF: C25.1, C28.1, R63.2, U4.13 (PD7), U7.1 (REF), U7.2 (K); also elsewhere on the board

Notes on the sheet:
+24V
6k8 1k 1,92V @ 15V
INA226
+12V
+5V
PIC16F886
MOUTINGS
VOLTAGE MEASURMENT
ST485
VOLTAGE REGULATION
/RE - Receiver Output Enable Active LOW
STATUS DIODES



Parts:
C5, C6, C10, C14, C17, C18: 100n; C_0805_2012Metric_Pad1.18x1.45mm_HandSolder
C7, C15: 10u; C_0805_2012Metric_Pad1.18x1.45mm_HandSolder
C8, C16: 470u/25V; CP_Radial_D8.0mm_P2.50mm
C9, C19: 1u; C_Disc_D5.0mm_W2.5mm_P2.50mm
C11: 1u; C_0805_2012Metric_Pad1.18x1.45mm_HandSolder
C12, C13: 47n; C_0805_2012Metric_Pad1.18x1.45mm_HandSolder
D7, D8, D9, D12, D13, D14, D15, D16: BAT86; D_MiniMELF
D10, D11, D17, D18: SM6T15A; D_SMB
F3: 6,3A; Fuseholder_Clip-5x20mm_Eaton_1A5601-01_Inline_P20.80x6.76mm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
J4: TMP_BALANCER; JST_EH_B2B-EH-A_1x02_P2.50mm_Vertical
J5: TMP_SMPS; JST_EH_B2B-EH-A_1x02_P2.50mm_Vertical
J6: THERMISTOR_BATT; JST_EH_B3B-EH-A_1x03_P2.50mm_Vertical
J7, J11: LOAD_RESISTOR; Conn_1x2_wire
J8: FAN_BALANCER; JST_EH_B2B-EH-A_1x02_P2.50mm_Vertical
J9: FAN_SMPS; JST_EH_B2B-EH-A_1x02_P2.50mm_Vertical
J10: BATT_12V; Flat-6,3mm-connector-2P
JP1: GND_Bridged; SolderJumper-2_P1.3mm_Bridged2Bar_Pad1.0x1.5mm
Q9, Q10, Q13, Q14, Q17, Q18: BC817; SOT-23
Q11, Q19: BC807; SOT-23
Q12, Q20: IRF540N; TO-220-3_Vertical-little-bigger pads
Q15, Q16: AO3400A; SOT-23
R5, R6, R31: 4k7; R_1206_3216Metric_Pad1.30x1.75mm_HandSolder
R21, R22, R24, R25: 150k; R_0805_2012Metric_Pad1.20x1.40mm_HandSolder
R23, R34, R35, R37, R38, R45: 10k; R_0805_2012Metric_Pad1.20x1.40mm_HandSolder
R26, R27, R28, R29, R30, R43, R44, R46: 1k; R_0805_2012Metric_Pad1.20x1.40mm_HandSolder
R32: 470R; R_0805_2012Metric_Pad1.20x1.40mm_HandSolder
R33, R51: 10R; R_0805_2012Metric_Pad1.20x1.40mm_HandSolder
R36, R55: 10R; R_Axial_DIN0204_L3.6mm_D1.6mm_P7.62mm_Horizontal
R39, R40, R57: 100R; R_0805_2012Metric_Pad1.20x1.40mm_HandSolder
R41, R42: 210mR; R_0805_2012Metric_Pad1.20x1.40mm_HandSolder
R47, R48, R52, R53, R54, R56: 10k/1%; R_0805_2012Metric_Pad1.20x1.40mm_HandSolder
R49: 2k2; R_1206_3216Metric_Pad1.30x1.75mm_HandSolder
R50: 220R; R_0805_2012Metric_Pad1.20x1.40mm_HandSolder
U1: 74AHCT125; SOIC-14_3.9x8.7mm_P1.27mm
U2: LM324; SOIC-14_3.9x8.7mm_P1.27mm
U3: LMV358; SOIC-8_3.9x4.9mm_P1.27mm

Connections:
+5V: C5.1, C10.1, C11.1, C18.1, D7.1 (A1), D14.1 (A1), R21.1, R22.1, R23.1, R24.1, R25.1, R45.1, U1.14 (VCC), U2.4 (V+), U3.8 (V+); also elsewhere on the board
+12V_LOCAL: C14.1, C15.1, D12.1 (A1), D13.1 (A1), J8.1, J9.1, Q18.3 (C), R6.1, R37.2, R38.2, R49.1; also elsewhere on the board
+24V_LOCAL: C6.1, C7.1, Q10.3 (C), R5.1, R31.1; also elsewhere on the board
+BATT_12V: C6.2, C7.2, C8.2, C9.2, C16.1, D9.2 (A2), D10.2 (A2), D11.2 (A2), F3.1, J11.1, Q11.3 (C), Q12.3 (S); also elsewhere on the board
+BATT_24V: C8.1, J7.1; also elsewhere on the board
ADC_I_FAN1: C13.2, R44.2; also elsewhere on the board
ADC_I_FAN2: C12.2, R43.2; also elsewhere on the board
BALANCE_ON_12V: R45.2, U1.5; also elsewhere on the board
BALANCE_ON_24V: R23.2, U1.2; also elsewhere on the board
GND: C5.2, C10.2, C11.2, C12.1, C13.1, C17.2, C18.2, J4.1, J5.1, J6.1, JP1.1 (A), Q13.2 (E), Q14.2 (E), R41.2, R42.2, R48.2, R54.2, U1.1, U1.4, U1.7 (GND), U2.11 (V-), U3.4 (V-); also elsewhere on the board
GNDA: C14.2, C15.2, C16.2, C19.2, D8.2 (A2), D15.2 (A2), D16.2 (A), D17.2 (A2), D18.2 (A2), JP1.2 (B), Q19.3 (C), Q20.3 (S), R32.2, R50.2; also elsewhere on the board
GND_VOLTAGE_DROP_ADC: R57.1; also elsewhere on the board
GND_VOLTAGE_DROP_INPUT: R52.2; also elsewhere on the board
unnamed: C9.1, R36.2
unnamed: C19.1, R55.2
unnamed: D7.2 (A2), D8.1 (A1), R26.2, U1.3
unnamed: D9.1 (A1), D10.1 (A1), Q12.1 (G), R33.1
unnamed: D11.1 (A1), J7.2, Q12.2 (D), R36.1
unnamed: D12.2 (A2), J8.2, Q15.3 (D)
unnamed: D13.2 (A2), J9.2, Q16.3 (D)
unnamed: D14.2 (A2), D15.1 (A1), R46.2, U1.6
unnamed: D16.1 (K), D17.1 (A1), Q20.1 (G), R51.1
unnamed: D18.1 (A1), J11.2, Q20.2 (D), R55.1
unnamed: J4.2, R25.2, U2.10 (+)
unnamed: J5.2, R22.2, U2.12 (+)
unnamed: J6.2, R21.2, U2.5 (+)
unnamed: J6.3, R24.2, U2.3 (+)
unnamed: F3.2, J10.1, J10.2
unnamed: Q9.1 (B), R26.1
unnamed: Q9.2 (E), R32.1
unnamed: Q9.3 (C), Q10.1 (B), Q11.1 (B), R5.2, R31.2
unnamed: Q10.2 (E), Q11.2 (E), R33.2
unnamed: Q13.1 (B), R34.2
unnamed: Q13.3 (C), R37.1, R39.1
unnamed: Q14.1 (B), R35.2
unnamed: Q14.3 (C), R38.1, R40.1
unnamed: Q15.1 (G), R39.2
unnamed: Q15.2 (S), R41.1, R43.1
unnamed: Q16.1 (G), R40.2
unnamed: Q16.2 (S), R42.1, R44.1
unnamed: Q17.1 (B), R46.1
unnamed: Q17.3 (C), Q18.1 (B), Q19.1 (B), R6.2, R49.2
unnamed: Q17.2 (E), R50.1
unnamed: Q18.2 (E), Q19.2 (E), R51.2
unnamed: R56.1, R57.2, U3.7
unnamed: R28.1, U2.1, U2.2 (-)
unnamed: R27.1, U2.6 (-), U2.7
unnamed: R30.1, U2.8, U2.9 (-)
unnamed: R29.1, U2.13 (-), U2.14
unnamed: C17.1, R47.2, R48.1, U3.3 (+)
unnamed: R53.2, U3.1, U3.2 (-)
unnamed: R52.1, R53.1, U3.5 (+)
unnamed: R54.1, R56.2, U3.6 (-)
PWM_FAN_BALANCER: R34.1; also elsewhere on the board
PWM_FAN_SMPS: R35.1; also elsewhere on the board
TEMP_AKU_12V: R28.2; also elsewhere on the board
TEMP_AKU_24V: R27.2; also elsewhere on the board
TEMP_BALANCER: R30.2; also elsewhere on the board
TEMP_SMPS: R29.2; also elsewhere on the board
VREF: R47.1; also elsewhere on the board

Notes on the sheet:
1,25V
BALANCER 12V
TEMP-12V
TEMP-24V
BALANCER 24V



Board: 2 copper layers, 99.5 x 99.5 mm, 172 parts (129 on the bottom side), 96 nets.

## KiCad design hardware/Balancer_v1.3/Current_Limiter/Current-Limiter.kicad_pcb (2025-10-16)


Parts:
C12, C15, C18, C22, C25, C27: 100n; C_0805_2012Metric_Pad1.18x1.45mm_HandSolder
C13, C14, C23, C24: 10n; C_0805_2012Metric_Pad1.18x1.45mm_HandSolder
C16, C26: 1n; C_0805_2012Metric_Pad1.18x1.45mm_HandSolder
C17, C21: 100u/35V; CP_Radial_D16.0mm_P7.50mm
C19, C20: 1u; C_Disc_D5.0mm_W2.5mm_P2.50mm
D7, D8, D9, D17, D18, D19: LL4148; D_MiniMELF
D10, D20: BZV55B15; D_MiniMELF
D11, D12, D15, D16: SM6T15A; D_SMB
D13, D14: YM3045; TO-220-3_V_Thick_Pads
F1: 6,3A; Fuse_Blade_ATO_directSolder
F2: 2A; Fuseholder_Clip-5x20mm_Eaton_1A5601-01_Inline_P20.80x6.76mm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
H1, H2, H3, H4, H5, H6: MountingHole; Mount-Hole-3mm
J11: R-Shunt; PinHeader_1x02_P2.54mm_Vertical
J12: BATT_IN; Flat-6,3mm-connector-4P
J13: BATT_OUT; Flat-6,3mm-connector-4P
J14: batt-24V-balancer; PinSocket_1x04_P2.54mm_Vertical
J15: pwm-12v-local; PinSocket_1x04_P2.54mm_Vertical
L1: L; Inductor_Toroidal
Q4, Q5: IRF540N; TO-220-3_V_Thick_Pads
R21, R22, R36, R37: 10k; R_0805_2012Metric
R23, R31, R35, R38: 10R; R_0805_2012Metric
R24, R39: 100k; R_0805_2012Metric
R26, R27, R28: 20A/75mV; R_Axial_DIN0309_L9.0mm_D3.2mm_P20.32mm_Horizontal
R29: 20A/75mV; Resistor-Power-5W-L22-W10
R32, R34: 10R; R_Axial_DIN0204_L3.6mm_D1.6mm_P7.62mm_Horizontal
R33, R41: 1k; R_0805_2012Metric
U6, U8: FAN7382; DIP-8_W10.16mm_LongPads
U7, U9: NE555D; SOIC-8_3.9x4.9mm_P1.27mm

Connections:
+5V: R21.1, R36.1
+12V_LOCAL: C12.2, C22.2, J15.1, R23.2, R38.2, U6.1 (VCC), U8.1 (VCC)
+BATT_24V: F2.1, J14.3, J14.4
GND: C12.1, C22.1, J15.4, R22.1, R33.1, R37.1, R41.1, U6.4 (GND), U8.4 (GND)
GNDA: C17.2, C21.2, D13.1 (K), D13.3 (K), D14.1 (K), D14.3 (K), J12.1, J12.2, J13.3, J13.4, J14.1, J14.2
unnamed: C19.1, R32.2
unnamed: C20.1, R34.2
unnamed: C13.2, D7.2 (A), D8.1 (K)
unnamed: C15.2, D7.1 (K), D9.1 (K), U6.8 (VB)
unnamed: D9.2 (A), R23.1
unnamed: C14.1, C16.1, C18.1, D10.2 (A), R33.2, U7.1 (GND)
unnamed: C15.1, C18.2, C19.2, D8.2 (A), D10.1 (K), D12.2 (A2), D13.2 (A), L1.1, Q4.3 (S), U6.6 (VS), U7.4 (R), U7.8 (VCC)
unnamed: D11.2 (A2), Q4.1 (G), R31.2
unnamed: C25.1, C27.2, D14.2 (A), D15.2 (A2), D18.2 (A), D20.1 (K), L1.2, Q5.3 (S), R34.1, U8.6 (VS), U9.4 (R), U9.8 (VCC)
unnamed: C20.2, C21.1, D15.1 (A1), D16.1 (A1), J13.1, J13.2, Q5.2 (D)
unnamed: D16.2 (A2), Q5.1 (G), R35.2
unnamed: C23.2, D17.2 (A), D18.1 (K)
unnamed: C25.2, D17.1 (K), D19.1 (K), U8.8 (VB)
unnamed: D19.2 (A), R38.1
unnamed: C24.1, C26.1, C27.1, D20.2 (A), R41.2, U9.1 (GND)
unnamed: F1.1, J12.3, J12.4
unnamed: R31.1, U6.7 (HO)
unnamed: R22.2, U6.3 (L_IN)
unnamed: C14.2, U7.5 (CV)
unnamed: C13.1, R24.2, U7.3 (Q)
unnamed: C16.2, R24.1, U7.2 (TR), U7.6 (THR)
unnamed: R35.1, U8.7 (HO)
unnamed: R37.2, U8.3 (L_IN)
unnamed: C24.2, U9.5 (CV)
unnamed: C23.1, R39.2, U9.3 (Q)
unnamed: C26.2, R39.1, U9.2 (TR), U9.6 (THR)
PWM_OUT_CHRG: J15.3, R36.2, U8.2 (H_IN)
PWM_OUT_DISCH: J15.2, R21.2, U6.2 (H_IN)
R_shunt_H: F1.2, F2.2, J11.2, R26.1, R27.1, R28.1, R29.1
R_shunt_L: C17.1, D11.1 (A1), D12.1 (A1), J11.1, Q4.2 (D), R26.2, R27.2, R28.2, R29.2, R32.1

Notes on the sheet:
MOUTINGS
NE555 CHARGE PUMPS
MOSFET DRIVER
CONNECTORS



Board: 2 copper layers, 99.0 x 99.0 mm, 68 parts (38 on the bottom side), 35 nets.

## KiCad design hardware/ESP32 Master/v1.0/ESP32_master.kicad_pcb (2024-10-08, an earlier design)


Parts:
C21: 100n; C_0805_2012Metric
D10, D11, D14, D15, D16, D17: 3V3; D_MiniMELF
D12, D13: 5V6; D_MiniMELF
J12: EXTERNAL_SIGNALS; CDDC-1,5-5-PV-3,5
J13: METER_GRID; JST_EH_B4B-EH-A_1x04_P2.50mm_Vertical
J14: METER_PV; JST_EH_B4B-EH-A_1x04_P2.50mm_Vertical
R51, R52, R63, R64: 4k7; R_0805_2012Metric_Pad1.20x1.40mm_HandSolder
R53, R54, R65, R66: 10k; R_0805_2012Metric_Pad1.20x1.40mm_HandSolder
R55, R56: 2,4k; R_0805_2012Metric_Pad1.20x1.40mm_HandSolder
R57, R59, R60, R62: 510R; R_0805_2012Metric_Pad1.20x1.40mm_HandSolder
R58, R61: 120R; R_0805_2012Metric_Pad1.20x1.40mm_HandSolder
U10, U11: ST485EBDR; SOIC-8_3.9x4.9mm_P1.27mm
U12: 74HC14; SOIC-14_3.9x8.7mm_P1.27mm

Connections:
+5V: C21.1, J12.5, J13.1, J14.1, R57.2, R60.2, U10.8 (VCC), U11.2 (~RE), U11.3 (DE), U11.8 (VCC), U12.14 (VCC); also elsewhere on the board
ALARM_SYREN_OUTPUT: J12.2; also elsewhere on the board
GAMA_METER_LED_ACTIVE_ENERGY: U12.2; also elsewhere on the board
GAMA_METER_LED_ACTIVE_ENERGY_INPUT: J12.4, R54.1
GAMA_METER_LED_REACTIVE: U12.4; also elsewhere on the board
GAMA_METER_LED_REACTIVE_INPUT: J12.3, R53.1
GND: C21.2, D10.2 (A), D11.2 (A), D12.2 (A), D13.2 (A), D14.2 (A), D15.2 (A), D16.2 (A), D17.2 (A), J12.6, J13.4, J14.4, R55.2, R56.2, R59.1, R62.1, U10.2 (~RE), U10.3 (DE), U10.5 (GND), U11.5 (GND), U12.7 (GND); also elsewhere on the board
METER_GRID_RX: D17.1 (K), R66.1; also elsewhere on the board
METER_GRID_TX: D16.1 (K), R64.1; also elsewhere on the board
METER_MAIN_RX: D10.1 (K), R51.1; also elsewhere on the board
METER_MAIN_RX_A: J12.8, R61.1, R62.2, U11.6 (A)
METER_MAIN_RX_B: J12.7, R60.1, R61.2, U11.7 (B)
METER_MAIN_TX: D11.1 (K), R52.1; also elsewhere on the board
METER_MAIN_TX_A: J12.10, R58.1, R59.2, U10.6 (A)
METER_MAIN_TX_B: J12.9, R57.1, R58.2, U10.7 (B)
METER_PV_RX: D15.1 (K), R65.1; also elsewhere on the board
METER_PV_TX: D14.1 (K), R63.1; also elsewhere on the board
unnamed: D12.1 (K), R53.2, R55.1, U12.3
unnamed: D13.1 (K), R54.2, R56.1, U12.1
unnamed: J13.2, U12.6
unnamed: J13.3, U12.9
unnamed: J14.2, U12.12
unnamed: J14.3, U12.11
unnamed: R63.2, U12.13
unnamed: R64.2, U12.5
unnamed: R65.2, U12.10
unnamed: R66.2, U12.8
unnamed: R52.2, U10.1 (RO)
unnamed: R51.2, U11.4 (DI)
P7_UNCONNECTED_OUTPUT: J12.1; also elsewhere on the board

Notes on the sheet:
Pozyton meter RS485 interface
ENERGY METER GAMA 300 LED BLINK INTERFACE
SCHMITT TRIGGER FOR METERS



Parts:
C1, C2, C4, C6: 100n; C_0805_2012Metric_Pad1.18x1.45mm_HandSolder
C3: 100u; CP_Radial_D4.0mm_P1.50mm
C5: 22u/25V; CP_EIA-3528-21_Kemet-B
C7: 10u/16V; CP_EIA-3528-21_Kemet-B
C8: 22u; CP_Radial_D4.0mm_P1.50mm
C9: 22u; CP_Radial_D5.0mm_P2.00mm
C10, C15: 100n; R_0805_2012Metric_Pad1.20x1.40mm_HandSolder
C11, C16, C17, C18: 10u; CP_Radial_D5.0mm_P2.00mm
C12: 100n; C_0805_2012Metric
C13: 1n; R_0805_2012Metric_Pad1.20x1.40mm_HandSolder
C14: 47u; CP_Radial_D5.0mm_P2.00mm
C19, C20: 10n; C_0805_2012Metric
D1: 1N4148; D_MiniMELF
D2, D3, D4, D8, D9: 3V3; D_MiniMELF
D5, D6: LESD5D5.0CT1G-MS; D_SOD-523
D7: LL4148; D_MiniMELF
F1: 2A; Fuseholder_Clip-5x20mm_Eaton_1A5601-01_Inline_P20.80x6.76mm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
F2: 2A; Fuse_2512_6332Metric_Pad1.52x3.35mm_HandSolder
F3: Fuse; Fuseholder_Clip-5x20mm_Eaton_1A5601-01_Inline_P20.80x6.76mm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
J1: OR-OR SMOKE SENSOR; JST_XH_B3B-XH-A_1x03_P2.50mm_Vertical
J2: LCD_DISP; JST_EH_B5B-EH-A_1x05_P2.50mm_Vertical
J3: 7SEG_DISP; JST_EH_B5B-EH-A_1x05_P2.50mm_Vertical
J4: RS485; JST_XH_B4B-XH-A_1x04_P2.50mm_Vertical
J5: DHT22; PinHeader_1x03_P2.54mm_Vertical
J6: DC_LINE_OUTPUT; Screw-Terminal-P6-rast-5mm-6,7x30
J7: MAIN_BATT_+24V; Screw-Terminal-P2-rast-5mm-6,7x30
J8: MAIN_BATT_SHUNT; JST_XH_B3B-XH-A_1x03_P2.50mm_Vertical
J9: DB9_Socket; DSUB-9_Female_Horizontal_P2.77x2.84mm_EdgePinOffset7.70mm_H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
J10: CO_SENSOR; PinHeader_1x03_P2.54mm_Vertical
J11: H2_SENSOR; PinHeader_1x03_P2.54mm_Vertical
JE1: EXTERNAL_POWER_SUPPLY_STATUS; JST_EH_B2B-EH-A_1x02_P2.50mm_Vertical
JP1: Jumper_2_Bridged; SolderJumper-2_P1.3mm_Bridged2Bar_Pad1.0x1.5mm
K1: G5G-1A-DT1
LED1, LED2: LED; LED_PLCC-2_3.4x3.0mm_KA
LS1: BUZZER; Buzzer
MOD1, MOD2: LM2596-Step-Down; LM2596-Step-Down-Conv
Q1, Q2, Q3, Q5, Q8, Q9, Q10, Q11, Q12: BC817; SOT-23
Q4: BC556; TO-92_Inline
Q6, Q7: BSS138; SOT-23
R1, R2, R3, R4, R6, R11, R16, R18, R21, R30, R33, R36: 10k; R_0805_2012Metric_Pad1.20x1.40mm_HandSolder
R5: 2k; C_0805_2012Metric
R7, R8, R9, R24, R25: 4k7; R_0805_2012Metric_Pad1.20x1.40mm_HandSolder
R10, R15: 47k; R_0805_2012Metric_Pad1.20x1.40mm_HandSolder
R12, R14: 510R; R_0805_2012Metric_Pad1.20x1.40mm_HandSolder
R13: 120R; R_0805_2012Metric_Pad1.20x1.40mm_HandSolder
R17, R19, R20, R22, R23: 2,5mR; R_2512_6332Metric
R26, R27, R29, R32: 100R; R_0805_2012Metric_Pad1.20x1.40mm_HandSolder
R28, R31: 1k; R_0805_2012Metric_Pad1.20x1.40mm_HandSolder
R34, R37: 0R; R_0805_2012Metric_Pad1.20x1.40mm_HandSolder
R35: 1k8; R_0805_2012Metric_Pad1.20x1.40mm_HandSolder
R38, R41, R42, R44, R48, R49: 10K; R_0805_2012Metric_Pad1.20x1.40mm_HandSolder
R39, R46: 7k8; R_0805_2012Metric_Pad1.20x1.40mm_HandSolder
R40, R47: 2k2; R_0805_2012Metric_Pad1.20x1.40mm_HandSolder
R43, R45, R50: 220R; R_0805_2012Metric_Pad1.20x1.40mm_HandSolder
SW1: SW_Push; JST_XA_B02B-XASK-1_1x02_P2.50mm_Vertical
U1: PCF8574; DIP-16_W7.62mm_LongPads
U2: ST485; SOIC-8_3.9x4.9mm_P1.27mm
U3: AMS1117-5.0; SOT-223-3_TabPin2
U4: L7812; TO-220-3_V_Thick_Pads
U5: ESP32_DevKit_V1_DOIT; esp32_devkit_v1_doit
U6, U8: INA226; VSSOP-10_3x3mm_P0.5mm
U7: MAX3232; SO-16_3.9x9.9mm_P1.27mm
U9: UP7760; SOIC-8-1EP_3.9x4.9mm_P1.27mm_EP2.41x3.81mm

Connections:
7_SEG_DISP_CLOCK: J3.3, U5.12 (IO12)
7_SEG_DISP_DATA: J3.4, U5.13 (IO13)
7_SEG_DISP_LATCH: J3.2, U5.11 (IO14)
24V_MEASURED: MOD1.2 (IN+), MOD2.2 (IN+), R17.2, R19.2, R20.2, R22.2, R23.2, U6.9 (Vin-)
+3V3: C1.1, C6.1, C8.1, C9.1, C10.1, C15.1, J5.1, R4.2, R6.2, R18.1, R21.2, R33.1, R36.1, R37.1, U1.1 (A0), U1.2 (A1), U1.3 (A2), U1.16 (VDD), U3.2 (VO), U5.15 (VIN), U5.16 (3V3), U6.1 (A1), U6.6 (VS), U8.6 (VS)
+5V: C2.1, C3.1, C4.1, F2.2, J2.1, J3.1, J4.1, J11.1, JE1.1, LED1.1 (K), LED2.1 (K), LS1.- (2), R5.1, R12.1, R30.2, R34.1, U2.8 (VCC), U3.3 (VI), U9.3 (VIN), U9.4 (CNTL); also elsewhere on the board
+20V: F1.1, J1.3, J6.1, J6.3, J6.5, Q4.3 (E), R10.2
+BATT_24V: F3.1, R17.1, R19.1, R20.1, R22.1, R23.1, U6.8 (Vbus), U6.10 (Vin+)
/ESP32_Measurment_Board/INV_RX_RS232: J9.2, U7.7 (T2OUT)
/ESP32_Measurment_Board/INV_TX_RS232: J9.3, U7.8 (R2IN)
/ESP32_Measurment_Board/RS485_A: D5.2 (A2), J4.2, R13.2, R14.1, U2.6 (A)
/ESP32_Measurment_Board/RS485_B: D6.2 (A2), J4.3, R12.2, R13.1, U2.7 (B)
ALARM_RESET_BUTTON: R6.1, SW1.1, U1.4 (P0)
ALARM_SYREN: R41.2, R44.2, U1.11 (P6)
ALARM_SYREN_OUTPUT: Q8.3 (C); also elsewhere on the board
BUZZER: R3.1, U1.10 (P5)
CLOCK_ESP: R36.2, U1.14 (SCL), U5.29 (IO22), U6.5 (SCL), U8.5 (SCL)
CO_SENSOR_EN: R29.2, U1.7 (P3)
CO_SENSOR_SWITCH_VOLTAGES: R32.2, U1.6 (P2)
DHT22: J5.2, R21.1, U5.25 (IO19)
EXTERNAL_PS_ON: R16.2, R49.2, U1.5 (P1)
GAMA_METER_LED_ACTIVE_ENERGY: U5.2 (SENSOR_VP); also elsewhere on the board
GAMA_METER_LED_REACTIVE: U5.3 (SENSOR_VN); also elsewhere on the board
GND: C1.2, C2.2, C3.2, C4.2, C5.2, C6.2, C7.2, C8.2, C9.2, C10.2, C12.1, C14.2, C15.2, C17.1, C19.1, C20.1, D2.2 (A), D3.2 (A), D4.2 (A), D5.1 (A1), D6.1 (A1), D7.2 (A), D8.2 (A), D9.2 (A), J2.5, J3.5, J4.4, J5.3, J8.1, J9.5, J10.3, J11.3, JP1.2 (B), K1.A2, MOD2.1 (IN-), MOD2.3 (OUT-), Q1.2 (E), Q2.2 (E), Q3.2 (E), Q5.2 (E), Q6.2 (S), Q7.2 (S), Q8.2 (E), Q9.2 (E), Q10.2 (E), Q11.2 (E), Q12.2 (E), R14.2, R15.1, R28.2, R31.1, R40.1, R47.1, SW1.2, U1.8 (VSS), U2.5 (GND), U3.1 (GND), U4.2 (GND), U5.14 (GND), U5.17 (GND), U6.2 (A0), U6.7 (GND), U7.15 (GND), U8.1 (A1), U8.2 (A0), U8.7 (GND), U9.8 (GND), U9.9 (EP); also elsewhere on the board
GNDA: J6.2, J6.4, J6.6, J7.1, JP1.1 (A), MOD1.1 (IN-), MOD1.3 (OUT-)
INVERTER_RX: D8.1 (K), R24.1, U5.23 (IO5)
INVERTER_TX: D9.1 (K), R25.1, U5.20 (IO4)
LCD_DISP_CLOCK: J2.3, U5.9 (IO26)
LCD_DISP_DATA: J2.4, U5.8 (IO25)
LCD_DISP_LATCH: J2.2, U5.10 (IO27)
METER_GRID_RX: U5.6 (IO32); also elsewhere on the board
METER_GRID_TX: U5.7 (IO33); also elsewhere on the board
METER_MAIN_RX: U5.19 (IO2); also elsewhere on the board
METER_MAIN_TX: U5.18 (IO15); also elsewhere on the board
METER_PV_RX: U5.4 (IO34); also elsewhere on the board
METER_PV_TX: U5.5 (IO35); also elsewhere on the board
MQ7_CO_SENSOR: C19.2, R39.1, R40.2, U5.28 (TXD0/IO1)
MQ8_H2_SENSOR: C20.2, R46.1, R47.2, U5.27 (RXD0/IO3)
unnamed: D1.2 (A), LS1.+ (1), R5.2
unnamed: D1.1 (K), Q3.3 (C)
unnamed: C7.1, D7.1 (K), K1.A1, U4.3 (OUT)
unnamed: J1.1, Q1.3 (C)
unnamed: J1.2, R2.1
unnamed: F3.2, J7.2
unnamed: J8.2, R27.1
unnamed: J8.3, R26.1
unnamed: J10.1, R38.1, U9.6 (VOUT)
unnamed: J10.2, R39.2
unnamed: J11.2, R46.2
unnamed: JE1.2, R50.2
unnamed: LED1.2 (A), R43.2
unnamed: LED2.2 (A), R45.2
unnamed: F1.2, MOD1.4 (OUT+)
unnamed: F2.1, MOD2.4 (OUT+)
unnamed: Q1.1 (B), R1.2
unnamed: Q2.1 (B), R2.2
unnamed: Q3.1 (B), R3.2
unnamed: Q4.2 (B), R10.1, R11.2
unnamed: C5.1, Q4.1 (C), U4.1 (IN)
unnamed: Q5.1 (B), R15.2, R16.1
unnamed: Q5.3 (C), R11.1
unnamed: Q6.3 (D), R30.1, U9.2 (EN)
unnamed: Q6.1 (G), R29.1
unnamed: Q7.3 (D), R35.1
unnamed: Q7.1 (G), R32.1
unnamed: Q8.1 (B), R41.1
unnamed: Q9.1 (B), R42.1
unnamed: Q9.3 (C), R43.1
unnamed: Q10.1 (B), R44.1
unnamed: Q10.3 (C), R45.1
unnamed: Q11.1 (B), R48.1
unnamed: Q12.1 (B), R49.1
unnamed: Q12.3 (C), R50.1
unnamed: R8.2, U2.2 (~RE), U2.3 (DE)
unnamed: R9.2, U2.4 (DI)
unnamed: R7.2, U2.1 (RO)
unnamed: R18.2, U5.1 (EN)
unnamed: C11.1, U7.1 (C1+)
unnamed: C11.2, U7.3 (C1-)
unnamed: C18.1, U7.4 (C2+)
unnamed: C18.2, U7.5 (C2-)
unnamed: R31.2, U7.13 (R1IN)
unnamed: R25.2, U7.9 (R2OUT)
unnamed: R28.1, U7.11 (T1IN)
unnamed: R24.2, U7.10 (T2IN)
unnamed: C12.2, C14.1, C16.2, R34.2, R37.2, U7.16 (VCC)
unnamed: C16.1, U7.2 (VS+)
unnamed: C17.2, U7.6 (VS-)
unnamed: C13.2, R27.2, U8.8 (Vbus), U8.9 (Vin-)
unnamed: C13.1, R26.2, U8.10 (Vin+)
unnamed: R35.2, R38.2, U9.7 (FB)
P7_UNCONNECTED: R42.2, R48.2, U1.12 (P7)
P7_UNCONNECTED_OUTPUT: Q11.3 (C); also elsewhere on the board
RS485_OUTPUT_ENABLE_ESP: D3.1 (K), R8.1, U5.24 (IO18)
RS485_RX_ESP: D2.1 (K), R7.1, U5.21 (IO16)
RS485_TX_ESP: D4.1 (K), R9.1, U5.22 (IO17)
SDA_ESP: R33.2, U1.15 (SDA), U5.26 (IO21), U6.4 (SDA), U8.4 (SDA)
SMOKE_DETECTOR_OUTPUT: Q2.3 (C), R4.1, U5.30 (IO23)
SMOKE_DETECTOR_RESET: R1.1, U1.9 (P4)

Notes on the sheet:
STATUS DIODES
ADDR: 01000 000
EXTERNAL POWER SUPPLY RELAY
ADDR: 0010 0111
DHT22 CONNECTOR
OR-OR SMOKE SENSOR
ESP-WROOM-32
I/O expander
INA226 RECEIVERS DC LINE
/RE - Receiver Output Enable Active LOW
MAX232 TTL<->RS232 LEVEL TRANSLATOR
DISPLAY CONNECTORS
INA226 BATTERY DC LINE
ALARM RESET BUTTON
ST485
ADDR: 0100 0100
CO AND H2 SENSORS
ALARM BUZZER
20V SCREW TERMINAL CONNECTORS
VOLTAGE REGULATION VBAT(24V) -> 20V/5V/3.3V

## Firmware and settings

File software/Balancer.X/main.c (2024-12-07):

/* 
 * FILE: main.c
 * DESCRIPTION: Main program body
 * AUTHOR: kwiecinski
 * DATE: 03.2020
 */

#include <xc.h>
#include <stdio.h>
#include <stdint.h>
#include "main.h"
#include "inits.h"
#include "interrupts.h"
#include "hw_i2c.h"
#include "hw_uart.h"
#include "sw_uart.h"
#include "ina226.h"
#include "adc.h"

#define BALANCE_THRESHOLD 5

void main(void)
{

    AutoFox_INA226 ina226;
    AutoFox_INA226_Constructor(&ina226);

    Global_Init();
    Interrupt_Init();
    I2C_Init();
    STATUS_LED_D20_OFF;
    STATUS_LED_D21_OFF;
    STATUS_LED_D23_ON;
    STATUS_LED_D5_ON;

    //UART_Init();
    SendErrorStatus(AutoFox_INA226_Init(&ina226, INA226_DEFAULT_I2C_ADDRESS, 2, 50));
    SendErrorStatus(AutoFox_INA226_ConfigureVoltageConversionTime(&ina226, 0b111)); //sample time 8.244ms
    SendErrorStatus(AutoFox_INA226_ConfigureNumSampleAveraging(&ina226, 0b010));

    uint16_t voltage_bus_24V, voltage_batt_12V_high, voltage_batt_12V_low;
    
    ADC_Init();

    while (1)
{           
            voltage_bus_24V = AutoFox_INA226_GetBusVoltage_V(&ina226);
            voltage_batt_12V_low = read_voltage();
            voltage_batt_12V_high = voltage_bus_24V - voltage_batt_12V_low;
        
            printf("24V:%u \r\n", voltage_batt_12V_high);
            printf("12V:%u \r\n", voltage_batt_12V_low);
            printf("BUS:%u \r\n\r\n", voltage_bus_24V);

        if (voltage_batt_12V_low > (voltage_batt_12V_high + BALANCE_THRESHOLD))
        {
            while (1)
            {
                BALANCE_BATT_12V_ON;
                
                __delay_ms(1000);
                 BALANCE_BATT_12V_OFF;
                 __delay_ms(5000);
                 
                voltage_bus_24V = AutoFox_INA226_GetBusVoltage_V(&ina226);
                voltage_batt_12V_low = read_voltage();
                voltage_batt_12V_high = voltage_bus_24V - voltage_batt_12V_low;

                 printf("24V:%u \r\n", voltage_batt_12V_high);
                 printf("12V:%u \r\n", voltage_batt_12V_low);
                 printf("BUS:%u \r\n\r\n", voltage_bus_24V);


                if (voltage_batt_12V_low < (voltage_batt_12V_high + BALANCE_THRESHOLD))
                {
                     BALANCE_BATT_12V_OFF;
                    break;
                }
            }    
        }
            
        if (voltage_batt_12V_high > (voltage_batt_12V_low + BALANCE_THRESHOLD))
        {
            while (1)
            {
                BALANCE_BATT_24V_ON;
                
                __delay_ms(1000);
                 BALANCE_BATT_24V_OFF;
                 __delay_ms(5000);
                 
                voltage_bus_24V = AutoFox_INA226_GetBusVoltage_V(&ina226);
                voltage_batt_12V_low = read_voltage();
                voltage_batt_12V_high = voltage_bus_24V - voltage_batt_12V_low;

                 printf("24V:%u \r\n", voltage_batt_12V_high);
                 printf("12V:%u \r\n", voltage_batt_12V_low);
                 printf("BUS:%u \r\n\r\n", voltage_bus_24V);


                if (voltage_batt_12V_high < (voltage_batt_12V_low + BALANCE_THRESHOLD))
                {
                     BALANCE_BATT_24V_OFF;
                    break;
                }
            }
            
            
        }
        //__delay_ms(1000);
    }
}

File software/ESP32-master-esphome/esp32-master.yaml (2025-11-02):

esphome:
  name: photovoltaic-master

esp32:
  board: esp32doit-devkit-v1
  framework:
    type: arduino

# Enable logging
logger:
  level: INFO

# Enable Home Assistant API
api:
  password: ""

ota:
  - platform: esphome
    password: "zerowanie"

wifi:
  ssid: "komandor_shepard"
  password: "uziemienie poprzez zerowanie"

  # Enable fallback hotspot (captive portal) in case wifi connection fails
  ap:
    ssid: "Photovoltaic-Master"
    password: "DjaE8peyASsA"

captive_portal:

time:
  - platform: sntp
    id: sntp_time

sun:
  latitude: 50.0413
  longitude: 21.9990
  id: sun_sun

globals:
  - id: priority_mode
    type: int
    restore_value: no
    initial_value: '0'

  - id: MODE_UTI
    type: int
    restore_value: no
    initial_value: '0'

  - id: MODE_SOL
    type: int
    restore_value: no
    initial_value: '1'

  - id: last_sol_candidate_ms
    type: unsigned long
    restore_value: no
    initial_value: '0'
    
  - id: power_sw_sol_flag
    type: int
    restore_value: no
    initial_value: '1'

  - id: power_sw_uti_flag
    type: int
    restore_value: no
    initial_value: '0'

  - id: last_mode_change
    type: unsigned long
    restore_value: no
    initial_value: '0'


  #- id: output_priority
  #  type: int
   # restore_value: no
  #  initial_value: '0'

uart:
  - id: easun_uart
    baud_rate: 9600
    tx_pin: GPIO32
    rx_pin: GPIO33


modbus:
  - id: modbus0
    uart_id: easun_uart
    send_wait_time: 200ms

modbus_controller:
  - id: smg0
    address: 0x01
    modbus_id: modbus0
    command_throttle: 200ms
    update_interval: 10s

binary_sensor:
  - platform: template
    name: "Allow Solar Mode"
    id: allow_solar_mode
    lambda: |-
      static bool allow = false;
      if (id(sun_elevation).state > 15.0)
        allow = true;
      else if (id(sun_elevation).state < 8.0)
        allow = false;
      return allow;


sensor:
  - platform: sun
    name: "Sun Elevation"
    type: elevation
    id: sun_elevation

  - platform: template
    name: "Sun Elevation Angle"
    id: sun_elevation_angle
    unit_of_measurement: "°"
    update_interval: 60s
    accuracy_decimals: 1
    lambda: |-
      return id(sun_elevation).state;


    # Fault code                                                    ULong 100 2 R
  - platform: modbus_controller
    modbus_controller_id: smg0
    name: "fault code"
    address: 100
    register_type: holding
    value_type: U_DWORD
    accuracy_decimals: 0

  # Warning code                                                  ULong 108 2 R
  - platform: modbus_controller
    modbus_controller_id: smg0
    name: "warning code"
    address: 108
    register_type: holding
    value_type: U_DWORD
    accuracy_decimals: 0

  # Operation Mode                                                UInt  201 1 R 0: Power On
  #                                                                             1: Standby
  #                                                                             2: Mains
  #                                                                             3: Off-Grid
  #                                                                             4: Bypass
  #                                                                             5: Charging
  #                                                                             6: Fault
  #- platform: modbus_controller
  #  modbus_controller_id: smg0
  #  name: "operation mode id"
  #  address: 201
  # register_type: holding
  #  value_type: U_WORD
  #  accuracy_decimals: 0

  # Effective mains voltage                              0.1V     Int   202 1 R
  - platform: modbus_controller
    modbus_controller_id: smg0
    name: "ac voltage"
    address: 202
    register_type: holding
    value_type: S_WORD
    unit_of_measurement: "V"
    device_class: voltage
    state_class: measurement
    accuracy_decimals: 1
    filters:
      - multiply: 0.1

  # Mains Frequency                                      0.01Hz   Int   203 1 R
  - platform: modbus_controller
    modbus_controller_id: smg0
    name: "ac frequency"
    address: 203
    register_type: holding
    value_type: S_WORD
    unit_of_measurement: "Hz"
    device_class: frequency
    state_class: measurement
    accuracy_decimals: 2
    filters:
      - multiply: 0.01

  # Average mains power                                  1W       Int   204 1 R
  - platform: modbus_controller
    modbus_controller_id: smg0
    name: "average mains power"
    address: 204
    register_type: holding
    value_type: S_WORD
    unit_of_measurement: "W"
    device_class: power
    state_class: measurement
    accuracy_decimals: 0
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

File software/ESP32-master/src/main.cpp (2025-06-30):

#include <Arduino.h>
#include "ModbusClientRTU.h"
#include "easun.h"

// Global Modbus client instance
ModbusClientRTU MB;

unsigned long lastReadTime = 0;
const unsigned long interval = 5000;

void setup() {
    Serial.begin(9600);
    while (!Serial) {}  // Wait for USB serial

    Serial.println("__ START __");

    // Initialize Easun Modbus client
    initEasun(MB, Serial2);
}

void loop() {
    if (millis() - lastReadTime >= interval) {
        lastReadTime = millis();
        requestEasunData(MB);
    }
}

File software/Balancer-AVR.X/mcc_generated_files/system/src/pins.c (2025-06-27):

/**
 * Generated Driver File
 * 
 * @file pins.c
 * 
 * @ingroup  pinsdriver
 * 
 * @brief This is generated driver implementation for pins. 
 *        This file provides implementations for pin APIs for all pins selected in the GUI.
 *
 * @version Driver Version 1.0.1
*/

/*
© [2025] Microchip Technology Inc. and its subsidiaries.

    Subject to your compliance with these terms, you may use Microchip 
    software and any derivatives exclusively with Microchip products. 
    You are responsible for complying with 3rd party license terms  
    applicable to your use of 3rd party software (including open source  
    software) that may accompany Microchip software. SOFTWARE IS ?AS IS.? 
    NO WARRANTIES, WHETHER EXPRESS, IMPLIED OR STATUTORY, APPLY TO THIS 
    SOFTWARE, INCLUDING ANY IMPLIED WARRANTIES OF NON-INFRINGEMENT,  
    MERCHANTABILITY, OR FITNESS FOR A PARTICULAR PURPOSE. IN NO EVENT 
    WILL MICROCHIP BE LIABLE FOR ANY INDIRECT, SPECIAL, PUNITIVE, 
    INCIDENTAL OR CONSEQUENTIAL LOSS, DAMAGE, COST OR EXPENSE OF ANY 
    KIND WHATSOEVER RELATED TO THE SOFTWARE, HOWEVER CAUSED, EVEN IF 
    MICROCHIP HAS BEEN ADVISED OF THE POSSIBILITY OR THE DAMAGES ARE 
    FORESEEABLE. TO THE FULLEST EXTENT ALLOWED BY LAW, MICROCHIP?S 
    TOTAL LIABILITY ON ALL CLAIMS RELATED TO THE SOFTWARE WILL NOT 
    EXCEED AMOUNT OF FEES, IF ANY, YOU PAID DIRECTLY TO MICROCHIP FOR 
    THIS SOFTWARE.
*/

#include "../pins.h"

static void (*PC3_InterruptHandler)(void);
static void (*PC2_InterruptHandler)(void);
static void (*PF0_InterruptHandler)(void);
static void (*PF1_InterruptHandler)(void);
static void (*PA4_InterruptHandler)(void);
static void (*PA5_InterruptHandler)(void);
static void (*PD4_InterruptHandler)(void);
static void (*PD5_InterruptHandler)(void);
static void (*PA6_InterruptHandler)(void);
static void (*PA7_InterruptHandler)(void);
static void (*PC1_InterruptHandler)(void);
static void (*PD1_InterruptHandler)(void);
static void (*PD2_InterruptHandler)(void);
static void (*PD3_InterruptHandler)(void);
static void (*PA3_InterruptHandler)(void);
static void (*PA2_InterruptHandler)(void);
static void (*PC0_InterruptHandler)(void);
static void (*PA1_InterruptHandler)(void);
static void (*PA0_InterruptHandler)(void);
static void (*PD6_InterruptHandler)(void);
static void (*PF6_InterruptHandler)(void);

void PIN_MANAGER_Initialize()
{
  /* DIR Registers Initialization */
    PORTA.DIR = 0x3D;
    PORTC.DIR = 0xD;
    PORTD.DIR = 0x70;
    PORTF.DIR = 0x43;

  /* OUT Registers Initialization */
    PORTA.OUT = 0x31;
    PORTC.OUT = 0x1;
    PORTD.OUT = 0x0;
    PORTF.OUT = 0x0;

  /* PINxCTRL registers Initialization */
    PORTA.PIN0CTRL = 0x0;
    PORTA.PIN1CTRL = 0x0;
    PORTA.PIN2CTRL = 0x0;
    PORTA.PIN3CTRL = 0x0;
    PORTA.PIN4CTRL = 0x0;
    PORTA.PIN5CTRL = 0x0;
    PORTA.PIN6CTRL = 0x0;
    PORTA.PIN7CTRL = 0x0;
    PORTC.PIN0CTRL = 0x0;
    PORTC.PIN1CTRL = 0x0;
    PORTC.PIN2CTRL = 0x0;
    PORTC.PIN3CTRL = 0x0;
    PORTC.PIN4CTRL = 0x0;
    PORTC.PIN5CTRL = 0x0;
    PORTC.PIN6CTRL = 0x0;
    PORTC.PIN7CTRL = 0x0;
    PORTD.PIN0CTRL = 0x0;
    PORTD.PIN1CTRL = 0x0;
    PORTD.PIN2CTRL = 0x0;
    PORTD.PIN3CTRL = 0x0;
    PORTD.PIN4CTRL = 0x0;
    PORTD.PIN5CTRL = 0x0;
    PORTD.PIN6CTRL = 0x0;
    PORTD.PIN7CTRL = 0x0;
    PORTF.PIN0CTRL = 0x0;
    PORTF.PIN1CTRL = 0x0;
    PORTF.PIN2CTRL = 0x0;
    PORTF.PIN3CTRL = 0x0;
    PORTF.PIN4CTRL = 0x0;
    PORTF.PIN5CTRL = 0x0;
    PORTF.PIN6CTRL = 0x0;
    PORTF.PIN7CTRL = 0x0;

  /* PORTMUX Initialization */
    PORTMUX.CCLROUTEA = 0x0;
    PORTMUX.EVSYSROUTEA = 0x0;
    PORTMUX.SPIROUTEA = 0x0;
    PORTMUX.TCAROUTEA = 0x5;
    PORTMUX.TCBROUTEA = 0x0;
    PORTMUX.TCDROUTEA = 0x4;
    PORTMUX.TWIROUTEA = 0x2;
    PORTMUX.USARTROUTEA = 0x0;

  // register default ISC callback functions at runtime; use these methods to register a custom function
    PC3_SetInterruptHandler(PC3_DefaultInterruptHandler);
    PC2_SetInterruptHandler(PC2_DefaultInterruptHandler);
    PF0_SetInterruptHandler(PF0_DefaultInterruptHandler);
    PF1_SetInterruptHandler(PF1_DefaultInterruptHandler);
    PA4_SetInterruptHandler(PA4_DefaultInterruptHandler);
    PA5_SetInterruptHandler(PA5_DefaultInterruptHandler);
    PD4_SetInterruptHandler(PD4_DefaultInterruptHandler);
    PD5_SetInterruptHandler(PD5_DefaultInterruptHandler);
    PA6_SetInterruptHandler(PA6_DefaultInterruptHandler);
    PA7_SetInterruptHandler(PA7_DefaultInterruptHandler);
    PC1_SetInterruptHandler(PC1_DefaultInterruptHandler);
    PD1_SetInterruptHandler(PD1_DefaultInterruptHandler);
    PD2_SetInterruptHandler(PD2_DefaultInterruptHandler);
    PD3_SetInterruptHandler(PD3_DefaultInterruptHandler);
    PA3_SetInterruptHandler(PA3_DefaultInterruptHandler);
    PA2_SetInterruptHandler(PA2_DefaultInterruptHandler);
    PC0_SetInterruptHandler(PC0_DefaultInterruptHandler);
    PA1_SetInterruptHandler(PA1_DefaultInterruptHandler);
    PA0_SetInterruptHandler(PA0_DefaultInterruptHandler);
    PD6_SetInterruptHandler(PD6_DefaultInterruptHandler);
    PF6_SetInterruptHandler(PF6_DefaultInterruptHandler);
}

/**
  Allows selecting an interrupt handler for PC3 at application runtime
*/
void PC3_SetInterruptHandler(void (* interruptHandler)(void)) 
{
    PC3_InterruptHandler = interruptHandler;
}

void PC3_DefaultInterruptHandler(void)
{
    // add your PC3 interrupt custom code
    // or set custom function using PC3_SetInterruptHandler()
}
/**
  Allows selecting an interrupt handler for PC2 at application runtime
*/
void PC2_SetInterruptHandler(void (* interruptHandler)(void)) 
{
    PC2_InterruptHandler = interruptHandler;
}

void PC2_DefaultInterruptHandler(void)
{
    // add your PC2 interrupt custom code
    // or set custom function using PC2_SetInterruptHandler()
}
/**
  Allows selecting an interrupt handler for PF0 at application runtime
*/
void PF0_SetInterruptHandler(void (* interruptHandler)(void)) 
{
    PF0_InterruptHandler = interruptHandler;
}

void PF0_DefaultInterruptHandler(void)
{
    // add your PF0 interrupt custom code
    // or set custom function using PF0_SetInterruptHandler()
}
/**
  Allows selecting an interrupt handler for PF1 at application runtime
*/
void PF1_SetInterruptHandler(void (* interruptHandler)(void)) 
{
    PF1_InterruptHandler = interruptHandler;
}

void PF1_DefaultInterruptHandler(void)
{
    // add your PF1 interrupt custom code
    // or set custom function using PF1_SetInterruptHandler()
}
/**
  Allows selecting an interrupt handler for PA4 at application runtime
*/
void PA4_SetInterruptHandler(void (* interruptHandler)(void)) 
{
    PA4_InterruptHandler = interruptHandler;
}

void PA4_DefaultInterruptHandler(void)
{
    // add your PA4 interrupt custom code
    // or set custom function using PA4_SetInterruptHandler()
}
/**
  Allows selecting an interrupt handler for PA5 at application runtime
*/
void PA5_SetInterruptHandler(void (* interruptHandler)(void)) 
{
    PA5_InterruptHandler = interruptHandler;
}
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

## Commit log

2024-08-19 Initial commit with project files: PCB design in KiCad and documentation
    [Balancer+ESP.kicad_pcb, Balancer+ESP.kicad_sch, Bidirectional_Power_Converter_24V-12V_with_BMS.kicad_pcb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]
2024-08-19 Routing display and probe
    [DC_line_module+Meter_probe.kicad_pcb, DC_line_module+Meter_probe.kicad_sch]
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2024-08-21 Add first concept of tl494 power supply
    [Bidirectional_Power_Converter_24V-12V_with_BMS.kicad_pcb, Bidirectional_Power_Converter_24V-12V_with_BMS.kicad_sch, DC_line_module+Meter_probe.kicad_pcb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]
2024-08-22 Update schematic for ESP32, split schematic sheets
    [Balancer+ESP.kicad_pcb, Balancer+ESP.kicad_sch, Bidirectional_Power_Converter_24V-12V_with_BMS.kicad_sch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]
2024-08-23 Add lcd display spi schematic, update tl494 boost converter
    [diode_probe.kicad_sch, power_supply.kicad_sch, shift_register_display.kicad_sch]
2024-08-26 Ideal diode + buck
    [bms.kicad_sch]
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2024-08-27 Fix bugs
    [esp32_measurment.kicad_sch, power_supply.kicad_sch]
2024-08-28 Add bidirectional smps concept, split bms schematic
    [BMC_microcontroller.kicad_sch, BMS_current_limiter.kicad_sch, BMS_current_sources_and_fans.kicad_sch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]
2024-08-30 add simulations, split bms and esp schematics
    [BMC_microcontroller.kicad_sch, BMS_current_limiter.kicad_sch, BMS_current_sources_and_fans.kicad_sch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]
2024-08-30 Add simulations and recheck schematics + cleanup
    [BMC_microcontroller.kicad_sch, BMS_current_limiter.kicad_sch, BMS_current_sources_and_fans.kicad_sch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]
2024-09-03 Add aditional 7 segment displays
    [DC_line_module+Meter_probe.kicad_pcb, display.kicad_sch]
2024-09-03 Chceck and update DC module and meter probe pcb
    [BMS_current_limiter.kicad_sch, BMS_current_sources_and_fans.kicad_sch, BMS_microcontroller.kicad_sch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]
2024-09-03 MPPT LT3652 schematic uptade
    [LT3652_MPPT.kicad_sch]
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2024-09-05 lt3252 circut simulation and update schematic
    [LT3652_MPPT.kicad_sch]
2024-09-09 part placement of bms pcb
    [BMS_current_limiter.kicad_sch, BMS_current_sources_and_fans.kicad_sch, Balancer.kicad_pcb]
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2024-09-11 Splitter PCB, connectors esp board
    [ESP32_master.kicad_pcb, ESP_32_energy_meters_probe.kicad_sch, LT3652_MPPT.kicad_sch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]
2024-09-13 Gas sensor circuit improvement
    [esp32_measurment.kicad_sch]
2024-09-15 Balancer PCB parts positions
    [Balancer.kicad_pcb]
2024-09-18 Splitter and connector footprints, progress with balancer pcb routing
    [BMS_current_limiter.kicad_sch, BMS_current_sources_and_fans.kicad_sch, BMS_microcontroller.kicad_sch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]
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2024-09-27 Update of ESP32 PCB - parts positioning
    [BMS_microcontroller.kicad_sch, Balancer.kicad_pcb, ESP32_master.kicad_pcb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]
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2024-10-01 ESP PCB Route progress
    [ESP32_master.kicad_pcb, ESP_32_energy_meters_probe.kicad_sch, esp32_measurment.kicad_sch]
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2024-10-02 corase routing for esp doce
    [ESP32_master.kicad_pcb, esp32_measurment.kicad_sch]
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2024-10-03 ESP relay circut change
    [ESP32_master.kicad_pcb, esp32_measurment.kicad_sch]
2024-10-03 Change MAX232 to MAX3232
    [ESP32_master.kicad_pcb, esp32_measurment.kicad_sch]
2024-10-04 Add misc shift register for display schematic, ideal bridge and sd card switcher
    [Bidirectional_Power_Converter_24V-12V_with_BMS.kicad_sch, Misc_PCB.kicad_pcb, Misc_PCB.kicad_sch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]
2024-10-06 add misc board schematic
    [Misc_PCB.kicad_sch, sd_card_switcher_sch.kicad_sch]
2024-10-07 Add SD card switcher circuit, some changes in pcb and schematic
    [Balancer.kicad_pcb, ESP32_master.kicad_pcb, ESP_32_energy_meters_probe.kicad_sch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]
2024-10-07 add power tracking heater
    [LT3652_MPPT.kicad_sch, MPPT.kicad_pcb, MPPT.kicad_sch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]
2024-10-08 progress with esp power pcb
    [Balancer.kicad_pcb, ESP32_master.kicad_pcb, LT3652_MPPT.kicad_sch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]
2024-10-09 Shift register for LCD update
    [Misc_PCB.kicad_pcb, shift_register_display.kicad_sch, shift_register_display_2x16.kicad_sch]
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2024-10-10 update power tracking heater
    [LT3652_MPPT.kicad_sch, Misc_PCB.kicad_pcb, power_tracking_heater.kicad_sch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]
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2024-11-11 Add first sw project for balancer, add new revision of balancer pcb
    [BMS_current_limiter.kicad_sch, BMS_current_sources_and_fans.kicad_sch, BMS_microcontroller.kicad_sch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]
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2024-11-17 balancer code - balancing 12v batt, apply .gitignore rules
    [bom.csv, designators.csv, positions.csv]
2024-12-01 change with balancer schematic, generate code for avr
    [BMS_current_sources_and_fans.kicad_sch, BMS_microcontroller.kicad_sch, Balancer.kicad_pcb]
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2025-05-20 update balancer pcb - add gnd vdrop opamp
    [BMS_current_sources_and_fans.kicad_sch, BMS_microcontroller.kicad_sch]
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2025-06-05 Update balacer schematic - change fan drive circuit, fix current limiter drive
    [BMS_current_limiter.kicad_sch, BMS_current_sources_and_fans.kicad_sch, BMS_microcontroller.kicad_sch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]
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2025-06-13 balancer pcb change smps diode footprint, schematic cleanup, designators arrangement, add mouting holes
    [BMS_current_limiter.kicad_sch, BMS_current_sources_and_fans.kicad_sch, BMS_microcontroller.kicad_sch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]
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2025-10-16 Done balancer and current limiter pcb, other pcb cleanup
    [BMS_current_limiter.kicad_sch, BMS_current_sources_and_fans.kicad_sch, BMS_microcontroller.kicad_sch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]
2025-11-02 fix pcb esp32 master, change esphome pinout
    [ESP32_master.kicad_pcb, ESP32_master.kicad_sch, ESP_32_energy_meters_probe.kicad_sch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]
